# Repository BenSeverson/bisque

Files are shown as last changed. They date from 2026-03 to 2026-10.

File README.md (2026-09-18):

<p align="center">
  <picture>
    <source media="(prefers-color-scheme: dark)" srcset="docs/logo-banner-dark.svg" />
    Bisque — Open-source ESP32-S3 ceramic kiln controller
  </picture>
</p>

<p align="center">
  
  
  
</p>

<p align="center">
  <a href="https://benseverson.github.io/bisque/"><b>▶ Try the live web UI demo</b></a> — interactive, no hardware required
</p>

## Features

**Temperature Control**
- PID controller with auto-tuning (Ziegler-Nichols relay method)
- 1-second control loop with time-proportional SSR output
- Thermocouple calibration offset

**Firing Profiles**
- Up to 20 custom profiles with 16 segments each (ramp rate, target temp, hold time)
- Orton cone firing (cones 022-13) with slow, medium, and fast heating speeds
- Delayed start

**Safety**
- Over-temperature protection (hardware max 1400 C, user-configurable limit)
- Thermocouple fault detection (open circuit, short to GND/VCC)
- Rate-of-rise monitoring (detects runaway >2x programmed rate)
- Not-rising detection (alerts if <10 C rise in 15 min)
- Emergency stop with immediate SSR cutoff

**Web Dashboard**
- Real-time temperature chart with profile overlay (React + Recharts)
- Profile builder with cone fire mode
- Firing history with CSV trace export and cost estimation
- Settings: calibration, safety limits, webhooks, API token

**iOS App**
- Full remote control (SwiftUI)
- Finds the kiln on your Wi-Fi automatically (Bonjour), no IP address to type
- Dynamic Island live activities during firing
- Local notifications for firing complete/error

**LCD Display**
- 4.0" TFT (480x320) with LVGL, adaptive single-screen dashboard (idle/active/paused/complete/error)
- 5-way nav switch (up/down/select/left/right), SELECT-driven modals for profile pick and firing control

**Connectivity**
- Wi-Fi with mDNS (`bisque.local`)
- REST API with optional bearer token auth
- WebSocket for real-time streaming
- Webhook notifications (firing complete/error)

## Screenshots

**Web Dashboard** (React)
<p align="center">
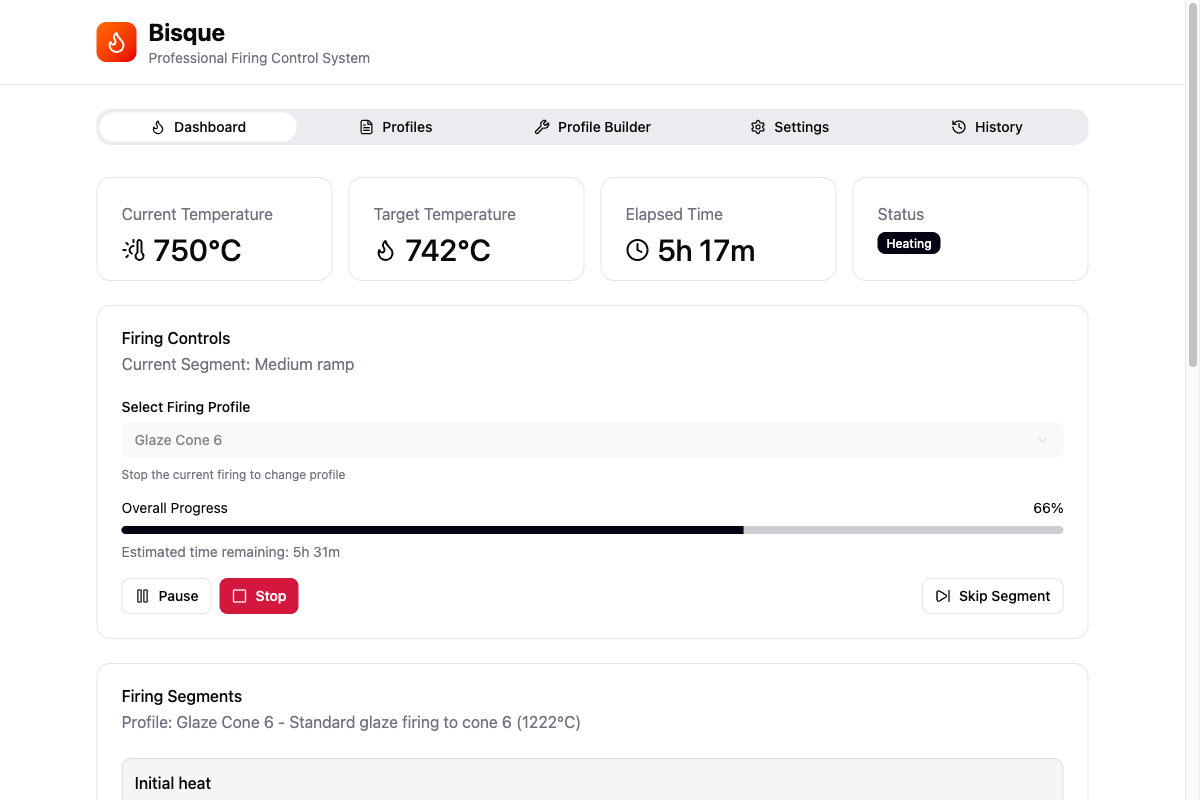
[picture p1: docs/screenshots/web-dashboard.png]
Web dashboard showing live firing progress
  
</p>

**LCD Display** (LVGL on 4.0" TFT)
<p align="center">
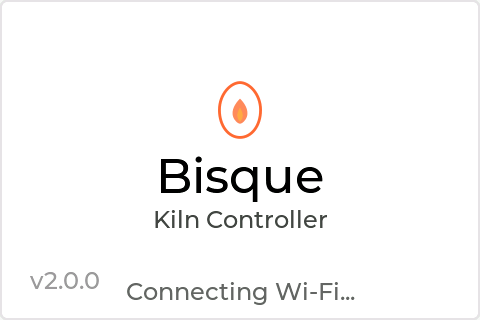
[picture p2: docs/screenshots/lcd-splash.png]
Boot splash
  
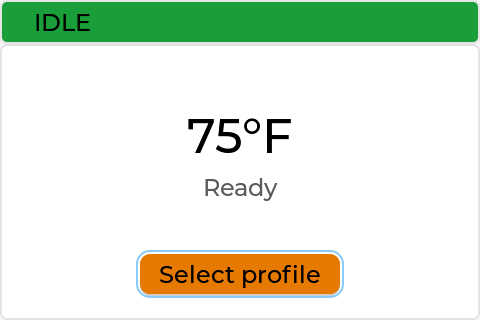
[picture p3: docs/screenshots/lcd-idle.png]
LCD idle
  
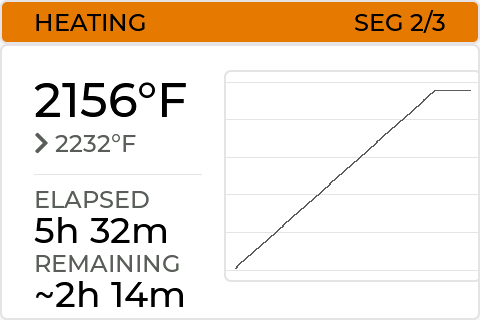
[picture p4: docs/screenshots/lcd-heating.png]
LCD heating
  
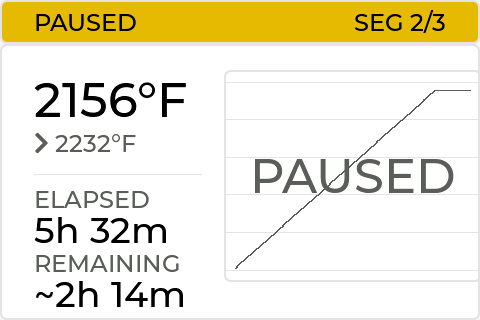
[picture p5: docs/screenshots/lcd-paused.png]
LCD paused
  
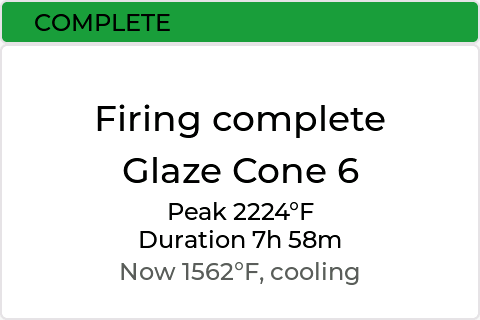
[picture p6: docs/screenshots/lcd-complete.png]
LCD complete
  
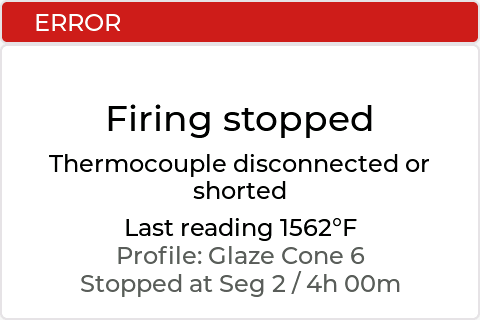
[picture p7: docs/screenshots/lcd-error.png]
LCD error
  
</p>
<p align="center">
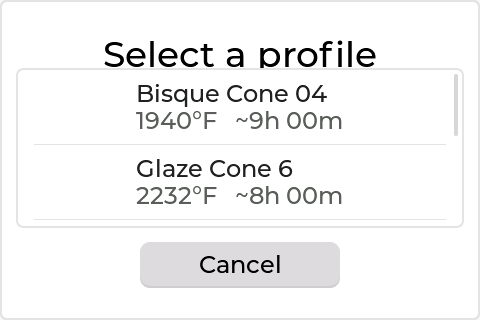
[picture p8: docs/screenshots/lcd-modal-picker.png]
Profile picker modal
  
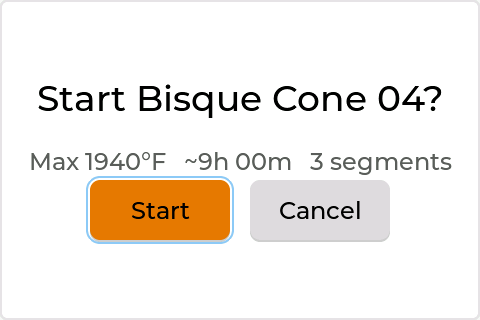
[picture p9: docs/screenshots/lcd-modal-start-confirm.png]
Start confirm modal
  
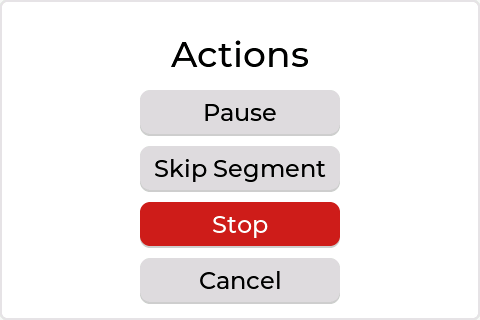
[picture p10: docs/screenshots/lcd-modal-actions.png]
Action menu modal
  
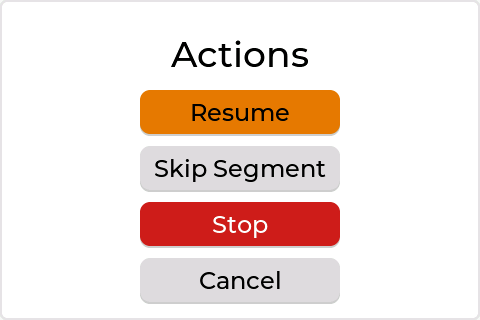
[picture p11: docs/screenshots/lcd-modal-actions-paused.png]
Action menu modal (paused)
  
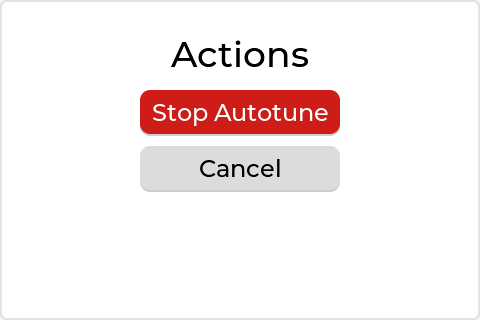
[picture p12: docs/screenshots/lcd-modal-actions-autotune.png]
Action menu modal (autotune)
  
</p>

**iOS App** (SwiftUI)
<p align="center">
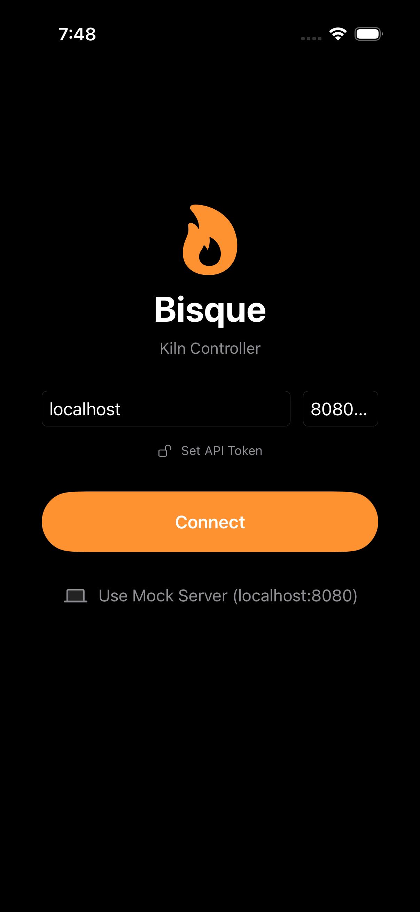
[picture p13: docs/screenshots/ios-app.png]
iOS app
  
</p>

## Hardware

The controller is a single board in [`hardware/kicad/`](hardware/kicad/) — a full KiCad project (schematic + routed **4-layer** board, 100 × 100 mm). Its GPIO map is [`docs/pin-assignments.md`](docs/pin-assignments.md).

<p align="center">
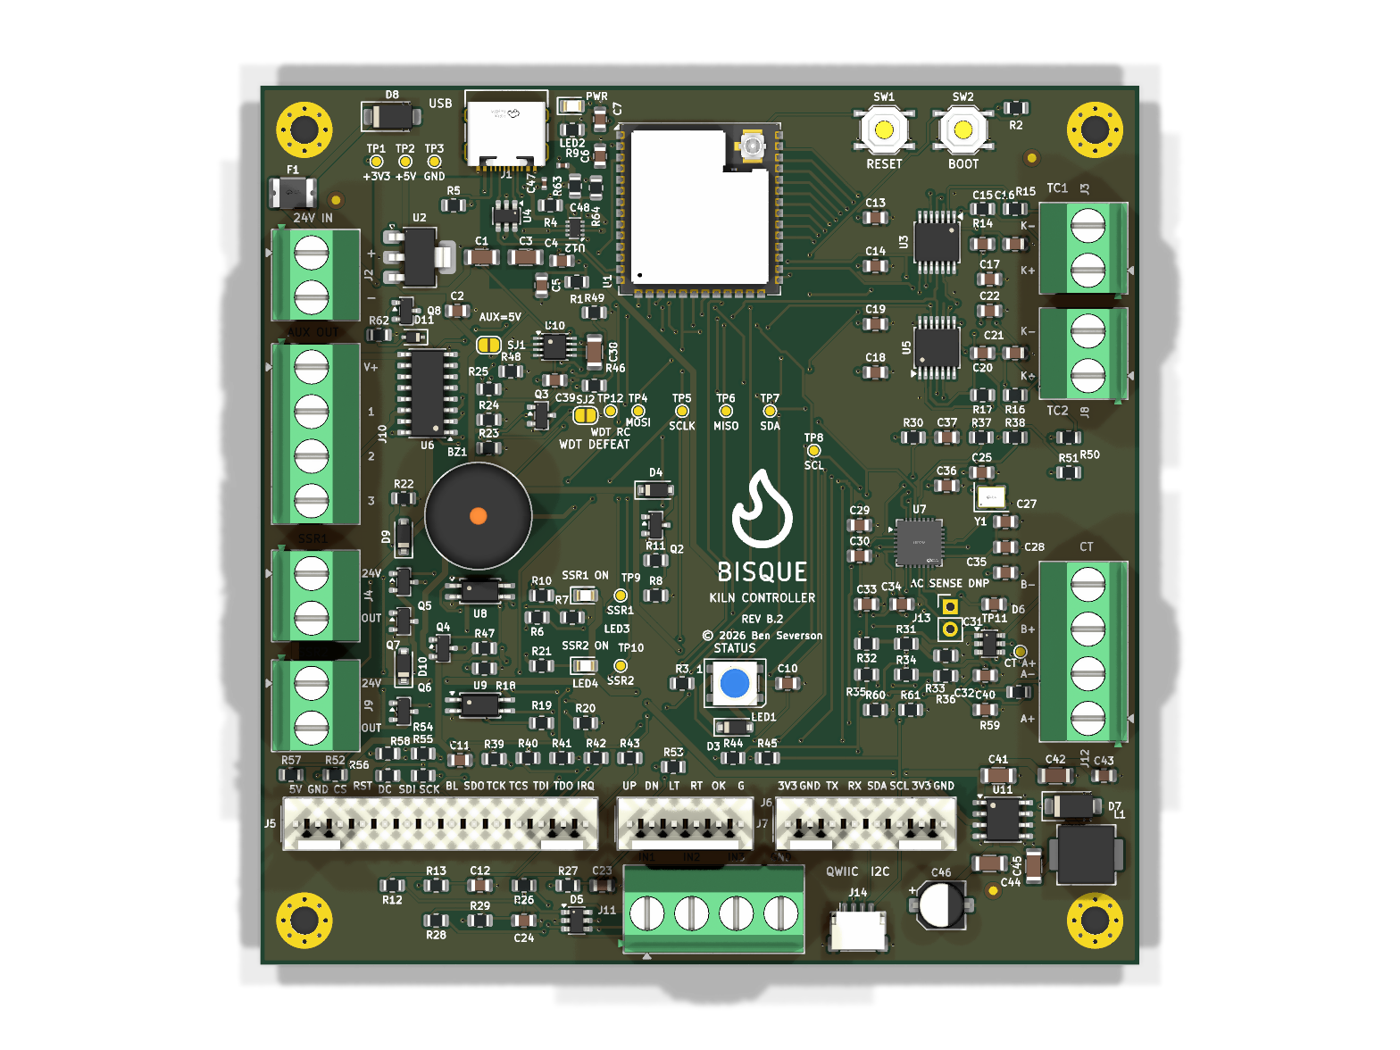
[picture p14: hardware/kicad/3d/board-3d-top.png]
Raytraced top-down render of the Bisque controller PCB
  
</p>

It integrates the ESP32-S3-WROOM-1U module (external U.FL antenna), two MAX31856 thermocouple front-ends, two SSR drive channels behind a hardware watchdog, an ADE7953 current-sense front-end, a ULN2003 auxiliary output bank, three protected dry-contact inputs, USB-C flashing, status LED, and alarm buzzer — with screw terminals for the field wiring and keyed connectors for the display and nav-switch looms. Gerbers, drill files, and an assembly BOM/CPL are committed and ready to upload to a board house.

See [`hardware/kicad/README.md`](hardware/kicad/README.md) for the full BOM, fabrication notes, and the regeneration workflow. GPIO assignments mirror the firmware's `Kconfig` defaults, so stock firmware runs unmodified.

[`hardware/enclosure/`](hardware/enclosure/README.md) documents a complete enclosure build around an off-the-shelf wall-mount steel box — layout, SSR thermal sizing, mains/SELV segregation, and a printable 1:1 drill template for the door.

> **Safety warning:** Kilns operate at dangerous temperatures and voltages. Ensure all high-voltage wiring is performed by a qualified electrician. Use appropriate safety equipment and never leave a firing kiln unattended.

## Getting Started

### Prerequisites

- [ESP-IDF v6.1](https://docs.espressif.com/projects/esp-idf/en/v6.1/esp32s3/get-started/)
- Node.js 18+
- [XcodeGen](https://github.com/yonaskolb/XcodeGen) (for iOS development)

### Dev Container (recommended)

The fastest way to a reproducible toolchain is the VS Code dev container — it
pins the exact ESP-IDF v6.1 image CI uses plus Node 24, the static-analysis
tools, and the Claude Code CLI. Open the repo in VS Code and run **Dev
Containers: Reopen in Container**. Everything below (firmware build, web UI,
`make ci`) then works in the container terminal; only flashing needs a bench.
See [docs/devcontainer.md](docs/devcontainer.md).

### Firmware

```bash
# Build web UI assets first
cd web_ui && npm install && npm run build && cd ..

# Gzip assets for SPIFFS
gzip -k -9 spiffs_data/www/assets/*.js spiffs_data/www/assets/*.css

# Build and flash firmware
source ~/.espressif/v6.1/esp-idf/export.sh
idf.py build
idf.py flash monitor
```

### Web UI Development

```bash
cd web_ui
npm install
npm run dev    # Starts dev server with mock kiln simulator
```

### iOS App

```bash
# Generate Xcode project
cd ios/Bisque
xcodegen generate
open Bisque.xcodeproj
```

For simulator testing, start the mock server first:

```bash
cd web_ui && npm run mock-server   # HTTP + WebSocket on localhost:8080
```

In the iOS simulator, tap "Use Mock Server" on the connection screen.

<details>
<summary><strong>Simulator / Mock Server</strong></summary>

A mock kiln server simulates the full API (status, profiles, firing, settings, history, autotune, diagnostics) with realistic temperature physics so you can develop and test without hardware.

### Web UI development

The mock server runs automatically as a Vite plugin when you start the web UI dev server:

```bash
cd web_ui
npm run dev
```

The mock is enabled by default. To disable it and proxy to a real kiln instead:

```bash
VITE_MOCK=false npm run dev
```

Control simulation speed with `VITE_MOCK_SPEED` (default `60` = 60x real-time):

```bash
VITE_MOCK_SPEED=120 npm run dev
```

### iOS app development

A standalone mock server is available for testing the iOS app in the Xcode simulator:

```bash
cd web_ui
npm run mock-server
```

This starts an HTTP + WebSocket server on `localhost:8080`. To change the port or simulation speed:

```bash
MOCK_PORT=9000 MOCK_SPEED=120 npm run mock-server
```

### LCD Simulator

A standalone SDL2-based simulator renders the LVGL display UI on your desktop:

```bash
cd simulator
cmake -B build && cmake --build build
./build/bisque_sim
```

Requires SDL2 (`brew install sdl2` on macOS).

</details>

## Architecture

```
main/                 App entry point, FreeRTOS task creation
components/
  app_config/         Pin definitions, hardware constants
  thermocouple/       MAX31856 SPI driver (2 channels)
  pid_control/        PID controller + Ziegler-Nichols auto-tune
  firing_engine/      Multi-segment firing state machine
  safety/             Watchdog, over-temp, fault detection
  cone_table/         Orton cone temperature lookup (022-13)
  history/            Firing history + temperature traces (NVS)
  display/            ST7796S LCD + LVGL UI (adaptive dashboard)
  web_server/         REST API + WebSocket server
  wifi_manager/       Wi-Fi STA/AP + mDNS
web_ui/               React/TypeScript web dashboard
ios/Bisque/           SwiftUI iOS app
simulator/            LVGL SDL2 desktop simulator
tests/host/           Pure-logic + accelerated firing unit tests (CMake/Unity)
docs/                 Wiring diagrams, screenshots, bench smoke test
```

## Testing

CI runs five automated test layers on every PR — pure-logic unit tests
and accelerated firing scenarios (`tests/host/`), a UI screenshot
regression suite (`simulator/ --diff`), web UI unit tests, and a
cross-language API contract test that validates firmware JSON output
against the frontend's zod schemas.

Before tagging a release, run the [bench smoke test](docs/bench-smoke-test.md) — a 3-8 minute hardware
run that verifies the parts CI can't touch: real SSR clicks, real
thermocouple readings, history persistence across reboot.

## Network security

**Bisque assumes the network it sits on is trusted.** It is a LAN-only
device: the HTTP API and the WebSocket telemetry feed are plain `http://`
and `ws://`, with no TLS. Anyone who can see traffic on the same Wi-Fi can
read the API token and every command sent with it.

The optional API token (Settings → API Token) is therefore a lock on the
front door, not protection against a hostile network. It stops a
housemate's laptop or a curious guest from starting a firing; it does not
stop someone who is already capturing your Wi-Fi traffic. Concretely:

- The token is sent as an `Authorization: Bearer` header on every REST
  request and compared in constant time on the device.
- The WebSocket telemetry feed (`/api/v1/ws`) is authenticated by the same
  check as the REST API. Browsers cannot set headers on a WebSocket
  handshake, so the web UI presents the token as a `?token=` query
  parameter instead — which means that on this one route the credential does
  reach anywhere the URL does, including proxy logs and browser history. The
  iOS app uses `URLSession`, which can set the header, and does. Dropping the
  query parameter would lock every browser out of live telemetry, so it is a
  deliberate trade rather than an oversight.
- Firmware updates are fetched over HTTPS with certificate validation
  against the bundled root store, and the downloaded image is checked
  against the SHA-256 in the release manifest. So an OTA is not exposed by
  the local network being readable — its trust rests on GitHub's TLS, not on
  your LAN.

If that trust assumption does not hold for your network, put the kiln on an
isolated VLAN or guest SSID rather than relying on the token. TLS on-device
with certificate pinning in the clients has been considered and is tracked
in [#149](https://github.com/BenSeverson/bisque/issues/149); it is a
significant amount of firmware and app complexity for a home LAN, and has
not been implemented.

**Never expose a kiln controller directly to the internet.** No port
forwarding, no DMZ. This is a device that applies mains power to a heating
element in an unattended room.

## Releases

Firmware is distributed as [GitHub Releases](https://github.com/BenSeverson/bisque/releases),
each with a full ESP32-S3 flash kit and Sigstore build-provenance
attestations. See [RELEASING.md](RELEASING.md) for the versioning scheme and
the procedure for cutting a release.

## License

[MIT](LICENSE)

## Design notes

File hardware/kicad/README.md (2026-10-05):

# Bisque Kiln Controller — KiCad PCB

The controller board. This is **rev B**, a respin of the original prototype
rather than a variant — it replaced the thermocouple front-end with an
incompatible part, added a second SSR zone and a digital current-sense chip,
moved most GPIOs, and swapped the module variant.
4-layer, 100 × 100 mm, built for **JLCPCB assembly**: 0805 passives,
QFN/TSSOP/SOIC/SOT ICs, SMD tact switches and the ESP32-S3-WROOM-1U module's
castellated pads all go down the SMT line, plus thirteen through-hole parts
(terminals, wafers, buzzer) fitted by hand — see "Fabrication & assembly"
below for why that split is much cheaper than it looks. The design record for
this respin, including the routing escalation that forced the layer count,
is `docs/superpowers/specs/2026-08-10-pcb-rev-b-hardware-design.md`; the
fab-readiness sign-off is `FAB-READINESS-REVIEW-REVB.md`.

Built and validated with **real KiCad** (10.0.5, pcbnew Python API +
kicad-cli): footprints come from KiCad's installed libraries, ground/power
plane pours are filled and checked by `kicad-cli pcb drc --refill-zones` —
**zero errors, zero unconnected, zero warnings**
(`bisque-controller-drc.rpt`) — and the schematic passes a netlist round-trip
check (KiCad's exported netlist diffed against the design's connectivity
table — 92 nets, 0 mismatches). The 3D renders in `3d/` are raytraced by
`kicad-cli pcb render` with the official component models.

| File | What it is |
|---|---|
| `bisque-controller.kicad_pro` | Project. Hand-maintained **except** two blocks, both derived and both written *after* the board is saved because `pcbnew.SaveBoard()` blanks them: `schematic.top_level_sheets` (`gen_sch.py::sync_project()`) and `net_settings` (`gen_pcb.py::sync_netclasses()`, from `ROUTE_ORDER`) — see below |
| `bisque-controller.kicad_sch` | Schematic (A1, netlist-style: functional groups, global labels for signals, real power ports for rails, and real wires for two-pin nets local to one block). Laid out programmatically by `generator/gen_sch.py` — a `GROUPS` taxonomy plus a deterministic column packer, with a reserved right-hand column for the notes block. A1, not A3: an A3 declaration silently clipped ~40% of the circuit out of the exported PDF while every connectivity checker stayed green (`generator/check_sch_bounds.py` now fails on any off-sheet item), and containment is not readability, so `generator/check_sch_layout.py` additionally fails on any symbol/symbol, text/symbol, text/text or wire/wire collision (wires: a T or a collinear overlap — a plain crossing is allowed) |
| `bisque-controller.kicad_pcb` | Board: placed, fully routed, 4 layers (F.Cu/B.Cu signals, In1.Cu GND plane, In2.Cu +3V3 plane), on JLCPCB's `JLC04161H-7628` 1.6 mm stack-up — see "The physical stack-up" |
| `bisque-controller.kicad_dru` | JLCPCB's standard 4-layer process as KiCad custom rules — **not generated**, and not a statement of design intent: every limit in it is JLC's *absolute minimum*, so a violation means something slipped off the design's own floor (0.3 mm track, 0.2 mm clearance, 0.6/0.3 vias, all from `net_settings`) far enough to hit the fab's. KiCad reads it by project name, so it survives regeneration untouched and the existing `kicad-cli pcb drc` pass picks it up for free — see "Fabrication & assembly at JLCPCB" |
| `3d/board-3d-*.png` | Raytraced renders, kicad-cli — straight orthographic **top** and **bottom** only. The angled iso/front views were dropped: they look better than they read, and these images get used to check placement and silk, not to advertise |
| `bisque-controller-drc.rpt` | KiCad DRC report, now including the `.kicad_dru` rules above (0 errors, 0 unconnected, 0 warnings — the 109 silkscreen warnings went with the silk packer, see "Regenerating the files") |
| `gerbers/` | Fabrication outputs (kicad-cli: F.Cu, B.Cu, **In1.Cu, In2.Cu**, paste/silk/mask, Edge.Cuts, Excellon drill + job file) |
| `pdf/` | Schematic and board PDFs (kicad-cli) |
| `jlcpcb/` | The complete JLCPCB upload: `gerbers.zip` for fabrication, BOM + CPL for assembly, plus the hand-solder shopping list and `mouser-order.csv` |
| `generator/` | Scripts that build everything from one connectivity table |

## Opening it

Open `bisque-controller.kicad_pro` in KiCad 10 or newer (the board file
format and pcbnew API this generator uses require it — see "Regenerating the
files"). Zones ship **filled** (KiCad's own filler) and the board already
passes KiCad DRC; re-run it after any edit. The schematic embeds its
symbols; the board references the standard KiCad footprint libraries (and
was generated from them), plus the four vendored models in `3dmodels/`.

**Opening the project used to dirty it.** KiCad records the root sheet under
`schematic.top_level_sheets` in the `.kicad_pro` and writes that block itself
the first time anything touches the project — and what it writes depends on
who wrote it. The GUI knows the schematic's real root uuid; `kicad-cli pcb`
fills all-zeros, because the PCB tooling never loads a schematic and has no
uuid to record. So the file grew an unexplained diff after a regen and could
flip between two values depending on which tool ran last.

`project_sync.py::sync_project()` (shared by `gen_sch.py` and `kicad_build.py`) now derives the entry from the same `ROOT`
constant the schematic's own `(uuid ...)` comes from, and runs on every
`pcb-build` / `pcb-cosmetic`. Whoever opens the project next finds it already
correct and leaves it alone — kicad-cli only ever *adds* the block when it is
missing and preserves a populated one, which is what makes deriving it
sufficient rather than a tug-of-war. The rewrite is a whole-file json
round-trip, safe because KiCad emits plain 2-space-indented JSON that
re-dumps byte for byte; do not replace it with a hand-rolled text patch.

## What's on the board

- **U1 — ESP32-S3-WROOM-1U-N16R2** module (16 MB flash / 2 MB **quad**
  PSRAM — matches `sdkconfig.defaults`' `CONFIG_SPIRAM_MODE_QUAD` + the
  16 MB OTA partition table), at the top edge. The **1U** variant carries a
  **U.FL connector for an external antenna** rather than the standard
  WROOM-1's on-package PCB antenna: a kiln controller mounts on or near a
  large grounded steel enclosure, which makes a PCB antenna close to
  non-functional, and the 1U's antenna can be placed on a pigtail somewhere
  that actually radiates. It also reclaims the ~330 mm² antenna keep-out
  band the WROOM-1 footprint would require — freed for parts and ground
  pour on a board that turned out to need every square millimeter (see
  "Density and the 4-layer stack-up" below). **The U.FL pigtail (U.FL → SMA
  bulkhead) and the 2.4 GHz antenna are accessories, not BOM lines** — buy
  them separately (see the hand-solder/shopping-list note below) and drill
  an SMA bulkhead hole in the enclosure. U.FL is rated for ~30 mating
  cycles, so treat the connection as assemble-once, not a field-serviceable
  connector.

  **Certification caveat.** Espressif's modular certification for the
  WROOM-1U is granted against specific antenna types and gains. Fitting a
  non-approved (e.g. high-gain) antenna steps outside that approval — see
  `CERT-001` in `FAB-READINESS-REVIEW-REVB.md`. Use an antenna within the
  certified list unless you're prepared to re-certify.

- **Power**: 24 V DC in on screw terminal **J2** (top-left) *or* USB-C.
  The 24 V side runs J2 → F1 (750 mA/33 V resettable fuse) → D8 (SMAJ30A TVS)
  → **Q8** (AO3401A P-FET, reverse polarity) → **U11**, an XL1509-5.0 buck in
  the south-east corner that makes `BUCK_5V`; **U12** (TPS2116) then selects
  between `BUCK_5V` and USB VBUS to make `+5V`, and a **TLV1117LV33**
  (U2, SOT-223) drops that to 3V3.
  Regulating rather than dropping is the point: +5V used to be literally the
  input minus a Schottky, so every diode drop and every turn of the
  installer's trim pot landed on the WS2812B threshold, the SSR drive and the
  relay coil at once. Both of the board's remaining series diodes are now
  gone with it — the reverse-polarity SS34 is Q8 (~39 mV instead of ~0.4 V,
  which matters because `VIN_P` feeds both 24 V SSR terminals as well as the
  buck) and the USB ORing SS34 is U12 (~40 mΩ).

  **U12 runs in priority mode, not highest-voltage-wins, and that is the
  whole reason it is a mux and not an ideal diode.** A 5.25 V USB host is
  higher than a 5.0 V buck, so a plain ORing part would let a laptop source
  the relay bank and both SSR terminals; the diode used to prevent that for
  free by dropping. MODE ties to VIN1 and R63/R64 divide `BUCK_5V` into PR1
  with a 4.0 V threshold, so the buck wins whenever it is up. U12 also
  blocks USB back-feeding the unpowered buck, which closes fab-review
  finding **C1** (5 V on U11's FB and switch pins during every USB-only
  flashing session). Its ST pin is left unconnected on purpose — see
  `design.py` at U12 for why that GPIO is not worth the route.

  `BUCK_5V` and `+5V` are deliberately separate nets: C44/C45/**C46** are the
  buck's compensation (C46 is the electrolytic supplying the ESR zero) and
  belong on the buck's side of the mux, not the load's.
  Power LED (green) on 3V3. The display (below) draws from +5V directly, not
  through U2 — its backlight and panel logic were the dominant unmodeled load
  on the LDO, and moving them off keeps U2's junction temperature comfortably
  under its 125°C limit even at a hot enclosure ambient. The +3V3 rail also
  now lives on its own **inner plane** (In2.Cu) rather than a surface pour —
  see the stack-up note below.
- **Thermocouples ×2**: **MAX31856MUD+** (U3 channel 1 / U5 channel 2,
  TSSOP-14), K-type on screw terminals **J3** (channel 1) / **J8** (channel
  2), each with its datasheet-specified differential + common-mode input
  filter, sharing the SPI bus (MISO + its own CS: GPIO 10 / GPIO 35). This
  replaces rev A's single MAX31855KASA+ entirely — the two parts are not
  pin-compatible, and no attempt was made to support both on one board.

  **Ungrounded-junction thermocouple probes are required.** Both MAX31856s
  reference their T− input to board ground. Two grounded-junction probes
  sharing one kiln chamber would form a ground loop through the kiln body
  itself; use ungrounded-junction (isolated-tip) K-type probes on both
  channels. This is a documentation obligation, not something the board
  enforces electrically.
- **SSR drive ×2, 24 V opto-driven low-side MOSFET**: screw terminals **J4**
  (zone 1) / **J9** (zone 2), each **pin 1 = `VIN_P`** (24 V, fused and
  TVS-clamped, **always live**) and **pin 2 = the switched low side**
  (`SSR1_OUT` / `SSR2_OUT`). Per channel: GPIO → 220 Ω → the LED of an
  TLP291 (**U8** zone 1, **U9** zone 2) → GND; the opto's collector sits on
  `SSR_EN` (+5 V) and its emitter drives the gate of a **CJ2310** (**Q5** /
  **Q6**), a 60 V logic-level N-channel MOSFET, with a **10 kΩ gate pulldown**
  (R7/R20). Both channels return through **Q7**, a third CJ2310 that is the
  watchdog's gate (see below). An amber indicator LED + 4.7 kΩ sits across
  each terminal pair, so it lights only when the channel is actually
  conducting. **D9**/**D10** freewheel each terminal for inductive loads. The
  board supplies the SSR control loop. (The SSRs themselves and all mains
  wiring stay outside this board.)

  **Current budget, and it is a limit rather than a note.** F1 holds at
  750 mA and U11 takes ~250 mA of it, so the two channels share ~400 mA. Two
  SSR inputs plus their indicators is ~40 mA, a 10× margin; one small DC
  contactor coil per channel fits; two large ones do not.

  **The optocouplers are containment, not isolation, and that distinction is
  load-bearing.** Rev B opto-*isolated* both channels — dry-contact terminals,
  a four-layer pour keepout across the opto row, `SJ3`/`SJ4` to tie each
  collector to board +5 V, and `check_isolation.py` — and that was **reversed**
  before fab, because an optocoupler only isolates if the SSR control loop is
  powered from a supply that is *not this board*, and this board's is.
  **That reasoning still stands and is not being overturned.** These terminals
  are still board-powered, both sides still share `GND`, and there is still no
  pour keepout, no router keepout, no rule area and no `check_isolation.py`.
  Do not re-add any of them; read commit `93a31d7` first.

  What changed is the failure the parts are bought for. At 5 V, a channel
  MOSFET failing gate-to-drain put 5 V through 100 Ω into a GPIO and the
  ESP32's clamp survived it. At 24 V the same single failure puts ~240 mA into
  that clamp and takes the module with it. The opto removes the conductor: the
  only thing the MCU touches is an LED. It is also not more parts than the
  alternative — a gate-to-GND zener contains the same fault for the same one
  part per channel, but contains it *by conducting*, so it has to survive the
  fault to work and fails open silently.

  **The opto is a TLP291 in SOP-4, not the LTV-817S this started as, and the
  reason is geometry.** The SMD-DIP4 body is 12.04 mm across its courtyard;
  the corridor between `J4`/`J9` and the rest of the block is ~5.5 mm and has
  to carry both these parts and the four per-terminal legends (`24V`/`OUT`,
  each locked to its own screw's y and free only in x). A 12 mm opto leaves
  those legends nowhere to go, and they print on the terminal body — three
  `check_silk` failures that no amount of re-spacing fixes, because the
  corridor is simply too narrow. At 8.50 × 3.10 mm it opens to ~6.7 mm.
  It costs one Extended feeder where the LTV-817S was Basic, and buys 80 V
  `V_CEO` against 35 V, which is free margin on a 24 V board.

  The 220 Ω is sized against the ESP32's **guaranteed** `V_OH`
  (0.8 × VDD = 2.64 V), not against 3.3 V: the opto's CTR bin is only
  specified at `I_F` = 5 mA and falls off steeply below it, and 330 Ω at that
  corner gives 4.7 mA. 220 Ω gives 7.0 mA there, 5.6 mA with `V_F` also at
  its maximum, and 10.0 mA typical — half the ESP32's recommended source
  current.

  The collector sitting on the **5 V** rail rather than on 24 V is deliberate:
  an emitter follower into R7 saturates, so the gate lands at
  `5 V − V_CE(sat)` ≈ 4.8 V — set by the rail, not by the opto's CTR. Run the
  collector from 24 V instead and the gate goes to ~24 V, past the MOSFET's
  ±20 V `V_GS`, and you need a zener to get back to where the 5 V rail
  already was for free.

  **Hardware watchdog (`SJ2`, "WDT DEFEAT").** `SSR_EN` — since rev B.2 a
  +5 V **gate-drive** rail rather than the terminal supply — is supplied by
  Q4, a P-channel high-side MOSFET (AO3401A) whose gate node `SSR_PG` is held
  down by Q3, itself held on by **U10**, an SN74LVC1G123 retriggerable
  monostable driven from GPIO 36 (`WDT_KICK`); R47 (100 kΩ) pulls `SSR_PG` up
  as the fail-safe. `SSR_EN` feeds both opto collectors *and* Q7's gate, so
  when it collapses the channels open **two independent ways**: the optos lose
  their collector rail and Q7 loses its gate. **R18** (10 kΩ) is what makes
  that work — `SSR_EN` is Q4's *drain*, so with Q4 off nothing would define it
  and Q7's gate would float, which is the same fail-dangerous bug R49 exists
  to fix one node upstream.

  **Q7 is in the shared return, and it is not the "stacked low side" this
  design rejected.** The watchdog has to be able to open a channel whose
  MOSFET has failed *short* — the case a firmware-owned interlock cannot cover
  — so it stays in the load path. Keeping it on the high side at 24 V would
  need a 60 V P-channel switch (the only fee-free one at JLCPCB is a
  50 V/130 mA part that caps the terminals below their own current budget)
  plus a divider to hold its `V_GS` inside ±20 V off a rail that reaches 37 V
  while D8 clamps a sustained fault — putting the board's most safety-critical
  node on a divider referenced to the fault. Q7 does the same job with the
  same part as the channels and leaves U10/Q3/Q4/R47/SJ2 untouched in the 5 V
  domain. The rejected "topology A" made **Q3** the series element back when
  the charge pump could only lift its gate to 2.16 V, so its drop was
  unbounded; Q7 is a dedicated switch gated at ~5 V, where the CJ2310 is
  specified at 125 mΩ — 5 mV at 40 mA. The objection was to an unbounded drop,
  and this one has a datasheet line under it. **R22** (100 kΩ) pins `SSR_RTN`
  down so that with everything off it cannot drift to 24 V and put −24 V
  across Q5/Q6's gates. It is 100 kΩ rather than 10 kΩ because of the very
  fault the watchdog is in the load path *for*: with a channel MOSFET failed
  short and the window expired, R22 in series with the SSR's own ~1.2 kΩ
  input is all that is left, and 10 kΩ passes 2.1 mA — inside the trigger
  range of an SSR-40DA-class input. 100 kΩ passes 237 µA.

  Every **rising edge** on `WDT_KICK` restarts U10's window, so `Q` stays high
  only while firmware keeps kicking; a pin wedged at either level delivers no
  edge and expires the window exactly like a pin that stopped, which is the
  whole point. R46 (100 kΩ) and C38 (22 µF) set the window to **1.65–2.71 s**
  worst-case over −40…125 °C, every term of that bound a datasheet or
  purchase-tolerance figure. Firmware kicks at 5 Hz from the existing 100 ms
  SSR timer, gated on `safety_task`'s heartbeat
  (`components/safety/wdt_kick.h`) — 8.3× margin at the minimum window. R48
  (100 kΩ) holds `B` low whenever the MCU drives nothing, so a floating CMOS
  input cannot self-trigger the one-shot during boot ROM, flashing or reset.

  **This replaced a BAT54S diode charge pump, which did not work.** Solving its
  steady state exactly gives 0.63 V of gate drive at 5 Hz against Q3's 1.45 V
  threshold — and 0.84 V even in the typical corner, below the *typical* 1.0 V
  threshold. A faster kick (≥ 250 Hz) rescues the voltage but not the
  temperature behaviour: Schottky reverse leakage sits in the timing path and
  roughly doubles per 10 °C, so the budget for a transient firmware stall fell
  from 0.31 s at 25 °C to 0.11 s at 60 °C and vanished near 85 °C, next to a
  5 kW heat source. No choice of passives fixes a leak that *is* the timer;
  the fix was to stop building the timer out of one. Off-the-shelf watchdog
  supervisors (TPS3823, STWD100) were evaluated and rejected on output shape:
  they emit a fixed reset *pulse* per timeout, which would leave the heat rail
  energised 75–95 % of the time under dead firmware. They exist to reboot
  MCUs; gating a rail needs a level.

  On power-up, and on any board where nothing kicks GPIO 36, `SSR_EN`
  collapses and **both SSR channels stay off regardless of what the firmware
  commands them to do.** The silkscreened `SJ2` solder jumper shorts `SSR_PG`
  to GND, holding Q4 on and restoring un-gated behaviour for bring-up and for
  any build without the firmware kick. **A board with neither `SJ2` fitted nor
  a working kick will not heat** — this is the single most likely rev B
  bring-up surprise, more likely to be mistaken for a bad SSR or a
  lid-interlock problem than correctly diagnosed as "nobody is kicking the dog
  yet." `TP12` probes the timing node, which is where a scope settles the real
  window in one measurement. The watchdog gates only the two SSR channels;
  vent, purge, the spare aux channel and the buzzer are unaffected, so a
  stalled controller can still open its vent.
- **Display**: 14-pin Molex KK-254 friction-lock header **J5** for a 4.0"
  ST7796S SPI module (LCDWIKI MSP4021, 480×320, resistive touch) — grown
  from rev A's 8-pin display-only header to carry the panel's full pin set:
  the original 8 signal pins, the panel's `SDO` (pin 9, left unwired in rev
  A because the firmware never read from the display), and the five touch
  lines (pins 10–14). `T_CLK`/`T_DIN`/`T_DO` are electrically the shared
  SPI2 bus through 33 Ω series damping resistors (R39/R41/R42 — the bus now
  multi-drops the LCD at 40 MHz plus two MAX31856s and the touch controller
  at lower clocks); only `T_CS` (GPIO 5) and `T_IRQ` (GPIO 6) cost new
  dedicated GPIOs. The XPT2046 touch controller itself lives on the display
  module, not this PCB. VCC runs from +5V rather than +3V3, per the
  module's own manual and reference wiring diagrams, with no level shifter
  needed on CS/RESET/DC/MOSI/SCK.
- **Nav switch**: 6-pin KK-254 friction-lock header **J6** for the
  panel-mounted 5-way switch (`UP DN LT RT OK GND`, active-low, ESP32
  internal pull-ups) — now on GPIO 38–42, contiguous module pads, moved
  from the split GPIO 1/2/4/5/6 rev A used (routing simplification, see the
  hardware-design spec §3.1).
- **Aux header J7** (8-pin KK-254): `3V3 GND TX RX SDA SCL 3V3 GND` — UART0
  plus a 0.1" I2C tap (pins 5–8), alongside the Qwiic/STEMMA-QT connector
  **J14**. Rev A's `VENT`/`LID_SW`/`AUX_A`/`AUX_B` nets are gone from this
  header entirely: nothing on the board ever sourced `AUX_A`/`AUX_B` here
  (the real aux outputs are on J10, below), and the lid switch has its own
  terminal (J11).
- **Aux output bank — J10** (4-pin terminal): **AUX_VP** (external coil
  rail) plus three switched low sides (`AUX1_OUT` = vent, `AUX2_OUT`,
  `AUX3_OUT`), driven by a shared **ULN2003ADR** Darlington array (U6) with
  integrated freewheel diodes returning to `AUX_VP` — not the board's own
  +5V rail. A gas purge solenoid is realistically 12 V or 24 V DC; the
  ULN2003 is rated 50 V / 500 mA per channel, so `AUX_VP` is meant to be fed
  from an external coil supply. Solder jumper **`SJ1`** (open by default)
  ties `AUX_VP` to board +5V for anyone who only has plain 5V relays. Only
  channel 1 (vent) is driven by firmware today (`safety_update_vent()`);
  channels 2/3 are routed and declared in Kconfig (`KILN_PIN_AUX2`/`AUX3`)
  but undriven.
- **Protected inputs — J11** (4-pin terminal): `IN1`/`IN2`/`IN3` (lid, gas
  flow, spare) plus GND, each with the same conditioning rev A used for its
  single lid input — 1 kΩ series, 10 kΩ pull-up to 3V3, 100 nF to ground,
  dry-contact to GND — generalized to three channels. `IN1` (GPIO 4) is the
  lid switch and defaults to enabled, matching this board; see
  `docs/pin-assignments.md` §1 for the fail-safe wiring requirement if no
  switch is fitted. `IN2` (gas flow) and `IN3` (spare) are routed but have
  no firmware consumer yet.
- **CT current sensing — J12** (4-pin terminal, `CTA_P`/`CTA_N`/`CTB_P`/
  `CTB_N`): two current-transformer inputs into an **ADE7953** energy
  metering IC (U7, LFCSP-28, current-only — the voltage channel is unused),
  on the I2C bus with its own 3.579545 MHz crystal (Y1). Burden resistors
  (R31/R34, 5.1 Ω — full scale ~139 A rms, see `design.py`), anti-alias RC
  and an SRV05-4 TVS array (D5/D6) per
  channel protect the externally-exposed CT leads. One channel per SSR
  zone, so each element bank gets an independent current reading; with no
  mains voltage sensing on this board, power is estimated as
  `Irms × configured nominal mains voltage` (±3–5%), adequate for
  element-health diagnosis and cost estimation. The voltage-channel pins
  are routed to a **DNP** 2-pin SELV header (**J13**) for a possible future
  off-board isolated-AC accessory — not fitted, no mains anywhere on this
  PCB.
- **I2C expansion — J7 pins 5–8 and J14 (Qwiic/STEMMA-QT)**: `I2C_SDA`
  (GPIO 18) / `I2C_SCL` (GPIO 47), on-board pull-ups (R44/R45, 4.7 kΩ).
  Carries the on-board ADE7953 today; open for an RTC breakout, an SHT4x RH
  sensor, or an external ADC without board changes. No I2C driver exists in
  firmware yet.
- **USB-C (J1)** for native-USB flashing: 5.1 kΩ CC resistors, SRV05-4 (U4)
  ESD protection, VBUS ORed into +5 V. RESET (SW1) and BOOT (SW2)
  buttons.
- **Status LED**: WS2812B on IO48; its VDD comes through a 1N4148W drop
  diode (D3), putting VLED at ≈4.15 V so V_IH = 0.7·VLED ≈ 2.9 V stays
  comfortably under the 3.3 V data level. The diode is *silicon*, not the
  SS14 Schottky it replaced, and the reason is the buck: on a regulated
  5.0 V rail an SS14's ~0.3 V leaves VLED at 4.7 V and V_IH at 3.29 V —
  a 10 mV margin. The old rail sagged enough to hide that. What the
  regulator removes is the trade, not the drop: VLED no longer moves with
  the PSU, so a fixed drop is now a real fix rather than a hedge.
- **Alarm**: 12 mm active 5 V buzzer (BZ1) on IO7, its own discrete AO3400A
  (Q2) low-side driver with flyback diode — kept separate from the ULN2003
  aux bank on purpose, so a 5 V buzzer and a 24 V solenoid never share a
  COM rail.
- **Test points**: twelve 1 mm bring-up pads (TP1–TP12, no BOM/assembly
  cost) on +3V3, +5V, GND, the SPI bus, I2C SDA/SCL, both SSR gate nets,
  the CT burden node, and the watchdog hold node. Rev A shipped with none,
  which its fab review flagged as awkward for bring-up; at ~141 components
  and eleven subsystems, they stopped being optional.
- 4× M3 grounded mounting holes, one per corner, centers on a **90 × 90 mm
  rectangle** (5 mm in from each edge, grown from rev A's 90 × 70 mm as the
  board grew from 100 × 80 mm to 100 × 100 mm) for easy enclosure drilling.

### Density and the 4-layer stack-up

Rev B roughly triples rev A's component count (52 → 141) on the same
100 × 100 mm footprint rev A used at 80 mm tall. `generator/router.py`'s
2-layer octilinear grid autorouter could not close the board: a rung-by-rung
escalation (0805 → 0603 passives, then a 125 × 100 mm board) knocked
unroutable nets down from 34 to 23 to 9, but the survivors were short local
nets boxed in by neighbours' copper in the SSR driver cluster and the
ADE7953 block — the signature of a **layer** shortage, not an area shortage.
Going 4-layer (an unbroken GND plane on In1.Cu, a +3V3 plane on In2.Cu — In2
carries +3V3 alone rather than splitting with +5V, since +5V's own consumers
don't fall into a separable region) closed the board at 0 unrouted nets and
0 DRC errors, and then gave back **every** concession the 2-layer attempts
had made: the board walked back to 100 × 100 mm, 0805 passives, and rev A's
0.3 mm signal / 0.7 mm power track widths — which the project file now really
does carry as net classes, derived from `ROUTE_ORDER` by
`gen_pcb.netclass_table()`; until that landed the widths existed only inside
the router and `.kicad_pro` held a single 0.2 mm `Default`, so opening the
board in KiCad to nudge one track handed you a width the board never uses.
Neither outer layer is poured —
on this density, the GND pour was the largest single consumer of routing
space on exactly the two layers the boxed-in nets needed to escape through.
Track widths came back too, because the router no longer touches fine-pitch
pads directly: each is represented by the far end of a pre-drawn escape
stub, so 0.25 mm tracks are confined to the ~2 mm around the QFN-28/TSSOP
pads that actually need them. See `FAB-READINESS-REVIEW-REVB.md` and
`docs/superpowers/specs/2026-08-10-pcb-rev-b-hardware-design.md` §6.3 for
the full measured escalation ladder.

Both planes run whole: there are **no rule areas** on this board. Rev B
carved a four-layer pour keepout across the SSR optocoupler row and had
`generator/check_isolation.py` confirm nothing landed in it; both went with
the opto-*isolated* design (see "SSR drive ×2" above), returning ~21 × 24 mm
of pour and routing area on every layer. **U8/U9 returning in rev B.2 did
not bring the keepout back** — they are a containment part on the gate drive,
in ordinary pour and routing area, and re-adding a rule area on their account
would re-introduce a cost for a barrier the board does not claim.

### The USB pair is routed as a pair, and first

`USB_DP`/`USB_DN` are the one impedance-controlled object on the board, and
`generator/router.py`'s A* knows nothing about pairs: it routes one net at a
time, never rips up, and takes whatever lane is free when the net's turn
comes. Left to that, the pair came out 50.8 mm against 33.2 mm, over 8 and 5
vias, with 0 % of either net running beside the other — the DRC's own
`diff_pair_uncoupled` measured 90.5 mm. So the pair gets its own router and
its own turn:

* **`Router.route_pair()`** finds the pair as ONE track of width
  `2 × 0.3 + 0.2 = 0.8 mm` down the centreline (so clearance is checked for
  the pair's whole envelope, with both nets' own copper exempt via
  `PairNet`), then splits it into two offset tracks and joins each to its
  terminal with a straight fan. Right angles in the centreline are chamfered
  *before* the split, so both tracks keep the same shape — `miter_corners()`
  would do it one track at a time, and that is how a matched pair picks up
  skew. Every fan is checked for clearance against the *other* net's pads and
  for crossing; an end that fails is struck off and the search re-run. No
  vias, one layer, and everything it draws is `fixed`. The first and last
  steps can be pinned (`first_dir`, `last_dir`): the lead-in already ends in
  a coupled straight, and a pair that met the module's pad row on a diagonal
  had its fans converge to 0.43 mm before opening — under clearance, and the
  checker said so.
* **It runs before plane vias or any signal exist** (`kicad_build.build_copper`),
  so the board is empty when it picks its lane and every other net routes
  around it. `USB_DP`/`USB_DN` are therefore not in `ROUTE_ORDER` at all.
* **The lead-in is drawn from the pad positions** (`gen_pcb.usb_pair_seeds`):
  J1's D+/D- pads interleave at 0.5 mm pitch, so the two lines leave the
  connector 1.5 mm apart, jog onto U4's outer pad columns 1.9 mm apart, run
  straight through both pads of each column — the SRV05-4 is placed as a
  **flow-through**, each line on two of its independent channels (see U4 in
  `design.py` for why a stub-connected TVS cannot be reached by a coupled
  pair at all) — and only then converge to the coupled pitch. The funnel is
  shaped so the two vias the TVS's middle column needs (pin 2's plane via
  north of the part, VBUS to pin 5 south of it) each have a slot.
* **`generator/check_usb_pair.py`** holds it there, in CI: one piece of
  copper per net, no vias, F.Cu only, skew ≤ 3.5 mm pad to pad, at most
  16 mm of either net uncoupled and at least 40 % coupled. Measured on the
  board this landed on: 25.1 / 22.6 mm J1 → U1, 0 vias, 14.1 / 13.6 mm
  coupled, 2.5 mm skew — 2.4 mm of which is the funnel, the outer line
  travelling the 1.9 mm column offset the inner one does not (~18 ps against
  a Full-Speed bit of 83 ns). The `.kicad_dru` now enforces
  `diff_pair_uncoupled` too, at a budget set from the same board.

### Two escapes are written down rather than routed

`generator/gen_pcb.py` carries two tables of hand-seeded copper —
`USB_SEEDS` for J1's D+/D- links and CC lines (the pair's own escapes come
from `usb_pair_seeds()`), and **`ADE_I2C_SEEDS` for the ADE7953's SDA and
SCL**. Both exist for the same reason: a lane one track wide, in a place the
greedy router's answer is not stable.

U7's I2C pins leave a 0.5 mm-pitch QFN into the densest neighbourhood on the
board (2.30 parts/cm², with every escape from a 28-pin part passing through
it). Their fanout stubs end with two and six free grid nodes; whichever net
gets there first takes the only lane and the other cannot get in. The
committed board routes both, but that is a fixed point rather than a
property — six unrelated placement changes elsewhere re-rolled it, and it
cost first one net and then the other over five full re-routes. Promotion
does not help, which is the tell: `I2C_SDA` failed at (94.50, 68.00) even
when routed **first**, before any other signal existed.

So the two lanes are recorded, read back off the board from a run that did
succeed. Two properties are load-bearing:

* **`MANUAL_VIAS` carries SCL's drop to B.Cu.** `via_ok` is false at both
  stub ends — there is no room for a via pad beside a 0.5 mm-pitch escape —
  so the router cannot place it for itself.
* **The far end of a seed must be the net's terminal** (`ADE_I2C_TERMS`,
  exactly as `USB_STUB_TERMS` does for J1). Seed the lane without moving the
  terminal and the router is still free to reach the fanout stub the short
  way: it did, both nets came out electrically complete, and the seeds were
  left hanging off the stubs as 2.5 mm and 8.8 mm of dangling copper. The
  same trap caught `USB_DP`, whose escape seed overshot its own branch point
  by 0.5 mm after a re-route — a seed should end where the escape ends.

### The physical stack-up, and the one impedance target

The board declares **JLCPCB's default 4-layer 1.6 mm press,
`JLC04161H-7628`** — the table is `generator/gen_pcb.py`'s `STACKUP`, written
into the file by `apply_stackup()`.

| Layer | Type | Material | Thickness | ε_r |
|---|---|---|---|---|
| F.Cu | copper, 1 oz | | 0.035 mm | |
| dielectric 1 | prepreg | NP-155F 7628 | 0.2104 mm | 4.4 |
| In1.Cu — GND | copper, ½ oz | | 0.0152 mm | |
| dielectric 2 | core | NP-155F Core | 1.065 mm | 4.43 |
| In2.Cu — +3V3 | copper, ½ oz | | 0.0152 mm | |
| dielectric 3 | prepreg | NP-155F 7628 | 0.2104 mm | 4.4 |
| B.Cu | copper, 1 oz | | 0.035 mm | |

It carried no stack-up at all until this was added, and that is worse than
it sounds. A `.kicad_pcb` with no `(stackup ...)` is perfectly valid and
passes every checker here, but it declares no dielectric heights and no ε_r,
so anything computing impedance off the file computes it against a KiCad
placeholder — and the placeholder is not close. The exported **gerber job
file was the visible casualty**: `bisque-controller-job.gbrjob` shipped
`"Thickness": 0.48, "Material": "FR4"` for every dielectric, i.e. it told the
fab a stack-up that does not exist. It now carries the real materials and
`"ImpedanceControlled": true`.

The board has exactly **one** impedance target: USB 2.0 Full Speed, 90 Ω
differential (`USB_DP`/`USB_DN`, J1 → U4 → U1; there is no RF trace, the
WROOM-1U keeps its radio and U.FL on-module). On this press the pair as
already routed — 0.3 mm wide, 0.2 mm gap, microstrip over the In1.Cu GND
plane through 0.2104 mm of 7628 prepreg — computes to **93.1 Ω differential
(+3.5 %)**, inside JLCPCB's ±10 % window, which is why declaring the
stack-up needed no re-route. That is a property of *this* press: JLCPCB's
thinner-prepreg 1.6 mm options put the same copper at 75 Ω (2116), 70 Ω
(3313) or 61 Ω (1080). `generator/check_pcb.py`'s check 5 fails on any of
them rather than letting the swap pass silently.

Two things would also move it, neither of which is on the board today: a GND
pour on F.Cu or B.Cu (coplanar coupling drops the pair to 79 Ω at the default
0.2 mm clearance — the outer pours are held off by a keepout derived from the
pair's own bounding box, `kicad_build.usb_keepout()`), and re-routing the
pair at a different width or gap. The pair IS routed coupled at that geometry
from the TVS to the module (see "The USB pair is routed as a pair, and
first"); the stretches that are not — J1's 0.5 mm pad pitch, the
flow-through under U4, the fan into the module's 1.27 mm pitch — are the
connector's and the parts' geometry, and `check_usb_pair.py` budgets them.

### GPIO map (mirrors `main/Kconfig.projbuild` defaults)

| GPIO | Function | | GPIO | Function |
|---|---|---|---|---|
| 11/13/12 | SPI MOSI/MISO/SCLK | | 38/39/40/41/42 | NAV up/down/left/right/select |
| 10 / 35 | TC1 / TC2 CS (MAX31856) | | 48 | WS2812B data |
| 8/9/46/3 | LCD CS/DC/RST/BL | | 7 | Alarm buzzer |
| 17 / 21 | SSR1 / SSR2 MOSFET gate | | 14/15/16 | AUX1 (vent) / AUX2 / AUX3 (ULN2003, J10) |
| 19/20 | USB D−/D+ | | 43/44 | UART0 TX/RX (J7) |
| 4/2/1 | Protected inputs IN1 (lid) / IN2 (gas flow) / IN3 (spare), J11 | | 18/47 | I2C SDA/SCL |
| 5/6 | Touch T_CS / T_IRQ | | 36 | Watchdog kick (`SJ2` defeats it) |
| 37 | spare | | | |

Full table with module pin numbers, nets and per-pin notes:
[`docs/pin-assignments.md`](../../docs/pin-assignments.md) §1.

## Bill of materials

141 components, 92 nets. Full machine-readable BOM: `jlcpcb/BOM.csv` (40
lines covering 109 machine-placed parts) plus `jlcpcb/hand-solder-parts.csv`
(13 hand-fitted parts). Selected parts worth calling out:

| Ref | Value / Part | Package |
|---|---|---|
| U1 | ESP32-S3-WROOM-1U-N16R2 | castellated module, U.FL |
| U2 | TLV1117LV33 | SOT-223 |
| U3, U5 | MAX31856MUD+T | TSSOP-14 |
| U4 | SRV05-4 TVS array | SOT-23-6 |
| U6 | ULN2003ADR | SOIC-16 |
| U7 | ADE7953ACPZ-RL | LFCSP-28 (QFN-28, 5×5 mm) |
| Y1 | 3.579545 MHz crystal | HC-49S-SMD |
| D5, D6 | SRV05-4 TVS array (same part as U4) | SOT-23-6 |
| U10 | SN74LVC1G123 retriggerable monostable | VSSOP-8 |
| Q2, Q3, Q5, Q6 | AO3400A N-MOSFET | SOT-23 |
| Q4 | AO3401A P-MOSFET (watchdog high-side switch) | SOT-23 |
| J1 | USB-C 16-pin receptacle | HRO TYPE-C-31-M-12 |
| J2, J3, J4, J8, J9 | Phoenix MKDS 1,5/2 (or clone) | 5.08 mm screw terminal, 2-pos |
| J10, J11, J12 | Phoenix MKDS 1,5/4 (or clone) | 5.08 mm screw terminal, 4-pos |
| J5 | Molex KK-254 friction-lock header 1×14 | 2.54 mm THT |
| J6 | Molex KK-254 friction-lock header 1×6 | 2.54 mm THT |
| J7 | Molex KK-254 friction-lock header 1×8 | 2.54 mm THT |
| J13 | 2-pin header, **DNP** (AC-sense SELV, not fitted) | 2.54 mm THT |
| J14 | JST SH SM04B-SRSS-TB | Qwiic/STEMMA-QT, 1 mm SMD, **side entry** — pinned to the bottom edge so the cavity faces off-board |
| BZ1 | active buzzer 5 V | 12 mm THT, 7.6 mm pitch |
| SW1, SW2 | XKB TS-1187A tactile switch | 5.1 × 5.1 mm SMD |
| H1–H4 | M3 mounting hole, grounded, 90 × 90 mm grid | — |
| SJ1, SJ2 | Open solder jumpers (`AUX_VP←+5V`, `WDT DEFEAT`) | populated with solder, not a part |
| TP1–TP12 | 1 mm bring-up test pads | bare copper, no BOM cost |

**Off-BOM accessories (not in `jlcpcb/`, buy separately):** a U.FL → SMA
bulkhead pigtail and a 2.4 GHz antenna for U1 (~$3–5), plus an enclosure
SMA bulkhead hole. See the certification caveat above before choosing a
non-stock antenna.

## Fabrication & assembly at JLCPCB

The board needs JLCPCB's **4-layer** capability (rev A's 2-layer board did
not; see "Density and the 4-layer stack-up" above) but stays inside the
≤100 × 100 mm promo size tier either way:

| Parameter | This board | JLCPCB 4-layer limit |
|---|---|---|
| Size | 100 × 100 mm | ≤ 100 × 100 mm for the promo price |
| Min track width | 0.25 mm (fine-pitch escape stubs only) | 0.127 mm |
| Min clearance | 0.20 mm | 0.127 mm |
| Via | 0.6 mm / 0.3 mm drill | 0.4 mm / 0.3 mm |
| Min PTH drill | 0.3 mm (vias) | 0.3 mm |
| Copper-to-edge | ≥ 0.3 mm | 0.2 mm |
| Layers / finish | 4 (F.Cu/In1.Cu GND/In2.Cu +3V3/B.Cu), **ENIG**, 1.6 mm, green | ENIG is a paid option, not the default |

Two of those are order-form choices rather than board content, and the board
file is the one that states them: `gen_pcb.py` writes **ENIG** into the
stack-up (`copper_finish`), and `kicad-cli` copies it into
`gerbers/bisque-controller-job.gbrjob` as `"Finish": "ENIG"` — but JLC takes
the finish from the order form, so **select ENIG when ordering** or the board
arrives HASL. ENIG was chosen deliberately: U7 is a 0.5 mm-pitch QFN-28 with a
3.1 mm exposed pad and HASL's crown is worst exactly under a large EP.

`"ImpedanceControlled": true` in the same file declares the stack-up the 93.1 Ω
figure is computed against; it is not an instruction to buy JLC's impedance-
control service. **Do not.** That service is a controlled-etch process with a
TDR coupon, priced accordingly, and this board does not need it: the one
target is USB 2.0 **Full Speed** (12 Mbps), the pair is short and now routed
coupled at the declared geometry, and 93.1 Ω against 90 Ω is inside the ±10 %
an uncontrolled stack-up already holds.

### Checking against JLC before ordering: `bisque-controller.kicad_dru`

JLCPCB itself ships nothing that plugs into KiCad's DRC. What it does offer is
[JLCDFM](https://jlcdfm.com/) — a free gerber-upload DFM/DFA analyser, the same
engine that runs automatically when you upload to
[the quote page](https://cart.jlcpcb.com/quote) — plus a
[PCBA viewer](https://jlcpcb.com/smt/dfm-result) that renders the BOM+CPL
placement so rotations can be eyeballed, and an approval-gated
[ordering API](https://api.jlcpcb.com). All of them are post-export: you learn
the answer after the gerbers exist.

`bisque-controller.kicad_dru` closes that gap by stating JLC's process as KiCad
custom rules, so `kicad-cli pcb drc` answers the question on every build. KiCad
picks the file up by project name, so it is a sidecar the generator never
touches — a full `make pcb-cosmetic` with it in place leaves the board and
schematic **byte-identical**.

**It encodes JLC's absolute minimums, not its recommendations, and on
silkscreen those differ by 25%.** The published community rule files
([labtroll](https://github.com/labtroll/KiCad-DesignRules) and its forks,
[tinfever's](https://github.com/tinfever/KiCAD-Custom-DRC-Rules-for-JLCPCB-with-Unit-Tests))
set `text_height` to 1.0 mm, which is JLC's *recommended* height, not its
capability — against this board that is **199 false violations**, which is how
a report gets ignored. JLC's
[character specification](https://jlcpcb.com/blog/character-design-specifications)
gives the standard font an absolute minimum of 0.8 mm at a 0.15 mm stroke
(ratio ~1:5 to 1:6) and a recommendation of 1.0 mm at 0.2 mm. So
`gen_pcb.TITLE_MIN_TEXT = 0.8` is right against the capability — but it is the
capability, exactly: 185 of this board's silk texts are at 0.8 mm, 13 at
0.9 mm, one at 0.894 mm, and 229 of them carry a 0.16 mm stroke, a 1:5.0 ratio
at the far edge of the stated range. That is a legibility question for a board
whose whole silk investment is 50 per-terminal legends, not a fab question, so
it is not enforced here.

The only other thing the board misses is JLC's 0.15 mm pad-to-silk clearance,
in 13 places, **every one of them geometry inherited from a KiCad library
footprint** rather than anything the generator placed: the TestPoint footprint
prints its own ring 0.14 mm from its own pad (TP1–TP12) and the
ESP32-S3-WROOM-1U outline passes 0.13 mm from U1 pad 1. JLC clips silk off mask
openings in prep, so a part's own marking encroaching by 0.01–0.02 mm is not a
defect. Those are budgeted **by name** via `memberOfFootprint()` rather than by
dropping the global limit, so a designator or legend actually buried in a pad
— a much larger miss — still fails.

Three rules go beyond what the community files check, each verified against
this board rather than assumed. `connection_width` at 0.15 mm closes a real
gap — the project's `min_connection` is `0.0`, so KiCad's check is disabled
outright, and `check_pcb.py` measures clearance *between* nets rather than the
width of copper *within* one; the pours' true minimum neck is 0.1904 mm, so a
rule at the community-typical 0.25 mm would report 218 non-defects. A 1.0 mm
hole-to-routed-edge rule (JLC's requirement, and a `TODO` in labtroll's file)
passes, and was checked non-vacuous — at an absurd 10 mm it reports 144
violations. `courtyard_clearance` duplicates `check_placement.py` on purpose,
because that checker needs `import pcbnew` and so is not in
`pcb-check-portable`, i.e. not in CI. One rule is deliberately left commented
out: `diff_pair_uncoupled` on the USB net class reported **90.4882 mm** on
the board before the pair was routed as a pair — an accepted trade at Full
Speed then, so enforcing it would have parked a permanent failure in the
report. It is enforced now, at a budget set from the pair-routed board.

Two checks remain off in the `.kicad_pro` rather than here, because they are
board settings and not expressible as custom rules: `min_groove_width` and
`solder_mask_to_copper_clearance` are both `0.0`, disabling the solder-mask
dam and sliver checks. Set to 0.1 mm and 0.05 mm on a scratch copy this board
reports **zero** violations, so enabling them costs nothing and turns on two
checks that a fine-pitch QFN board should have.

Everything on the copper side passes with room to spare, which is the expected
answer: the netclasses sit far above the fab floor, and the rules are there to
catch a slip, not to express intent.

Note that `kicad_build.py`'s DRC pass does **not** pass
`--exit-code-violations`, so what these rules find is reported in
`bisque-controller-drc.rpt` and does not fail the build.

Bare boards: roughly **$10–15 for 5 pcs** at the 4-layer ≤100×100 mm tier
(up from rev A's ~$2–4 2-layer price) plus shipping. Ready-to-upload
gerbers + drill files, including the two inner-layer files, are in
`gerbers/`.

**Assembly**: `generator/gen_jlc.py` writes `jlcpcb/BOM.csv` +
`jlcpcb/CPL.csv` for the PCBA upload, `jlcpcb/hand-solder-parts.csv` for the
parts you fit yourself, and `jlcpcb/mouser-order.csv` for ordering those from
Mouser in one import. Every part carries an LCSC part number verified
against the catalog (package, value, stock) — there are no blanks and nothing
to guess at in JLC's BOM matcher.

**The board is deliberately split between the SMT line and a soldering
iron**, same strategy as rev A: each unique **Extended** part costs a flat
$3 feeder-loading fee no matter how many boards you build, and a single
through-hole part forces the whole order onto **Standard** assembly
(Economic is SMD, top-side only) with a per-joint charge on top.

`HAND_SOLDER` in `gen_jlc.py` drops thirteen designators from both the BOM
and the CPL — they must leave together, since JLCPCB's upload rejects a CPL
carrying designators the BOM does not have:

| Hand-fitted | Why |
|---|---|
| J2, J3, J4, J8, J9 (2-pos screw terminals), J10, J11, J12 (4-pos screw terminals), J5, J6, J7 (KK-254 wafers), BZ1 (buzzer) | 5.08 mm and 2.54 mm pitch — the easiest joints on the board, but the ones that would force Standard assembly |
| LED1 (WS2812B, PLCC-4 5050) | No addressable RGB LED at LCSC is a Basic part (checked across WS2812/SK6812/XL-xxxx), so its $3 buys nothing an iron can't do to four edge-accessible pads |

What's left goes down the SMT line: **129 of 147 placements carry no feeder
fee**, and only **14 unique Extended parts** do — the module
(ESP32-S3-WROOM-1U-N16R2, C3013945), both MAX31856MUD+T (C2653162, one
designator, two placements), the ADE7953 (C515890), its 3.579545 MHz
oscillator (C2838127), the watchdog monostable (SN74LVC1G123, C123302), the
LDO (TLV1117LV33, C48937499), the buck's inductor (C475527), the input PPTC
(C369169), the buck's bulk electrolytic (C46, C2977550), the two SSR
optocouplers (TLP291, C55144), the three 60 V CJ2310s they drive (C75882),
the **TPS2116 power mux** (U12, C3235557), the Qwiic connector (C160404) and
the USB-C receptacle (C165948) — **$42 in feeder fees**.

The last three of those are recent and worth attributing: the optos and the
CJ2310s arrived with the 24 V SSR rework, and U12 with the power-mux swap
that deleted D2. U12 is the only one of the fourteen with no fee-free
alternative *of any kind* — the Basic and Preferred libraries hold no power
mux and no ideal-diode controller at any voltage, so unlike the LDO (where
the argument is headroom, see `design.py` at U2) there is nothing to
re-litigate here.
`gen_jlc.py` prints that list and total on every `make pcb-fab`, so it is
checkable rather than remembered.

Two libraries are free on Economic PCBA, not one: **Basic** (351 parts) and
**Preferred Extended** (1235), the latter being parts JLCPCB keeps mounted
but has moved out of Basic. That distinction only appears in JLCPCB's API
(`componentLibraryType == "base" or preferredComponentFlag`), not on the part
page's category line, so it is recorded per part in `gen_jlc.LCSC`'s
`fee_free` flag. Reading that field as "is Basic" is what made this number
print $33 for a board that owed $27.

The remaining eleven are structural, and the whole list was re-swept against
the fee-free library part by part (#348). The library holds **no connectors
at all**, so J1 and J14 cannot be avoided at any price; it holds no PPTC, no
oscillator at 3.579545 MHz, no retriggerable monostable, no inductor
fit for a 2 A rail, and **no aluminium electrolytic in any package** — which
is what makes C46 the one line here that pays $3 for a three-cent part, and
it is paid because the alternative is an unstable 5 V rail (see C46 in
`design.py`); and the module, both thermocouple front-ends and the
metering IC have no fee-free equivalent either. **U2 is the one that looks
free and is not** — the AMS1117-3.3 is Basic, drops into the same SOT-223
with the same pinout, and would drop out of regulation on a USB-only 4.35 V
rail; the argument is written out at `U2` in `design.py`. $33 is the floor
for this board short of hand-soldering F1, L1, C46 and J14 as well.

Substitutions that bought fee-free lines without giving anything up:

- **U4, D5, D6 → one Preferred SRV05-4 (C7420376)**, replacing an Extended
  SRV05-4 line (C558418) on D5/D6 and a USBLC6-2SC6 (C7519) on U4. Worth $6.
  It also raises U4's ESD rating from IEC 61000-4-2 level 4 (±8 kV contact)
  to ±30 kV and drops its line capacitance from 3.5 pF max to 1.0 pF.
- **R31/R34 6.8 Ω → 5.1 Ω (C17724, Basic)**. Worth $3. JLCPCB stocks no
  6.8 Ω resistor in either fee-free library in *any* package, so that one
  value was renting a feeder.
- **D8 → the Preferred SMAJ30A (C19077547)**, replacing the Extended
  C908776. Worth $3 and nothing else: same MPN, same DO-214AC land pattern,
  same 30 V / 400 W part, different library tier. One of 44 SMAJ30A
  listings is Preferred and this is it.

**Sourcing flags:** the thinnest stock on the BOM is `C19077547` (D8, ~651
units — the price of that last substitution, and a one-string revert to
`C908776` if it runs dry), then `C3013945` (the module, ~3.5 k), `C515890`
(the ADE7953, ~4.8 k) and `C2838127` (the oscillator, ~6.6 k) — all
single-sourced with no fee-free alternative. Re-check immediately before
ordering — see `FAB-READINESS-REVIEW-REVB.md`.

SW1/SW2 are **SMD** tact switches (XKB TS-1187A, C318884), not a
through-hole part — a Basic part, so it costs no feeder fee *and* stays
machine-placed.

`hand-solder-parts.csv` carries a **Mouser second source** where one exists,
so the shopping list works against either supplier. It is **one row per
orderable part**, not one per designator: J2/J3/J4/J8/J9 are five identical
WJ500V-5.08-2P blocks that happen to be called 24V_IN, TC1_K, SSR1, TC2_K and
SSR2, and a shopping list wants `Qty 5` on one line rather than five lines of
one. `BOM.csv` still keys on the schematic value as well, because JLCPCB's
`Comment` column is per line; the two use `group_by_orderable()` and
`group_by_part()` respectively. The values are joined in designator order into
the `Comment` cell, so collapsing the rows loses nothing — the line still says
which connector is which.

| Ref | LCSC | Mouser alternate |
|---|---|---|
| J5 | C17701004 | Molex **22-27-2141** — genuine KK-254 1×14 (LCSC line is an XD-2510-14A clone) |
| J6 | C239381 | Molex **22-27-2061** — genuine KK-254 1×06 (LCSC line is an A2547WV clone) |
| J7 | C240822 | Molex **22-27-2081** — identical, the LCSC line is already genuine Molex |
| J2, J3, J4, J8, J9 | C8465 | Phoenix Contact **1715721** (MKDS 1,5/2-5,08) — the part this footprint is named for |
| J10, J11, J12 | C42377749 | Phoenix Contact **1715747** (MKDS 1,5/4-5,08) — the part this footprint is named for |
| BZ1 | C96093 | Same Sky **CMI-1295-0585T** — Ø12 × 9.5 mm, 7.6 mm pitch, 5 V THT active |
| LED1 | C2761795 | **none** — no bare Worldsemi 5050 in Mouser's catalog; use LCSC, DigiKey, Adafruit or SparkFun |

Several of these LCSC lines are Chinese generics and the Mouser column is the
genuine part each footprint was drawn from where one exists, so it fits at
least as well — clone dimensional tolerance being the usual source of
trouble. It costs several times more, though: a real Phoenix MKDS is
dollars against cents for the WJ500V clone.

**Every one of these MPNs is written down in the footprint itself, and that
is the only place to look one up.** KiCad's KK-254 footprints carry
`old/engineering part number: AE-6410-NNA example for new part number:
22-27-2NN1` in their `descr`, and the terminal blocks are named
`MKDS-1,5-N-5.08` after the Phoenix order code — so J5's 1×14 is Molex
22-27-2141 (`AE-6410-14A`, confirmed on Molex's own part page) and the 4-pos
block is Phoenix 1715747, as facts rather than judgements. Do not extrapolate
from the digits of a neighbouring row: the Phoenix order numbers are not
sequential in position count, and the KK-254 family has four different
14-circuit vertical friction-lock headers (22-12/18/23/27-2141) that are *not*
the same part.

J5 and J10–J12 sat blank in this table for one release because the two rows
were filled in by pattern and the pattern did not exist. Both parts were on
Mouser's shelf the whole time.

### Mating connectors (cable side)

The same file carries the female housings and crimp terminals for the board's
male headers, as rows with `Kind` = **`mating`** rather than `board`. They are
not fitted to the board — they go on the far end of the loom — but they belong
on the same order, because a board with no mating connectors is a board you
cannot wire up, and that is the line you notice missing a week later.

| Part | Mouser MPN | Qty/board | For |
|---|---|---|---|
| Molex KK 254 crimp housing, 14 ckt (2695-14RP) | **22-01-3147** | 1 | J5 DISPLAY |
| Molex KK 254 crimp housing, 8 ckt (2695-08RP) | **22-01-3087** | 1 | J7 AUX |
| Molex KK 254 crimp housing, 6 ckt (2695-06RP) | **22-01-3067** | 1 | J6 NAV_SW |
| Molex KK 254 female crimp terminal, 30-22 AWG, tin (series 2759) | **08-50-0114** | 28 | one per circuit |

Only the KK-254 wafers need them. The screw terminals clamp bare wire, `J13`
is DNP, and `J14` is a JST SH Qwiic socket you buy a ready-made cable for.

The quantities are **derived from the board, not typed**: `mating_rows()` in
`gen_jlc.py` reads each header's own pin map, so 14 + 6 + 8 = 28 terminals
cannot drift when a header changes width, and a fourth KK-254 wafer added
without a `KK254_HOUSING` row fails the build rather than shipping a shopping
list you cannot make a loom from.

**The housing numbering is not the header numbering**, so this was followed
rather than pattern-matched — the same rule the table above is written under.
The footprints name the headers `22-27-2141` / `-2061` / `-2081` (Molex series
6410); Molex's part page for each says *"Mates With: KK 254 Single Row Crimp
Housings — 2695"*; series 2695 is `22-01-3NN7`, whose own pages list series
6410 back among the headers they mate and series 2759 among the terminals they
take.

**The terminal is the one judgement call**, and it is between three real parts:
`08-50-0114` is tin (matching the headers' matte tin) and Mouser sells it at
MOQ 1, but Molex marks it **obsolete**, so that stock is finite. The active tin
successor `08-50-0113` is reel-only at Mouser (MOQ 10 000; DigiKey has it as
cut tape). `08-55-0102` is active, bagged loose pieces, MOQ 1 at the same
price — but gold mating plating onto a tin pin, which is fine at 4 A and 25
mating cycles and not what you would specify for a box that lives warm. None
of the three carries an LCSC number here; these lines are Mouser-only.

Neither the housings nor the terminals appear in `BOM.csv` or `CPL.csv` —
there is nothing on the board to place.

### `mouser-order.csv` — the same parts, shaped for the importer

`hand-solder-parts.csv` is written for a human deciding what a part is and
where it goes, which is why it carries the LCSC number beside the Mouser one.
That shape does not import. Mouser's spreadsheet upload has a column-mapping
step in which picking `LCSC Part #` instead of `Mouser MPN` fails every line
*silently* — both columns are populated, so nothing warns you — and its
quick-paste box takes two columns and nothing else.

So `gen_jlc.py` emits a second file with one part-number column:

```
Mfr Part Number,Quantity,Manufacturer,Description,Customer Part Number
```

MPN and quantity first, so columns A and B paste straight into the quick
importer; `Customer Part Number` carries the designators, which Mouser echoes
onto the packing list so you can tell which bag is which. Board-fitted and
mating parts are one list, and the `Description` is the **Mouser** part's, not
the LCSC one's — a row reading `22-27-2141 … XD-2510-14A` is the kind of thing
that makes you think the import matched the wrong part.

Two deliberate differences from the shopping list, both in `jlcpcb/README.md`
at more length: `LED1` is dropped (Mouser has no bare Worldsemi 5050, and an
unmatched line you must notice and delete is worse than one named on stdout),
and the crimp-terminal line is ordered at **35** rather than the board's exact
28. `SPARES` adds 25 % to consumable lines only — a miscrimp is cut off and
thrown away, and running out mid-loom stops the build for a week over $0.16 —
while `hand-solder-parts.csv` keeps saying 28, because the two files answer
different questions.

The alternates were confirmed 2026-09-09 against Mouser's live catalog, one
search per MPN — so these are lines Mouser actually carries, not just parts it
lists. That still took a real browser: there is no Mouser API key here and
Mouser blocks scripted fetches (`curl` and `WebFetch` both get an Akamai
challenge page served with `200 OK` and a `.pdf` content-type, so a fetch that
"succeeds" is how this goes wrong quietly). Molex's own part pages carry a live
distributor-inventory table including Mouser stock and price, and are not
blocked — that is the cheaper check for a Molex line, and it is the only one
that worked for the mating connectors above (confirmed 2026-09-10; DigiKey
serves a bot challenge too now). Re-confirm stock at order time.

**Assembly stays Economic**: with 0 through-hole parts left in the assembly
BOM (`gen_jlc.py`'s own output confirms this every run), the whole
machine-placed set qualifies for Economic (SMD, top-side only) rather than
Standard, same as rev A.

**The CPL corrects both the angle and the origin, per part, from LCSC's own
land patterns.** JLCPCB does not place our footprint: it places LCSC's
footprint for that part number, anchoring *its* origin at Mid X / Mid Y and
turning *its* pin 1 by Rotation. `JLC_PLACEMENT` in `gen_jlc.py` therefore
carries a `(rotation, dx, dy)` per LCSC part, and
`generator/check_jlc_placement.py` — run by `make pcb-check` — derives that
triple by fitting LCSC's pad centres (`generator/lcsc_pads.json`, from
EasyEDA's component API) onto the KiCad footprint's, and fails if the table
disagrees. Sixteen parts need a correction; `gen_jlc.py` names them every run.

This replaced a package-family regex table copied from
bennymeg/Fabrication-Toolkit, which was wrong for six parts on this board and
put four of them visibly askew in JLCPCB's assembly preview. `^SOT-23 -> 180`
also matches SOT-23-**6** (U4, D5, D6), whose LCSC land runs across the pins
rather than along them — 270, not 180. `^QFN- -> 90` was 180 out for the
ADE7953's LFCSP-28 (U7), which a preview cannot show you, because a square
QFN's pads overlap at every quarter turn. And no family rule can express an
*origin* difference at all: U1 and J1 sit 0.477 mm and 1.571 mm off, because
KiCad anchors the WROOM-1U and the USB-C receptacle at their body centres
while LCSC anchors them on the pad pattern.

Two traps the fit is written to avoid, both of which produced a wrong answer
first. Pad numbering is a library convention, not a physical fact: LCSC
numbers an LED's anode 1 where KiCad numbers its cathode 1, so fitting pin
numbers alone "corrects" all three LEDs by 180° and mounts them backwards —
`PIN_REMAP` states the difference, read off LCSC's own symbol pin names. And a
pad number that appears twice can mean different things on each side (KiCad's
`SOT-223_TabPin2` numbers the tab 2, LCSC numbers it 4), so a number whose
instances are not clustered is dropped rather than averaged into a meaningless
centroid.

Still worth a glance at the order preview: it is free, and it is what caught
this. Polarized two-terminal parts especially — a flip there is cheap to spot
and expensive to miss.

**Detailed per-unit cost breakdown and process-edge clearance analysis are
not reproduced here for rev B.** Rev A's README carried a line-item
Economic-PCBA cost table and a table of exact clearances from J1/board edge
that no longer apply now that the board is 100 × 100 mm at 4 layers with a
different part census and placement. J1 (USB-C) is still at the board edge
by necessity, and J14 (Qwiic) now sits on the bottom edge for the same
reason, so JLCPCB's SMT process-edge requirement likely still applies
in some form — get an exact quote (and re-check whether process rails are
needed) from JLCPCB's own order preview rather than trusting stale numbers
here.

## Regenerating the files

Everything derives from `generator/design.py` — a single table of
components, pin→net connectivity and placements — so schematic and board
can never disagree. Requires **KiCad 10+** (pcbnew Python module +
kicad-cli + standard libraries) — the project's `.devcontainer/` (see
`docs/devcontainer.md`) bakes this in, as an alternative to installing
KiCad natively. The Makefile finds KiCad's Python itself: it tries `python3`
first (which is where the devcontainer has `pcbnew`), then the macOS
`KiCad.app` bundle, and takes the first interpreter that can `import pcbnew`.
Set `KPY=/path/to/python3` to override it; if none is found the error names
every path it tried.

The top-level `Makefile` wraps the common cases — `make pcb` regenerates
everything and re-runs every checker; `make pcb-check` runs just the
checkers against what's already committed, without touching KiCad:

```bash
make pcb          # regenerate schematic + board + fab outputs + renders, then check
make pcb-build    # schematic + board only (no fab outputs) — the full path, ~221 s
make pcb-cosmetic # silk / 3D models / title block only, reusing the routing — ~8 s
make pcb-fab      # gerbers, drill, BOM/CPL, PDFs — after pcb-build
make pcb-check    # check only: pinmap, sheet bounds, netlist, connectivity, silkscreen, reproducibility
make pcb-render   # 3d/board-3d-*.png raytrace — ~13 s, skipped when no input changed
make pcb-render FORCE=1    # re-raytrace even when the stamp says it is current
make pcb-cosmetic-verify   # prove pcb-cosmetic == pcb-build, byte for byte — SLOW
```

`make pcb` = `pcb-build` + `pcb-fab` + `pcb-check` + `pcb-render`, in that
order, so a board change and everything derived from it move together.
Nothing derived is left for you to remember. It used to be worse — `make
pcb` ran *no* export step at all, so it could succeed while leaving the
committed gerbers, BOM, CPL and PDFs describing the previous board.

`pcb-check` runs before `pcb-render` deliberately: the raytrace is the
slowest step and the least useful output to stare at once a checker has
already said the board is wrong.

**The renders are content-addressed, and they have to be.** `kicad-cli`'s
raytracer is not reproducible — two runs over a byte-identical board differ
in 5.6% of their channel bytes (mean delta 89 of 255; sampling noise, not
rounding). Re-rendering unconditionally on every `make pcb` would therefore
put a ~900 KB binary diff in `git status` for a board nobody touched, and
the thing you learn from that is to discard `3d/` without looking — right up
until the day the change was real. So `render-3d.sh` hashes everything that
can change a pixel (the board file, `3dmodels/`, and its own render flags)
into `3d/.render-stamp` and skips when it matches: ~0.2 s instead of ~13 s,
and no diff. This is the same trick as the fixture manifest in `tests/host/`,
and it works here for the same reason — the board build is reproducible, so
an unchanged design hashes identically on any machine. The stamp is
committed so a clean clone skips too. `make pcb-render FORCE=1` overrides.

### Seeing what each stage produced: `stages/`

Every run of `gen_sch.py` and `kicad_build.py` drops the file it is holding
at each stage into `stages/` (gitignored, overwritten each run). Nothing
reads them. They exist because the finished board is the *last* of ten
states and six of them have written over the evidence by the time you look:
"the silk placer put that legend somewhere daft" and "the router left this
net open" are both questions about a board that no longer exists on disk.
Each stage board gets a `.kicad_pro` and `.kicad_dru` copy under its own
basename, so opening one in KiCad gives it the real net classes and DRC
rules rather than the defaults — a board with no project reports violations
the real one does not, which is the opposite of a debugging aid.

| File | State |
|---|---|
| `01-sch-generated.kicad_sch` | `gen_sch.py`'s own text, before KiCad sees it |
| `02-sch-upgraded.kicad_sch` | after `kicad-cli sch upgrade --force` — the 20k → 45k line reflow |
| `10-reused.kicad_pcb` | `--no-route` only: the board as loaded, canonicalised, derived items stripped |
| `20-placed.kicad_pcb` | after `build_board()` — footprints and nets, no copper |
| `30-routed.kicad_pcb` | full path only: after `route_board()` + `add_copper()` |
| `40-outline.kicad_pcb` | after `add_outline_and_silk()` — silk exists, unplaced |
| `50-silk.kicad_pcb` | after `silk.place()` |
| `60-zones.kicad_pcb` | full path only: after `add_zones()`, unfilled |
| `70-stackup.kicad_pcb` | after the pcbnew save and `apply_stackup()` |
| `80-filled.kicad_pcb` | after `kicad-cli pcb drc --refill-zones --save-board` |
| `90-final.kicad_pcb` | after the last `canonicalize` + `resort_to_kicad_order()` |

Missing numbers are how you tell which path ran: no `30`/`60` means
`--no-route`, no `10` means a full build.

This is unconditional, and it is safe to have on the byte-identity path for
one specific reason. `10`–`60` go through `pcbnew.SaveBoard(...,
aSkipSettings=True)`, and the skip is load-bearing rather than an
optimisation: without it, saving attaches and writes the board's PROJECT —
the exact side effect `kicad_build.main()` already has to undo once with
`read_project`/`restore_project`, and which silently emptied the `erc` block
and `sch_revision` for a while. With it, a stage snapshot writes a
`.kicad_pcb` and touches nothing else. `70`–`90` are plain file copies of a
board already on disk, so they cannot perturb anything at all. `make
pcb-build` and `make pcb-cosmetic` both still produce a board byte-identical
to the committed one.

Each writer clears only its own numbers (`gen_sch.py` owns `0*`,
`kicad_build.py` owns `[1-9]*`): `make pcb-build` runs them as two processes
into one directory, and a writer that wiped the whole directory would take
the other's output with it. Clearing at all matters because a stale stage is
worse than an absent one — a `--no-route` run that left the previous full
build's `30-routed.kicad_pcb` sitting in sequence would look current.

### Which path does your change need?

Routing 92 nets across 141 parts is essentially all of `pcb-build`'s
runtime, and several kinds of change cannot move a single track. Those get
`make pcb-cosmetic`, which is `kicad_build.py --no-route`: it reads the
tracks, vias and filled zones back off the existing board and re-derives
everything else with the same code the full build runs.

| Change | Path | Measured |
|---|---|---|
| Silkscreen placement (`generator/silk.py`, the `SILK` table, reference text size/thickness) | `make pcb-cosmetic` | **8 s** |
| The nameplate — `TITLE_*` / `TITLE_ROWS`, `SILK_GRAPHICS`, `generator/logo.py` | `make pcb-cosmetic` | **8 s** |
| 3D models (`MODEL_FIXUP` in `kicad_build.py`, files in `3dmodels/`) | `make pcb-cosmetic` | **8 s** |
| Board title block | `make pcb-cosmetic` | **8 s** |
| **Anything else** — placement, connectivity, footprint choice, net classes, `MANUAL_VIAS`, router parameters (`router.py`, `gen_pcb.py`) | `make pcb-build` | **221 s** |

**That number is for a design the router can close, and a placement change
is exactly what stops it being one.** The router is greedy with a
rip-up-and-retry fallback and iterates until the failure set stops shrinking;
this board's current placement takes three passes and **221 s**
(`make pcb-cosmetic-verify` measures it), but a placement it *cannot* close
spends all its time in rip-up. The revisions of this change set that stranded
a net ran **10–40 minutes each**, and one of them nine minutes on a single
net. Read the per-pass `N net(s) unrouted` lines rather than waiting in
silence — a count that is not shrinking means stop and look at the placement,
and note the run keeps the best pass, not the last one.

Two traps in diagnosing a net that will not route, both of which cost a full
rebuild here to learn:

* **Measure congestion against a FULLY ROUTED board.** Measuring the board
  from the failed build is circular: the nets that failed are the ones that
  are missing, so the region they wanted reads as empty. `git show
  HEAD:…kicad_pcb` is the reference.
* **Clip each track to the window; do not test its endpoints.** A corridor is
  by definition traces passing straight *through* a region, and an
  endpoint-in-rectangle test scores it zero. Two "completely empty" bands
  found that way — the escape south of U1 and the lane at the middle of the
  board — carry 336 mm and 220 mm of track respectively, and putting parts in
  either one stranded nets.

And when a net fails **even after being promoted to route first**, ordering is
not the problem: at that point only fixed geometry exists (hand seeds, fanout
stubs, plane vias), so the lane it needs is genuinely blocked. That is what
`ADE_I2C_SEEDS` is for — see below.

Both numbers used to be far worse — 421 s and 104 s — and the fast one was
not dominated by anything the fast path exists to skip. It was the
silkscreen placer, which is the *only* substantial work `--no-route` still
does, running a linear scan over all 492 pads and every other label for each
of ~200,000 candidate placements, and re-entering SWIG 171 million times to
re-answer `pcbnew.FromMM(0.05)`. Indexing those obstacles into a bucket grid
(the one `router.py` already uses for copper) and hoisting the clearance
constants took the placer from 95.2 s to 3.8 s. The placed silk is
byte-identical, which is the only acceptable outcome for a lookup
optimisation; `make pcb-cosmetic-verify` checks it against a full rebuild.

The full path was 318 s until the same lesson was applied to `router.py`.
Profiling it found the cost in the same place and not where the code
structure suggests: A* node expansion was 20% of the run, and 71% went into
`_clear_of`, which answered "is this cell clear?" by calling the exact
point-to-shape `dist()` on every obstacle within 3 mm — 381 million times.
Three changes, all of them lookup, none of them routing:

- Each `Shape`/`Seg` caches its bounding box, and `_clear_of` rejects on four
  float compares before calling `dist()`. An obstacle further than `need`
  from the box in x or y is further than `need`, full stop, so this cannot
  change an answer. It removes 79% of the `Seg.dist()` calls and 98% of the
  `Shape.dist()` ones.
- `_near()` returns a cached flat list of the 3×3 bucket block rather than
  being a generator over nine dict lookups, which was costing 833 million
  frame resumptions.
- `via_ok()` made three separate passes over the neighbourhood — copper
  clearance, via-in-pad, hole-to-hole — and ANDed them. They are now
  interleaved into one walk. It is asked at nearly every node A* pops
  (4.3 million times a build) and its memo barely hits, because a node is
  popped once.

Routing went 310 s → 144 s and the board is byte-identical, which is again
the only acceptable outcome. **`GRID` was measured, not left alone on
faith**: at 0.4 mm 14 nets fail to route and at 0.3 mm five do, in both
cases on the ADE7953 and the two MAX31856s — the fanout and plane-via stubs
snap their ends to `GRID`, so a coarser grid walks the escape off the pad
centreline exactly as the note beside `GRID` says. 0.3 mm is also *slower*
than 0.25 mm (463 s), because a net that cannot be routed exhausts the whole
grid before it says so, several times per pass.

When in doubt, use the full path. `--no-route` is not a judgement call it
leaves to you: before it reuses anything it compares the loaded board
against `design.py` — every reference, footprint, placement, orientation,
pad→net assignment, the net set, and every `MANUAL_VIAS` entry — and exits
naming the mismatches rather than emitting a plausible-but-wrong board.
What it cannot see is a change to the router's own parameters, since those
leave no trace on the board; that one is on you.

**`--no-route` output is byte-identical to a full rebuild**, and that is
tested rather than asserted. `make pcb-cosmetic-verify`
(`generator/check_fast_path.py`) does a full rebuild in a scratch
directory, then runs `--no-route` twice over copies of it — once as-is, and
once over a copy whose cosmetics have all been deliberately wrecked (every
designator moved and resized, every board text moved, the title block
overwritten, U1's 3D model flung off the board) — and requires all three
files to match to the byte. The vandalised run is the one that matters: it
shows the loaded board's cosmetic state cannot leak into the result, which
is why `--no-route` deletes and re-adds every footprint and board graphic
instead of editing them back to a default. A silk placer re-run over its
own previous output is not solving the problem a fresh build hands it.

Two things that path had to get right, both of which bit during
development and both of which are guarded now:

* **Zones are inherited, not refilled.** `--no-route` runs
  `kicad-cli pcb drc` *without* `--refill-zones`, which is not merely 0.8 s
  cheaper — it is required. KiCad's filler is idempotent once a zone is
  filled, but filling an empty zone and refilling a full one do not agree:
  refilling this board's +3V3 pour rewrites ~180 lines of its
  `filled_polygon`. The full path fills from empty, so the fast path has to
  leave that fill alone or lose byte-identity on the pour.
* **The board is canonicalised on the way in, not just out.** Tracks and
  vias keep the uuids the file gave them, and KiCad's writer breaks
  position ties between items with the uuid — so copper the GUI *added*,
  carrying a random uuid, would tie against derived ones and land wherever
  chance put it. Re-deriving on load makes every tie a function of the
  design again.
* **KiCad has the last word on item order.** Both paths end with
  `resort_to_kicad_order()`, which runs `kicad-cli pcb upgrade --force`
  until the bytes settle. KiCad sorts items by uuid — footprints
  outright, tracks and vias as the tie-break after position — so with
  every uuid derived from content that order is a function of the design,
  and storing the board in it makes a GUI save a no-op instead of the
  61,654-line reorder it used to be (against 58,737 lines, for 7 real
  edits). `gen_sch.py` ends the same way, with
  `kicad-cli sch upgrade --force`.

  Two traps worth knowing before you re-verify any of this.
  `kicad-cli pcb drc --save-board` does **not** sort — it writes items
  back in the order it read them, so it happily preserves content order
  and reports byte-identical output. It is useless as a stand-in for a
  GUI save; use `pcb upgrade --force`. And one pass is not enough: the
  sort leaves ties in load order, so a file arriving in a foreign order
  needs several (three, on this board; pass 1 and pass 2 differ by 16,860
  lines). Hence the loop, and the hard failure if it never settles.
* **The board is canonicalised after the fill, not only before.** A uuid
  derives from the item's serialised content, and a zone's content is its
  `filled_polygon` — which the full path has not written yet when it
  canonicalises before the DRC, but which the fast path inherits. Derive
  only before the fill and the five pours get one uuid on `pcb-build` and
  a different one on `pcb-cosmetic`: a `pcb-cosmetic-verify` failure on
  the only five items in the file whose bytes KiCad writes rather than
  pcbnew.

Equivalently, by hand:

```bash
cd hardware/kicad
python3 generator/gen_sch.py bisque-controller.kicad_sch        # schematic
python3 generator/check_netlist.py bisque-controller.kicad_sch  # KiCad netlist round-trip: must PASS
python3 generator/check_sch_uuids.py bisque-controller.kicad_sch  # KiCad invents no uuids: must PASS
"$KPY" generator/kicad_build.py bisque-controller.kicad_pcb     # board via pcbnew API:
                                                                #   (add --no-route to reuse the routing
                                                                #    already on disk — see "Which path
                                                                #    does your change need?")
                                                                #   system-library footprints, octilinear
                                                                #   45-degree autoroute (2 signal layers),
                                                                #   In1.Cu/In2.Cu plane fills, GND stubs,
                                                                #   pour-island healing, KiCad DRC report
python3 generator/check_pinmap.py                                # design.py <-> Kconfig agreement: PASS
python3 generator/check_sch_bounds.py bisque-controller.kicad_sch  # nothing off the declared sheet: PASS
python3 generator/check_sch_layout.py bisque-controller.kicad_sch  # nothing drawn on top of anything: PASS
                                                                #   (every other checker validates connectivity,
                                                                #    which is complete no matter where a symbol
                                                                #    sits — this is the one that notices the
                                                                #    exported PDF is missing half the circuit)
python3 generator/check_pcb.py bisque-controller.kicad_pcb      # independent checker: ALL CHECKS PASS
"$KPY" generator/check_via_in_pad.py bisque-controller.kicad_pcb  # no via inside an SMD pad: PASS
python3 generator/check_drill_clearance.py bisque-controller.kicad_pcb  # hole-to-hole >= 0.30 mm: OK
                                                                #   (net-independent: a drill bit does not
                                                                #    care that a slot and the via beside it
                                                                #    are both GND, and every net-aware check
                                                                #    we own missed a 0.078 mm web because
                                                                #    of it — see FAB-READINESS-REVIEW-REVB)
"$KPY" generator/check_silk.py bisque-controller.kicad_pcb      # silkscreen printable AND associated: PASS
                                                                #   (hard-fails on silk over an exposed pad
                                                                #    or clipped by Edge.Cuts; silk-on-silk
                                                                #    is budgeted, and the budget is 0;
                                                                #    a board text under a part big enough
                                                                #    to hide it is budgeted BY NAME in
                                                                #    ON_PART_OK — a new burial fails, and
                                                                #    so does a stale entry. The other half
                                                                #    of that check, "did the label end up
                                                                #    near what it names", is in
                                                                #    kicad_build.py: it needs each anchor,
                                                                #    and the board file does not record
                                                                #    one)
python3 generator/check_canonical.py bisque-controller.kicad_pcb  # reproducibility guard: ALL CHECKS PASS
                                                                #   (KiCad DRC can't see this - a via and
                                                                #    the pad it sits in share a net, and
                                                                #    clearance rules skip same-net copper)
python3 generator/check_jlc_placement.py                        # CPL placement: OK
                                                                #   (fits LCSC's own land pattern onto each
                                                                #    footprint; the package-family rotation
                                                                #    table it replaced was wrong for six
                                                                #    parts, four of them visibly so in
                                                                #    JLCPCB's assembly preview)

# Fab outputs — regenerate these together, after the board file is final.
# The --layers list is what JLCPCB needs; without it kicad-cli also emits
# Fab/Courtyard/User layers that don't belong in a fab package. Note the
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

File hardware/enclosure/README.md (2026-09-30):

# Bisque Kiln Controller — Enclosure Design

A build-it-from-catalog-parts enclosure for the complete controller: the
rev B PCB, the 4.0" display, the 5-way nav switch, the 24 V supply, both
SSRs and their heatsinks, the mains distribution, and the CT sensors. The
enclosure itself is an **off-the-shelf wall-mount steel box** — no custom
sheet-metal fabrication, only drilling and one rectangular cutout (the
display window), all of which is covered by printable 1:1 templates
(`door-template*.svg`, regenerated by `generate_panel_template.py`).

This document describes **two door revisions** sharing one back-panel
design. **Rev 1** (the default throughout) uses the 5-way nav switch and a
sealed window. **Rev 2** drops every button for full touch control — see
[Revision 2](#revision-2--touch-only-door) at the end, which states only
what differs.

> **Safety scope.** Everything mains-side in this document must follow
> local electrical code, and none of it replaces the mechanical
> protections `hardware/kicad/README.md` requires: a mechanical
> over-temperature cutout and/or contactor in series with the elements,
> appropriately rated branch-circuit protection, and supervision while
> firing. The on-board watchdog and lid interlock are supplementary.

## What goes in the box

| Item | Source | Notes |
|---|---|---|
| Bisque controller PCB | `hardware/kicad/` | 100 × 100 mm, M3 holes on a 90 × 90 mm grid, **grounded** — metal standoffs deliberately bond board GND to the earthed door |
| Display module | LCDWIKI **MSP4021** (4.0" ST7796S SPI) | PCB 61.74 × 108.04 mm, active area 55.68 × 83.52 mm, used landscape; 14-pin loom to J5 |
| Nav switch | 5 × 12 mm panel-mount momentary pushbuttons | Cross layout (Up/Down/Left/Right/Select), wired to J6; active-low to GND, no resistors needed (ESP32 pull-ups) |
| 24 V supply | Mean Well **HDR-15-24** (24 V / 0.63 A, DIN rail) | One supply for the whole box. The board regulates its own 5 V (U11), so it draws ~0.25 A at 24 V; the rest is available for 24 V relay coils on `AUX_VP` |
| Aux coil supply | *none needed* | `AUX_VP` can come off the same 24 V rail. A 24 V relay coil draws 10–20 mA against a 5 V coil's 70–100 mA, so the one HDR-15-24 drives roughly 20 of them. A separate supply is still fine — leave `SJ1` open when one is fitted |
| SSR × 2 | Omron **G3NA-240B** (40 A) or Crydom D2440-class | DC input 5–24 V, zero-cross, **with a datasheet control↔load isolation rating** — this is the only mains barrier to the board, see the KiCad README |
| SSR heatsinks × 2 | Omron **Y92B-N100** (1.63 K/W) or per vendor pairing table | See "Thermal design" — the sizing rule, not the part number, is the requirement |
| Mains distribution | DIN terminal blocks, 2× DIN fuse holder or MCB (controller feed + aux), PE block | On the same DIN rail as the PSU |
| Contactor (strongly recommended) | Definite-purpose contactor sized for total element current | In series with both SSR outputs, dropped by the mechanical over-temp cutout / E-stop loop |
| CT × 2 | Split-core CT matched to the board's 5.1 Ω burden (full scale ≈ 139 A rms) | Clamped on each zone's load conductor inside the box, twisted pair to J12 |
| Wi-Fi antenna | U.FL → SMA bulkhead pigtail + 2.4 GHz antenna | Off-BOM accessory from the KiCad README; the steel box is exactly why the 1U module was chosen |
| Enclosure | Generic 16 × 12 × 6 in IP66 steel wall-mount box with inner plate | See below |

## Enclosure selection

**Baseline: a generic imported 16 × 12 × 6 in (406 × 305 × 152 mm) IP66
carbon-steel wall-mount box** — hinged, latched door, 1.5 mm
cold-rolled steel, sold **with a galvanized inner mounting plate
included** — the Vevor/SKYSHALO-class boxes on Amazon/Walmart, ~$60.
The name-brand equivalent (Hammond **EN4SD16126GY** + **EP1612** panel,
Saginaw/Hoffman similar) is the same box mechanically but runs
**~$240 + ~$35 for the panel** — worth it only if you need the **UL 50/508A
listing** for an inspected or commercial installation, or a
NEMA 4/12 rating you'd actually preserve (the baseline design vents the
box for the SSR chimney anyway, which forfeits the sealed rating
regardless of what you paid for it).

Two things to check on an import that a Hammond buyer gets for free:
that the **door is bonded** to the body (most include a ground screw on
door and body — fit a braided strap between them if there's no factory
strap), and that the inner plate is actually steel and lands on welded
studs, not adhesive standoffs.

Why this class of box:

- **The door is the front panel.** 305 × 406 mm of flat steel takes the
  display window, the nav cross, and the controller PCB with room to
  spare, and hinges open for USB-C access without unwiring anything.
- **Depth.** 152 mm clears an SSR + internal heatsink stack (~90 mm off
  the back panel) plus the door-mounted PCB and looms (~30 mm) with
  ~30 mm to spare.
- **Steel = shield.** The board already assumes a grounded steel shell
  (U.FL external antenna, grounded mounting holes); a plastic box would
  waste both decisions.
- **The inner panel** carries all the mains-side gear, so the box shell
  itself gets only holes, and the whole mains assembly can be built and
  wired on the bench.

Sizing alternatives, same series so every dimension below scales
trivially:

| Situation | Box |
|---|---|
| ≤ 25 A per zone, no contactor | 16 × 12 × 6 in generic (baseline), ~$60 |
| Up to 40 A per zone, contactor + aux PSU fitted | 20 × 16 × 6 in generic (~$80–100); Hammond EN4SD20166GY + EP2016 if listed gear is required |
| Inspected / commercial install | Hammond EN4SD16126GY + EP1612 (UL listed, ~$275 all-in) |

## Layout

Two zones, hard-segregated: **everything SELV lives on the door,
everything mains lives on the back panel.** The only things that cross
are the SSR control pairs, the CT twisted pairs, the 24 V feed to J2, and (if
fitted) the aux coil feed — all SELV, all in one loomed bundle across
the hinge with a strain-relieved slack loop.

```
        DOOR (inside view)                 BACK PANEL (inner plate)
  ┌──────────────────────────┐         ┌───────────────────────────────┐
  │      ┌────────────┐      │         │  DIN RAIL:                    │
  │      │  display   │      │         │  [PE][IN][FUSE][HDR-15-24][AUX]│
  │      │  window    │      │         │                               │
  │      └────────────┘      │         │  ┌────────┐    ┌────────┐    │
  │           (U)            │         │  │ SSR 1  │    │ SSR 2  │    │
  │        (L)(S)(R)         │         │  │  on    │    │  on    │    │
  │           (D)            │         │  │heatsink│    │heatsink│    │
  │      ┌────────────┐      │         │  └────────┘    └────────┘    │
  │      │ controller │      │         │   CT1 ○         CT2 ○        │
  │      │    PCB     │      │         │                               │
  │      └────────────┘      │         │  [load terminal blocks]       │
  └──────────────────────────┘         └───────────────────────────────┘
       hinge side: SELV loom              bottom: cable glands
```

Board orientation on the door: rotate the PCB so its **south edge
(J5/J6/J7/J11) faces up**, toward the display — the 14-pin display loom
and the nav loom stay short (SPI runs at 40 MHz; keep the display loom
under ~150 mm). That puts USB-C (J1) at the bottom, reachable with the
door open, the SSR/power terminals (J2/J10/J4/J9) on one side facing the
hinge loom, and the TC/CT terminals (J3/J8/J12) on the other.

**Thermocouple routing.** J3/J8's screw terminals are the cold junction
reference — the MAX31856s compensate on-die a few mm away. Door mounting
is what keeps them away from the SSR heat plume; run the K-type
extension wire up the SELV side, ≥ 50 mm from any mains conductor, with
no intermediate junctions between the kiln probe and the board terminal.
Both probes must be **ungrounded-junction** (see the KiCad README).

**Antenna.** SMA bulkhead through the enclosure's top-left side wall
(SELV side), 6.5 mm D-hole. The U.FL end is good for ~30 mating cycles —
connect it once, at final assembly, and route the pigtail away from the
SSR wiring. Stay within the module's certified antenna list (CERT-001 in
`FAB-READINESS-REVIEW-REVB.md`).

### Door drilling — rev 1 (`door-template.svg`, print 1:1)

Coordinates from the door's top-left corner, door mounted 406 mm tall.
All positions are centered horizontally at x = 152.5 mm.

| Feature | Position (center) | Size |
|---|---|---|
| Display window | (152.5, 110) | 86 × 58 mm rectangular cutout |
| Display module M3 holes | corners of the module PCB, nominally inset 2.5 mm | ⌀3.2 — **measure your module before drilling**; clone modules vary, and the template marks these as VERIFY |
| Nav buttons ×5 | cross at (152.5, 190), 24 mm pitch | ⌀12.2 each |
| Controller PCB M3 holes | (152.5 ± 45, 290 ± 45) | ⌀3.2, the board's 90 × 90 mm grid |

The window is cut 86 × 58 so it reveals the full 83.5 × 55.7 mm active
area with ~1 mm margin while staying inside the module's glass. Bond a
gasketed 2 mm polycarbonate window behind the cutout — kiln rooms are
dusty, and nothing needs the resistive touch surface exposed (firmware
has no touch driver; the nav switch is the input). Mount the module on
M3 standoffs so the glass sits just behind the window; mount the PCB on
**metal** M3 standoffs — H1–H4 are grounded on purpose, and the standoffs
bond board GND to the earthed door.

### Back panel and shell

- **DIN rail** across the top of the inner plate: PE terminal, incoming line
  terminals, a fuse holder (1 A slow-blow) feeding the HDR-15-24, an
  optional second fused position for the aux PSU. Feed the controller
  from its own small circuit or tap ahead of the SSRs per local code —
  never downstream of them.
- **SSRs** on the lower half, one per zone, fins vertical, ≥ 25 mm apart
  and ≥ 25 mm from the panel edges. Load-side wiring in the bottom-right
  quadrant only.
- **CTs** clamp each zone's load conductor right at the SSR output
  terminal block; twist each secondary pair to J12.
- **Cable glands** through the bottom wall (never the top of a NEMA
  box): mains in (M25), zone 1 out (M25), zone 2 out (M25), TC1 (M16),
  TC2 (M16), spare M16 for lid switch / aux / inputs.
- **Grounding:** enclosure PE stud → incoming earth; door bonded to the
  body with a braided strap (factory-fitted on name-brand boxes; add one
  if the import lacks it); inner plate bonded via its mounting studs and
  ground screw; every gland on the
  mains side metallic and seated on bare metal or star washers.

## Thermal design

The SSRs are the only significant heat source. A hockey-puck SSR drops
roughly 1.0–1.6 V, so budget **≈ 1.25 W per amp per zone**:

| Per-zone element current | Dissipation per SSR | Heatsink + airflow |
|---|---|---|
| ≤ 12 A | ~15 W | Y92B-N100-class (≤ 1.7 K/W), passive |
| 12–25 A | ~30 W | ≤ 1.0 K/W or vendor-paired sink, louvred chimney (below) |
| 25–40 A | ~50 W | Vendor-paired sink **plus** a 60 mm fan on the chimney; or a through-wall heatsink kit that puts the fins outside |

The sizing rule behind that table: keep the SSR base ≤ 80 °C at your
worst-case in-box ambient (design for 50 °C inside — a kiln room runs
hot), so `R_sink ≤ (80 − 50) / (1.25 × I_zone)`. Whatever sink you fit,
verify the base temperature with a thermocouple during the first
full-power firing; if it exceeds 80 °C, add the fan. Always follow the
SSR vendor's own derating curve for the specific SSR/heatsink pairing
(Omron publishes G3NA ↔ Y92B charts), and derate the SSR itself to
≤ 70 % of nameplate.

**Ventilation.** For the passive chimney: a louvred vent low on the
right (mains) side wall and another high on the same wall, both with
insect mesh, giving convection a straight path up the heatsink fins.
This drops the box from NEMA 4/12 to effectively NEMA 1 — fine for an
indoor kiln room; if the box lives somewhere wet or dusty, use the
through-wall heatsink option and keep the shell sealed. The door-mounted
electronics benefit from the same segregation: the PCB and display hang
in the cool front half of the box, out of the heatsink plume, which also
keeps the cold-junction terminals stable.

The HDR-15-24 adds ~2 W; the on-board LDO's headroom analysis in the KiCad
README already assumes a hot enclosure ambient, so no further derating is
needed.

**The board input is 24 V and the 5 V rail is made on board.** J2 feeds
F1 (a 750 mA / 33 V resettable fuse) and D8 (an SMAJ30A TVS) at the entry,
then Q8 for reverse polarity, then U11 — an XL1509-5.0 buck whose absolute
maximum input is **40 V**. Two consequences worth knowing:

- **The trim pot no longer matters.** +5V used to be literally the input
  minus a series Schottky, so every turn of the PSU's trim landed on the
  WS2812B logic threshold, the SSR drive voltage and the relay coil at once.
  It is now a regulated 5.0 V across the HDR-15-24's whole +/-10% travel.
  Reverse polarity is a P-channel MOSFET rather than that Schottky, so the
  24 V SSR terminals — which hang off the protected input, not off the
  regulated rail — now sit within ~40 mV of the supply instead of ~0.4 V
  below it.
- **A 12 V supply on J2 is no longer fatal, and neither is 24 V on the aux
  terminal.** The rail that used to die at 6.4 V now tolerates 40 V, and
  F1/D8 clamp anything past that. This is the one place where the old
  "verify the PSU before connecting the board" warning can be relaxed —
  though landing mains on J2 is still a destroyed board, which is why the
  terminal is fused and labelled.

## Commissioning notes

1. **First power-on with unflashed firmware: both SSR channels are dead
   by design.** The hardware watchdog holds `SSR_EN` down until firmware
   kicks GPIO 36. Before concluding an SSR or wiring fault, read the
   `SJ2` / "WDT DEFEAT" section of `hardware/kicad/jlcpcb/README.md`.
   **Leave `SJ2` open in a finished install** — bridging it defeats the
   only heat cutoff that survives firmware death. It is a bench-debug
   jumper, not a build step.
2. **No lid switch fitted?** Jumper J11 pin 1 to J11 GND or set
   `KILN_PIN_LID_SWITCH=-1`, or the kiln will never heat — see
   `docs/pin-assignments.md` §1.
3. Verify the SSR control polarity: J4/J9 pin 1 (`24V`) is `VIN_P`, the
   protected 24 V input and **always live**, to the SSR's `+` input. Pin 2
   (`OUT`) is the switched low side, to `−`; the watchdog gates the shared
   return behind it. Land each SSR's `−` on its own `OUT` and nowhere else.
   A `−` that reaches ground by any other route (the PSU `−`, a shared
   negative bus, a lead chafed onto this earthed box) turns that SSR on with
   no way for the board to turn it off. Meter `OUT` to GND with firmware
   idle: it should read close to 24 V. Check that the SSR's DC input
   *operating* range reaches 26.4 V, the HDR-15-24 at full +10 % trim. The
   amber board LEDs show true drive state.
4. Megger/continuity-check the mains side with the SELV loom
   disconnected, prove the over-temp cutout drops the contactor, then
   fire the bench smoke test (`docs/bench-smoke-test.md`) before the
   first real firing.

## Revision 2 — touch-only door

A v2 door with **no buttons at all**: the 5-way nav switch is gone and the
MSP4021's own resistive touch panel is the only local input. Everything on
the back panel — PSU, SSRs, heatsinks, mains distribution, CTs, thermal
design, grounding — is **unchanged**. Only the door changes.

Drill from **`door-template-touch.svg`**, not `door-template.svg`.

### It needs no board respin

`J5` already carries the complete XPT2046 pin set: pins 10–14 are
`T_CLK`/`T_CS`/`T_DIN`/`T_DO`/`T_IRQ`, with the touch controller on the
display module itself and `T_CLK`/`T_DIN`/`T_DO` sharing SPI2 through the
33 Ω damping resistors. Only `T_CS` (GPIO 5) and `T_IRQ` (GPIO 6) are
dedicated. So rev 2 is a **panel and firmware change on the existing rev B
board** — `J6` is simply left unpopulated and its loom deleted. Nothing to
depopulate, no net left floating that wasn't already pulled up: the five
`BTN_*` pins keep the ESP32's internal pull-ups and read as "not pressed"
forever.

### The window becomes an opening, and that is the whole design problem

Rev 1 bonds a 2 mm polycarbonate pane behind an oversized cutout. **A
resistive panel cannot work behind that** — it responds to pressure on its
own surface, so the glass has to be reachable. Two consequences:

- **The cutout shrinks to the active area.** Rev 1's 86 × 58 mm window
  becomes **84.5 × 56.7 mm**, the 83.52 × 55.68 mm active area plus 0.5 mm
  all round. Bigger is not better here — see the land, below.
- **A thin overlay is still allowed, a rigid one is not.** A ≤ 0.5 mm PET
  film bonded to the door face restores dust sealing and costs little
  sensitivity. Anything with real stiffness (a 2 mm pane, an acrylic
  bezel) spreads the load and kills it. Do not reuse rev 1's pane.

**The tight dimension is the gasket land, and it is tight.** The MSP4021's
active area nearly fills its PCB vertically: 61.74 mm of PCB against
55.68 mm of glass leaves only 3.03 mm above and below. After the cutout's
0.5 mm margin, the steel overlaps the module by **2.53 mm top and bottom**
(left and right get a comfortable 11.8 mm). That 2.53 mm is the entire
sealing and clamping land, so:

- Use a **soft closed-cell silicone or EPDM gasket, ~1 mm**, die-cut to the
  module outline with the cutout removed — not a bead of sealant, which
  will squeeze into the active area.
- **Clamp through the module's four M3 holes onto standoffs**, drawing the
  module up against the door. Do not clamp the glass edge.
- **Deburr and lightly chamfer the cutout.** 1.5 mm of raw sheared steel
  sits directly against the panel a hair outside the touch area, and the
  operator's finger crosses it on every press.
- **Keep touch targets ≥ 3 mm inside the active area** in firmware. The
  outer ~0.5 mm sits under the steel lip and cannot be pressed reliably.
  That is good UI practice anyway; here it is a mechanical constraint.

### Keep the panel resistive

Resistive is usually the compromise choice, but for this application it is
the right one: **it works through gloves**, which a capacitive panel does
not, and gloves are normal around a kiln. It is also indifferent to the
dust that a ceramics studio guarantees. Do not "upgrade" rev 2 to
capacitive without solving the glove problem first.
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

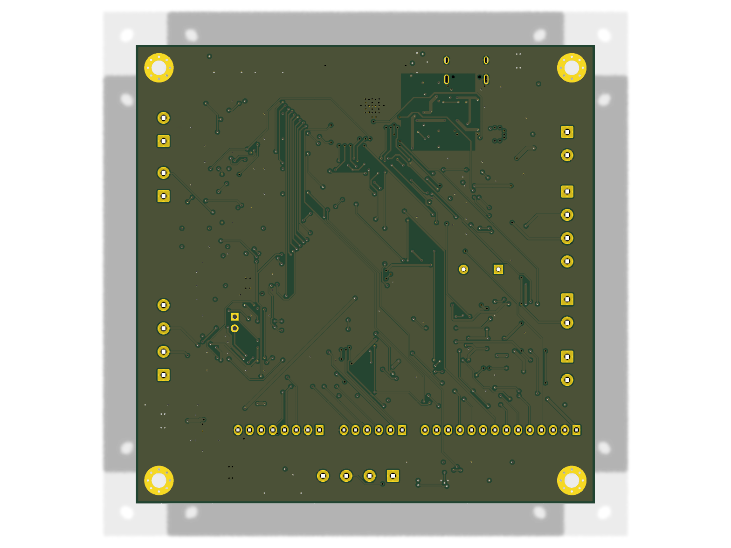
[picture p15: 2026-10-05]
hardware/kicad/3d/board-3d-bottom.png

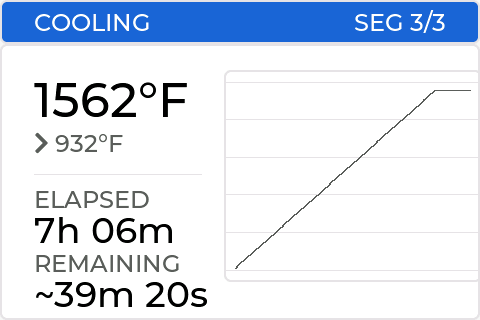
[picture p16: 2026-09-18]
docs/screenshots/lcd-cooling.png

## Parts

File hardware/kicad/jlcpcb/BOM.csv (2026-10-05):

Comment | Designator | Footprint | LCSC Part # | Notes
22uF/25V | C1,C3 | C_1206_3216Metric | C12891 | CL31A226KAHNNNE 22uF 25V X5R 1206
10nF | C16,C17,C21,C22 | C_0805_2012Metric | C1710 | CL21B103KBANNNC 10nF 50V X7R 0805
4.7uF | C27,C29,C33 | C_0805_2012Metric | C1779 | CL21A475KAQNNNE 4.7uF 25V X5R 0805
33nF | C31,C40,C32 | C_0805_2012Metric | C1739 | 0805B333K500NT 33nF 50V X7R 0805
10uF/50V | C41,C42 | C_1206_3216Metric | C13585 | CL31A106KBHNNNE 10uF 50V X5R 1206
100nF | C43,C2,C4,C6,C13,C14,C15,C18,C19,C20,C39,C10,C12,C23,C24,C25,C28,C30,C34,C36 | C_0805_2012Metric | C49678 | CC0805KRX7R9BB104 100nF 50V X7R 0805
22uF | C44,C45,C38 | C_1206_3216Metric | C12891 | CL31A226KAHNNNE 22uF 25V X5R 1206
100uF/16V | C46 | CP_Elec_5x5.4 | C2977550 | RVT1C101M0505 100uF 16V D5x5.4 aluminium electrolytic
1uF | C47,C48 | C_0402_1005Metric | C52923 | CL05A105KA5NQNC 1uF 25V X5R 0402
1uF | C5,C37 | C_0805_2012Metric | C28323 | CL21B105KBFNNNE 1uF 50V X7R 0805
10uF | C7,C35,C11 | C_0805_2012Metric | C15850 | CL21A106KAYNNNE 10uF 25V X5R 0805
BZT52C8V2 | D11 | D_SOD-323 | C22375294 | BZT52C8V2S 8.2V 200mW zener SOD-323
SS34 | D7 | D_SMA | C8678 | SS34 40V 3A Schottky SMA - U11 catch diode
SMAJ30A | D8 | D_SMA | C19077547 | SMAJ30A 30V 400W unidirectional TVS SMA
1N4148W | D9,D10,D4,D3 | D_SOD-123 | C81598 | 1N4148W SOD-123 - SSR1 terminal freewheel
750mA/33V | F1 | Fuse_1812_4532Metric | C369169 | JK-mSMD075-33 PPTC 750mA hold / 1.5A trip, 33V, 1812
USB-C | J1 | USB_C_Receptacle_HRO_TYPE-C-31-M-12 | C165948 | HRO TYPE-C-31-M-12 USB-C 16P
QWIIC | J14 | JST_SH_SM04B-SRSS-TB_1x04-1MP_P1.00mm_Horizontal | C160404 | JST SM04B-SRSS-TB(LF)(SN) SH 1x04
47uH/2A | L1 | L_Changjiang_FXL0650 | C475527 | FXL0650-470-M 47uH 2A 2.6A-sat 230mohm 7x6.6mm
green | LED2 | LED_0805_2012Metric | C2297 | KT-0805G green LED 0805
amber | LED3,LED4 | LED_0805_2012Metric | C2296 | KT-0805Y amber LED 0805
AO3400A | Q3,Q2 | SOT-23 | C20917 | AO3400A SOT-23
CJ2310 | Q5,Q6,Q7 | SOT-23 | C75882 | CJ2310 60V 3A N-channel SOT-23
AO3401A | Q8,Q4 | SOT-23 | C15127 | AO3401A P-channel SOT-23 - reverse polarity
100R | R11 | R_0805_2012Metric | C17408 | 100R 0805 1%
100R 1% | R14,R15,R16,R17 | R_0805_2012Metric | C17408 | 100R 0805 1%
330R | R3 | R_0805_2012Metric | C17630 | 330R 0805 1%
5R1 | R31,R34 | R_0805_2012Metric | C17724 | 0805W8F510KT5E 5.1R 0805 1%
33 | R39,R40,R41,R42,R43,R54,R55,R56,R57,R58 | R_0805_2012Metric | C17634 | 33R 0805 1%
5.1k | R4,R5 | R_0805_2012Metric | C27834 | 5.1k 0805 1%
220R | R6,R19 | R_0805_2012Metric | C17557 | 220R 0805 1%
100k | R62,R22,R49,R46,R48,R47 | R_0805_2012Metric | C149504 | 100k 0805 1%
30k | R63 | R_0805_2012Metric | C17621 | 30k 0805 1%
10k | R64,R1,R2,R10,R21,R18,R23,R24,R25,R8,R13,R27,R29,R30,R37,R38,R50,R51,R52,R53 | R_0805_2012Metric | C17414 | 10k 0805 1%
4.7k | R7,R20,R44,R45 | R_0805_2012Metric | C17673 | 4.7k 0805 1%
1k | R9,R12,R26,R28,R32,R33,R59,R60,R61,R35,R36 | R_0805_2012Metric | C17513 | 1k 0805 1%
RESET | SW1 | SW_Push_1P1T_XKB_TS-1187A | C318884 | TS-1187A-B-A-B 5.1x5.1mm SMD tactile switch
BOOT | SW2 | SW_Push_1P1T_XKB_TS-1187A | C318884 | TS-1187A-B-A-B 5.1x5.1mm SMD tactile switch
ESP32-S3-WROOM-1U-N16R2 | U1 | ESP32-S3-WROOM-1U | C3013945 | ESP32-S3-WROOM-1U-N16R2 (16MB flash, 2MB quad PSRAM, U.FL)
SN74LVC1G123 | U10 | SSOP-8_2.95x2.8mm_P0.65mm | C123302 | SN74LVC1G123DCTR retriggerable monostable SSOP-8
XL1509-5.0E1 | U11 | SOIC-8_3.9x4.9mm_P1.27mm | C61063 | XL1509-5.0E1 4.5-40Vin 5V fixed 2A 150kHz buck SOIC-8
TPS2116DRLR | U12 | SOT-583-8 | C3235557 | TPS2116DRLR 2.5A power mux SOT-583
TLV1117LV33 | U2 | SOT-223-3_TabPin2 | C48937499 | TLV1117LV33DCYR SOT-223 LDO (700mV max dropout)
MAX31856MUD+ | U3,U5 | TSSOP-14_4.4x5mm_P0.65mm | C2653162 | MAX31856MUD+T TSSOP-14
SRV05-4 | U4,D5,D6 | SOT-23-6 | C7420376 | SRV05-4 TVS array SOT-23-6
ULN2003A | U6 | SOIC-16_3.9x9.9mm_P1.27mm | C7512 | ULN2003ADR SOIC-16 Darlington array
ADE7953ACPZ | U7 | QFN-28-1EP_5x5mm_P0.5mm_EP3.1x3.1mm | C515890 | ADE7953ACPZ-RL LFCSP-28 energy metering
TLP291 | U8,U9 | SOP-4_4.4x2.6mm_P1.27mm | C55144 | TLP291(GB-TP,SE) optocoupler CTR 100-400% (rank GB) SOP-4
3.579545MHz XO | Y1 | Oscillator_SMD_Abracon_ASE-4Pin_3.2x2.5mm | C2838127 | TFOM3.579545M4RHKCNT2T 3.579545MHz XO SMD3225-4P

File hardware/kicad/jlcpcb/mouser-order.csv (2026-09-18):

Mfr Part Number | Quantity | Manufacturer | Description | Customer Part Number
CMI-1295-0585T | 1 | Same Sky | active magnetic buzzer, 5V, 12x9.5mm THT, 7.6mm pitch | BZ1
1715721 | 5 | Phoenix Contact | MKDS 1,5/2-5,08 screw terminal block, 1x02, 5.08mm, horizontal | J2,J3,J4,J8,J9
22-27-2141 | 1 | Molex | KK 254 vertical friction-lock header, 1x14, 2.54mm (AE-6410-14A) | J5
22-27-2061 | 1 | Molex | KK 254 vertical friction-lock header, 1x06, 2.54mm (AE-6410-06A) | J6
22-27-2081 | 1 | Molex | KK 254 vertical friction-lock header, 1x08, 2.54mm (AE-6410-08A) | J7
1715747 | 3 | Phoenix Contact | MKDS 1,5/4-5,08 screw terminal block, 1x04, 5.08mm, horizontal | J10,J11,J12
22-01-3147 | 1 | Molex | KK 254 crimp housing, 14 ckt, friction ramp with polarizing ribs (2695-14RP) | J5
22-01-3067 | 1 | Molex | KK 254 crimp housing, 6 ckt, friction ramp with polarizing ribs (2695-06RP) | J6
22-01-3087 | 1 | Molex | KK 254 crimp housing, 8 ckt, friction ramp with polarizing ribs (2695-08RP) | J7
08-50-0114 | 35 | Molex | KK 254 female crimp terminal, 30-22 AWG, tin (series 2759) | J5,J6,J7

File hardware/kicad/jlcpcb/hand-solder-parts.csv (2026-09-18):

Kind | Designator | Comment | Footprint | LCSC Part # | Qty per board | Description | Mouser MPN | Mouser Manufacturer | Notes
board | BZ1 | active 5V | Buzzer_12x9.5RM7.6 | C96093 | 1 | TMB12A05 active magnetic buzzer 5V 12mm THT P7.6 | CMI-1295-0585T | Same Sky | 12x9.5mm body, 7.6mm pitch, 5V THT active - datasheet-verified
board | J2,J3,J4,J8,J9 | 24V_IN / TC1_K / SSR1 / TC2_K / SSR2 | TerminalBlock_Phoenix_MKDS-1,5-2-5.08_1x02_P5.08mm_Horizontal | C8465 | 5 | WJ500V-5.08-2P 5.08mm screw terminal 1x02 | 1715721 | Phoenix Contact | MKDS 1,5/2-5,08 - the part this footprint is named for
board | J5 | DISPLAY | Molex_KK-254_AE-6410-14A_1x14_P2.54mm_Vertical | C17701004 | 1 | XD-2510-14A KK-254 friction-lock wafer 1x14 | 22-27-2141 | Molex | genuine KK-254 1x14 (AE-6410-14A); LCSC line is an XD-2510-14A clone
board | J6 | NAV_SW | Molex_KK-254_AE-6410-06A_1x06_P2.54mm_Vertical | C239381 | 1 | A2547WV-6P KK-254 friction-lock wafer 1x06 | 22-27-2061 | Molex | genuine KK-254 1x06; LCSC line is an A2547WV clone
board | J7 | AUX | Molex_KK-254_AE-6410-08A_1x08_P2.54mm_Vertical | C240822 | 1 | Molex 22-27-2081 KK-254 friction-lock wafer 1x08 | 22-27-2081 | Molex | identical part - the LCSC line is already genuine Molex
board | J10,J11,J12 | AUX / INPUTS / CT | TerminalBlock_Phoenix_MKDS-1,5-4-5.08_1x04_P5.08mm_Horizontal | C42377749 | 3 | WJ500V-5.08-04P 5.08mm screw terminal 1x04 | 1715747 | Phoenix Contact | MKDS 1,5/4-5,08 - the part this footprint is named for
board | LED1 | WS2812B | LED_WS2812B_PLCC4_5.0x5.0mm_P3.2mm | C2761795 | 1 | WS2812B-B/T 5050 RGB |  |  | NOT AT MOUSER - source from LCSC, DigiKey, Adafruit or SparkFun
mating | J5 | DISPLAY mate |  |  | 1 | KK 254 crimp housing, 14 ckt, friction ramp with polarizing ribs (2695-14RP) | 22-01-3147 | Molex | mates J5, the 22-27-2141 header on the board
mating | J6 | NAV_SW mate |  |  | 1 | KK 254 crimp housing, 6 ckt, friction ramp with polarizing ribs (2695-06RP) | 22-01-3067 | Molex | mates J6, the 22-27-2061 header on the board
mating | J7 | AUX mate |  |  | 1 | KK 254 crimp housing, 8 ckt, friction ramp with polarizing ribs (2695-08RP) | 22-01-3087 | Molex | mates J7, the 22-27-2081 header on the board
mating | J5,J6,J7 | loom terminals |  |  | 28 | KK 254 female crimp terminal, 30-22 AWG, tin (series 2759) | 08-50-0114 | Molex | one per circuit across J5,J6,J7; Molex-obsolete but the only tin terminal Mouser sells at MOQ 1 - the active successor 08-50-0113 is reel-only there, and 08-55-0102 is active/bagged/MOQ 1 but gold onto a tin pin

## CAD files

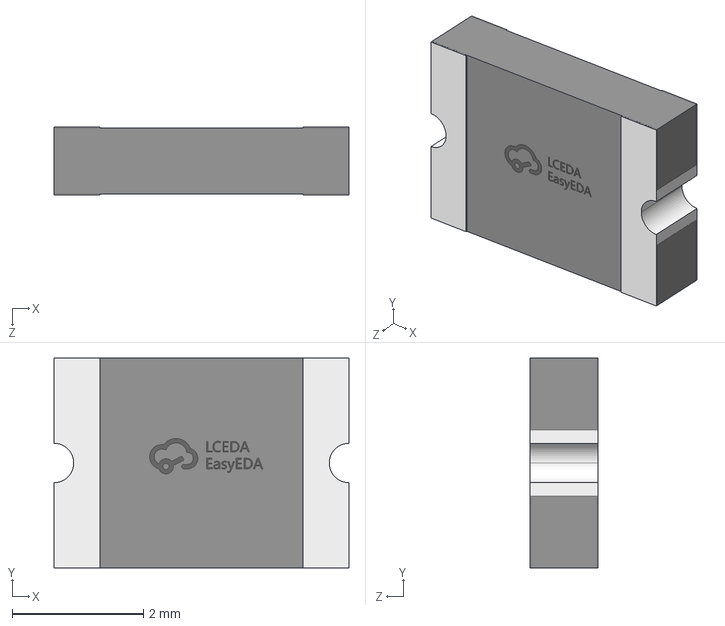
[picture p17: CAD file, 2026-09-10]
hardware/kicad/3dmodels/Fuse_1812_4532Metric.step
4.50 x 3.20 x 1.04 mm

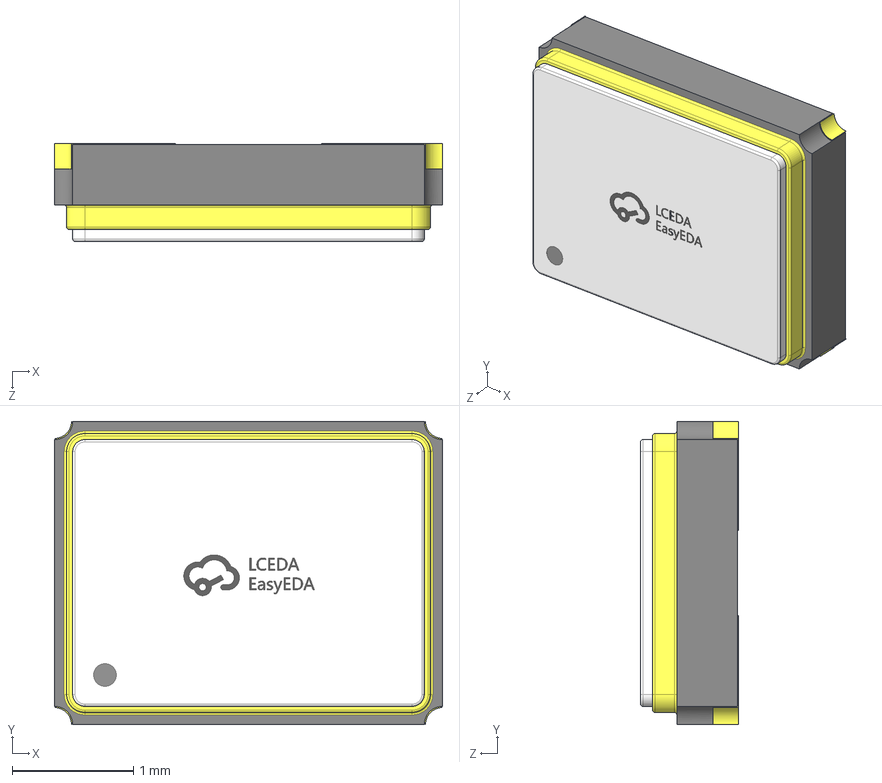
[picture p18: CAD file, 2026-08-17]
hardware/kicad/3dmodels/Oscillator_SMD_Abracon_ASE-4Pin_3.2x2.5mm.step
3.20 x 2.50 x 0.811 mm

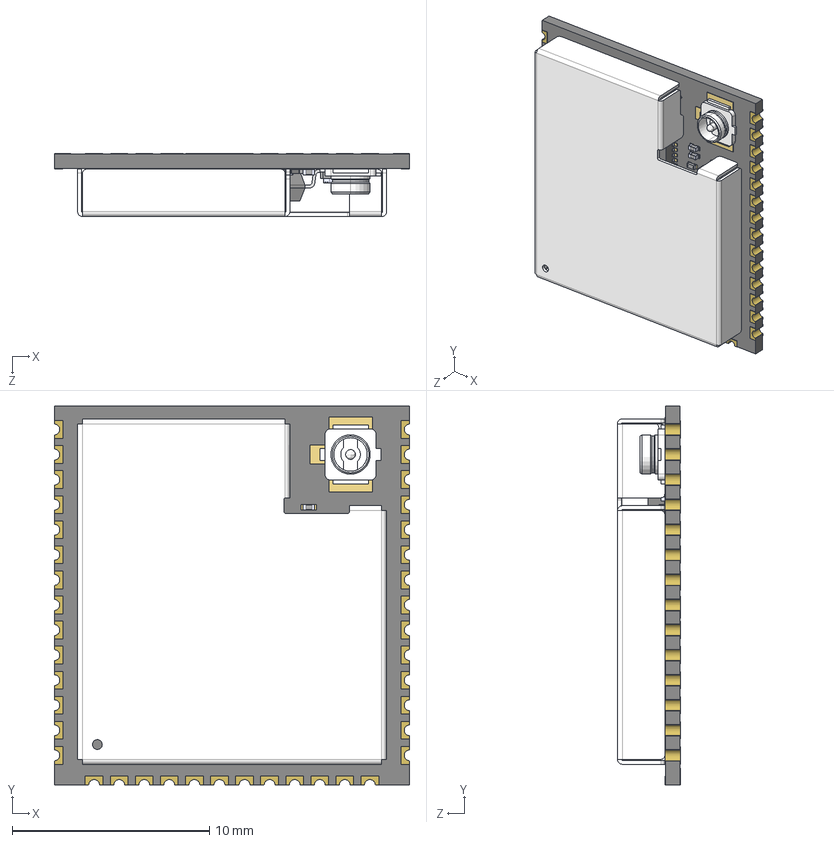
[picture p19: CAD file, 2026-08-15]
hardware/kicad/3dmodels/ESP32-S3-WROOM-1U.step
18.0 x 19.2 x 3.20 mm
R0201_20210301.STEP^R0201_20210301.STEP_Submodel-R0201_part_DesignRootModel_ESP32-S3-WROOM-1U(2)_ESP32-S3-WROOM-1U_2 x 8
L0201_20210301.STEP^L0201_20210301.STEP_Submodel-L0201_part_DesignRootModel_ESP32-S3-WROOM-1U(2)_ESP32-S3-WROOM-1U_2 x 2
C0201_20210301.STEP^C0201_20210301.STEP_Submodel-C0201_part_DesignRootModel_ESP32-S3-WROOM-1U(2)_ESP32-S3-WROOM-1U_2 x 13
C0402_20210301.STEP^C0402_20210301.STEP_Submodel-C0402_part_DesignRootModel_ESP32-S3-WROOM-1U(2)_ESP32-S3-WROOM-1U_2
I-IPEX.STEP^I-IPEX.STEP_Submodel-IPEX_3P_part_DesignRootModel_ESP32-S3-WROOM-1U(2)_ESP32-S3-WROOM-1U_2
DFN1006.STEP^DFN1006.STEP_Submodel-SOD882_part_DesignRootModel_ESP32-S3-WROOM-1U(2)_ESP32-S3-WROOM-1U_2
SOP8_rev1_20210308.STEP^SOP8_rev1_20210308.STEP_Submodel-SOP8_1P27_6P6_part_DesignRootModel_ESP32-S3-WROOM-1U(2)_ESP32-S3-WROOM-1U_2
ESP32-S3_20210301.STEP^ESP32-S3_20210301.STEP_Submodel-QFN56_0P4_7_part_DesignRootModel_ESP32-S3-WROOM-1U(2)_ESP32-S3-WROOM-1U_2
XTAL3225_20210301.STEP^XTAL3225_20210301.STEP_Submodel-XTAL3225_part_DesignRootModel_ESP32-S3-WROOM-1U(2)_ESP32-S3-WROOM-1U_2
uid__4-111^DesignRootModel_ESP32-S3-WROOM-1U(2)_ESP32-S3-WROOM-1U_2
uid__4-112^DesignRootModel_ESP32-S3-WROOM-1U(2)_ESP32-S3-WROOM-1U_2
uid__4-113^DesignRootModel_ESP32-S3-WROOM-1U(2)_ESP32-S3-WROOM-1U_2
uid__4-130^DesignRootModel_ESP32-S3-WROOM-1U(2)_ESP32-S3-WROOM-1U_2
uid__4-131^DesignRootModel_ESP32-S3-WROOM-1U(2)_ESP32-S3-WROOM-1U_2
uid__4-132^DesignRootModel_ESP32-S3-WROOM-1U(2)_ESP32-S3-WROOM-1U_2
uid__4-148^DesignRootModel_ESP32-S3-WROOM-1U(2)_ESP32-S3-WROOM-1U_2
uid__4-149^DesignRootModel_ESP32-S3-WROOM-1U(2)_ESP32-S3-WROOM-1U_2
uid__4-150^DesignRootModel_ESP32-S3-WROOM-1U(2)_ESP32-S3-WROOM-1U_2
uid__1-253^DesignRootModel_ESP32-S3-WROOM-1U(2)_ESP32-S3-WROOM-1U_2
uid__1-254^DesignRootModel_ESP32-S3-WROOM-1U(2)_ESP32-S3-WROOM-1U_2
uid__1-256^DesignRootModel_ESP32-S3-WROOM-1U(2)_ESP32-S3-WROOM-1U_2
uid__1-257^DesignRootModel_ESP32-S3-WROOM-1U(2)_ESP32-S3-WROOM-1U_2
uid__1-266^DesignRootModel_ESP32-S3-WROOM-1U(2)_ESP32-S3-WROOM-1U_2
uid__1-269^DesignRootModel_ESP32-S3-WROOM-1U(2)_ESP32-S3-WROOM-1U_2
uid__1-270^DesignRootModel_ESP32-S3-WROOM-1U(2)_ESP32-S3-WROOM-1U_2
uid__1-271^DesignRootModel_ESP32-S3-WROOM-1U(2)_ESP32-S3-WROOM-1U_2
uid__1-272^DesignRootModel_ESP32-S3-WROOM-1U(2)_ESP32-S3-WROOM-1U_2
uid__1-273^DesignRootModel_ESP32-S3-WROOM-1U(2)_ESP32-S3-WROOM-1U_2
uid__1-274^DesignRootModel_ESP32-S3-WROOM-1U(2)_ESP32-S3-WROOM-1U_2
uid__1-275^DesignRootModel_ESP32-S3-WROOM-1U(2)_ESP32-S3-WROOM-1U_2
uid__1-276^DesignRootModel_ESP32-S3-WROOM-1U(2)_ESP32-S3-WROOM-1U_2
uid__1-277^DesignRootModel_ESP32-S3-WROOM-1U(2)_ESP32-S3-WROOM-1U_2
uid__1-280^DesignRootModel_ESP32-S3-WROOM-1U(2)_ESP32-S3-WROOM-1U_2
uid__1-292^DesignRootModel_ESP32-S3-WROOM-1U(2)_ESP32-S3-WROOM-1U_2
uid__1-293^DesignRootModel_ESP32-S3-WROOM-1U(2)_ESP32-S3-WROOM-1U_2
uid__1-297^DesignRootModel_ESP32-S3-WROOM-1U(2)_ESP32-S3-WROOM-1U_2
uid__1-300^DesignRootModel_ESP32-S3-WROOM-1U(2)_ESP32-S3-WROOM-1U_2
uid__1-301^DesignRootModel_ESP32-S3-WROOM-1U(2)_ESP32-S3-WROOM-1U_2
uid__1-302^DesignRootModel_ESP32-S3-WROOM-1U(2)_ESP32-S3-WROOM-1U_2
uid__1-303^DesignRootModel_ESP32-S3-WROOM-1U(2)_ESP32-S3-WROOM-1U_2
uid__1-307^DesignRootModel_ESP32-S3-WROOM-1U(2)_ESP32-S3-WROOM-1U_2
uid__1-313^DesignRootModel_ESP32-S3-WROOM-1U(2)_ESP32-S3-WROOM-1U_2
uid__1-319^DesignRootModel_ESP32-S3-WROOM-1U(2)_ESP32-S3-WROOM-1U_2
uid__1-320^DesignRootModel_ESP32-S3-WROOM-1U(2)_ESP32-S3-WROOM-1U_2
uid__1-321^DesignRootModel_ESP32-S3-WROOM-1U(2)_ESP32-S3-WROOM-1U_2
uid__1-328^DesignRootModel_ESP32-S3-WROOM-1U(2)_ESP32-S3-WROOM-1U_2
uid__1-332^DesignRootModel_ESP32-S3-WROOM-1U(2)_ESP32-S3-WROOM-1U_2
uid__1-333^DesignRootModel_ESP32-S3-WROOM-1U(2)_ESP32-S3-WROOM-1U_2
uid__1-334^DesignRootModel_ESP32-S3-WROOM-1U(2)_ESP32-S3-WROOM-1U_2
uid__1-335^DesignRootModel_ESP32-S3-WROOM-1U(2)_ESP32-S3-WROOM-1U_2
uid__1-336^DesignRootModel_ESP32-S3-WROOM-1U(2)_ESP32-S3-WROOM-1U_2
uid__1-337^DesignRootModel_ESP32-S3-WROOM-1U(2)_ESP32-S3-WROOM-1U_2
uid__1-338^DesignRootModel_ESP32-S3-WROOM-1U(2)_ESP32-S3-WROOM-1U_2
uid__1-339^DesignRootModel_ESP32-S3-WROOM-1U(2)_ESP32-S3-WROOM-1U_2
uid__1-340^DesignRootModel_ESP32-S3-WROOM-1U(2)_ESP32-S3-WROOM-1U_2
uid__1-341^DesignRootModel_ESP32-S3-WROOM-1U(2)_ESP32-S3-WROOM-1U_2
uid__1-342^DesignRootModel_ESP32-S3-WROOM-1U(2)_ESP32-S3-WROOM-1U_2
uid__1-343^DesignRootModel_ESP32-S3-WROOM-1U(2)_ESP32-S3-WROOM-1U_2
uid__1-344^DesignRootModel_ESP32-S3-WROOM-1U(2)_ESP32-S3-WROOM-1U_2
uid__1-345^DesignRootModel_ESP32-S3-WROOM-1U(2)_ESP32-S3-WROOM-1U_2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

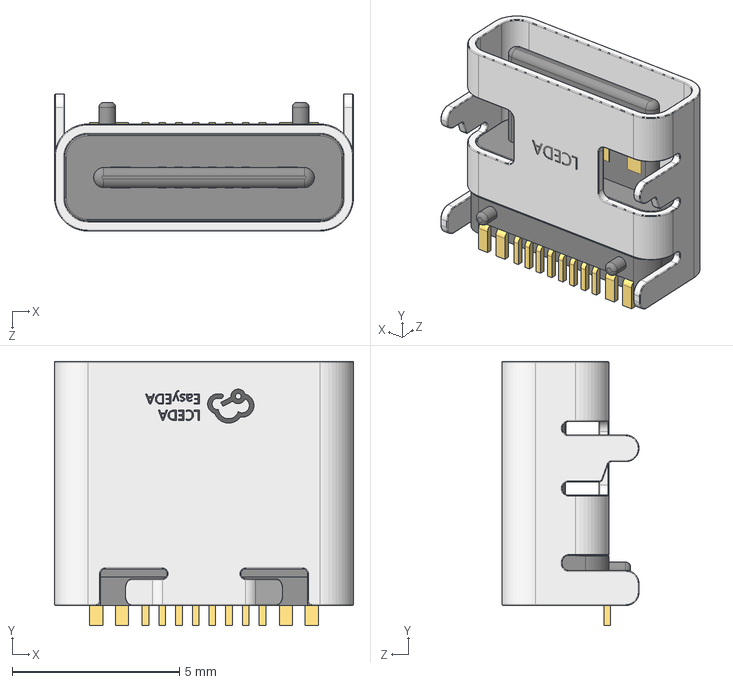
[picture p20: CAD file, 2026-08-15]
hardware/kicad/3dmodels/USB_C_Receptacle_HRO_TYPE-C-31-M-12.step
8.94 x 7.90 x 4.10 mm

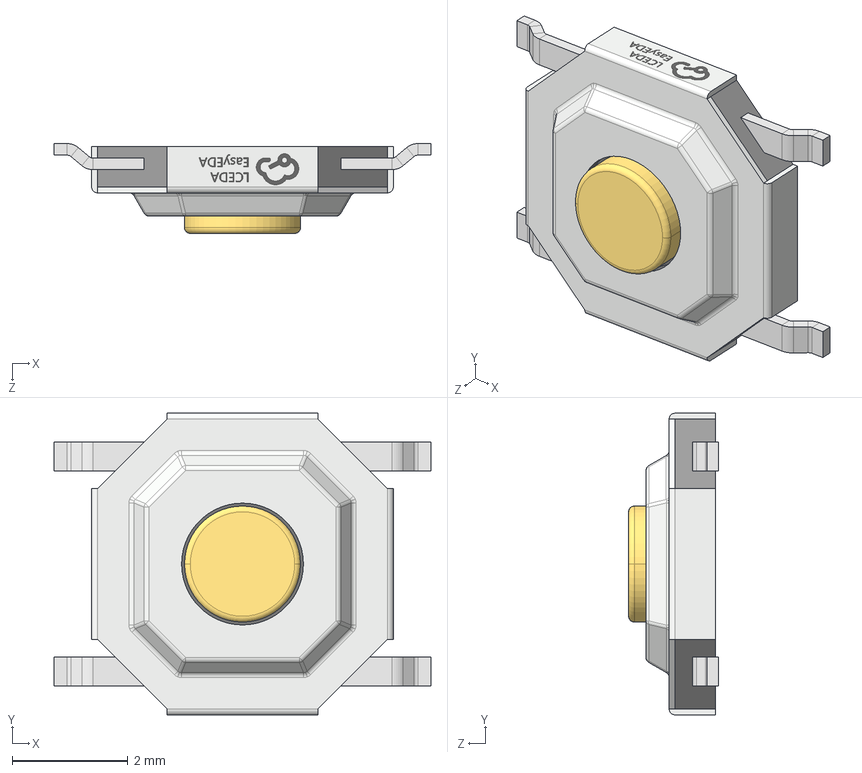
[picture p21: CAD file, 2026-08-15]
hardware/kicad/3dmodels/SW_Push_1P1T_XKB_TS-1187A.step
6.50 x 5.20 x 1.55 mm

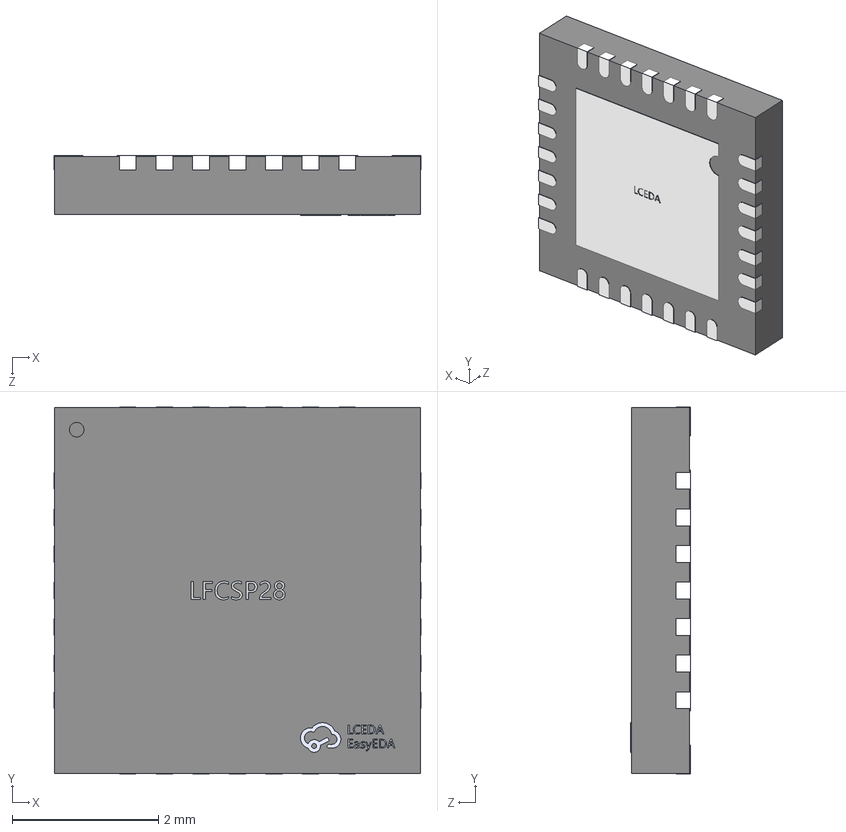
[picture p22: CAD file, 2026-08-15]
hardware/kicad/3dmodels/QFN-28-1EP_5x5mm_P0.5mm_EP3.1x3.1mm.step
5.02 x 5.02 x 0.82 mm

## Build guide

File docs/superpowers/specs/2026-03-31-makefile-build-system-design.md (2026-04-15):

# Makefile Build System Design

## Context

The monorepo currently uses `build.sh` to orchestrate builds across 3 components (web UI, ESP-IDF firmware, iOS app). This is fragile, doesn't support partial rebuilds, and duplicates commands already defined in CI. Replace it with a standard Makefile.

## Approach

Single flat root Makefile with `.PHONY` targets delegating to underlying tools (npm, idf.py, xcodebuild). No file-level dependency tracking at the Make level — each tool handles its own incrementality.

## Makefile Targets

### Build Targets

| Target | Depends On | Command |
|---|---|---|
| `all` (default) | `firmware` | — |
| `web` | — | `cd web_ui && npm ci && npm run build` |
| `gzip` | `web` | `find` + `gzip -9 -f` on JS/CSS/HTML/SVG in `spiffs_data/www/` |
| `firmware` | `gzip` | `idf.py build` |
| `flash` | `firmware` | `idf.py flash monitor` |
| `ios` | — | `cd ios/Bisque && xcodegen generate && xcodebuild ...` |

### Lint & Format Targets

| Target | Depends On | Command |
|---|---|---|
| `lint` | `lint-web lint-c` | — |
| `lint-web` | — | `cd web_ui && npm run typecheck && npm run lint && npm run format:check` |
| `lint-c` | — | `clang-format --dry-run --Werror` on `main/` and `components/` |
| `format` | `format-web format-c` | — |
| `format-web` | — | `cd web_ui && npm run format` |
| `format-c` | — | `clang-format -i` on `main/` and `components/` |
| `typecheck` | — | `cd web_ui && npm run typecheck` |

### Check Targets

| Target | Depends On | Command |
|---|---|---|
| `check` | `check-spiffs check-firmware` | — |
| `check-spiffs` | `gzip` | `./scripts/check-spiffs-size.sh` |
| `check-firmware` | `firmware` | `./scripts/check-firmware-size.sh` |

### Clean Targets

| Target | What it removes |
|---|---|
| `clean` | All build outputs |
| `clean-web` | `spiffs_data/www/*`, `web_ui/node_modules/` |
| `clean-firmware` | `idf.py fullclean` |
| `clean-ios` | `ios/Bisque/build/`, generated `.xcodeproj` |

## Dependency Chain

```
firmware → gzip → web    (sequential, mandatory)
ios                       (independent)
lint-web, lint-c          (independent, parallelizable)
```

## CI Changes

Update `.github/workflows/build.yml` to use Make targets where possible:

- `lint-web` job: `make lint-web` (still needs Node setup first)
- `lint-c` job: `make lint-c`
- `build` job: `make firmware && make check`
- `build-ios` job: `make ios` (still needs xcodegen install)

**Note:** The ESP-IDF CI action runs inside a Docker container, so `make firmware` needs `make` available in that container (it is — it's Ubuntu-based). The lint and web build steps run directly on the runner.

## What Gets Deleted

- `build.sh` — fully replaced by `make` / `make firmware`

## Design Decisions

- **All .PHONY:** The underlying tools (npm, idf.py, xcodebuild) all have their own incremental build caching. Adding file-level Make dependencies would add complexity for marginal (seconds) savings.
- **No recursive Make:** Single file is easier to maintain and understand for a small project.
- **npm ci vs npm install:** Keep `npm ci` for clean, reproducible installs (matches CI behavior).
- **gzip as separate target:** Keeps the web build and compression steps independently runnable, matching the existing `build.sh` structure.

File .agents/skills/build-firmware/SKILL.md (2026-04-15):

---
name: build-firmware
description: Build and validate ESP-IDF firmware
---

Build firmware: run `./build.sh` from the project root. Check for errors in output. If build fails, analyze the error and fix the source file before retrying.

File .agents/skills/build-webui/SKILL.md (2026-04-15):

---
name: build-webui
description: Build and validate web UI dashboard
---

Build web UI: cd into web_ui/ and run `npm run typecheck && npm run lint && npm run build`. Fix any TypeScript or lint errors before retrying.

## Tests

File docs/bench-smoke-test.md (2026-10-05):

# Bench Smoke Test

A one-page checklist for the manual hardware test that should run on the
bench before tagging a release. Verifies the parts that automated tests
*cannot* exercise: real SSR clicking, real thermocouple reading,
end-to-end firing flow, and history persistence across reboot.

This is **not** a pottery firing. It peaks at ~50°C, takes 3–8 minutes
wall-clock for a typical empty bench kiln, and tests the controller —
not the kiln, the elements, or your clay. Don't fire pottery with this
profile.

CI already covers everything else:

- Layers 1 & 2 — pure-logic + accelerated firing scenarios (`unit-host`)
- Layer 3 — API JSON contract (`unit-host` + `lint-web`)
- Layer 4 — UI screenshot regression (`ui-screenshots`)
- Layer 5 — Web UI schemas, hooks, and mock-server parity (`lint-web`)

If a green PR ships, the only thing left to verify on the bench is that
the firmware actually talks to the hardware. That's what this
checklist is for.

## Rev B board prerequisites

Skip this section on a rev A board. These checks apply to the rev B.2 board,
which carries `REV B.2` in its silk nameplate. Each item below stops the board
dead, damages it, or leaves an SSR that nothing on the board can turn off.
None of them is a firmware bug.

- [ ] **The supply is 24 V.** J2 feeds F1 → D8 → Q8 (reverse polarity) →
      `VIN_P`, which supplies U11 (the XL1509-5.0 buck) **and both SSR
      terminals**. Meter the PSU *before* landing the wire. 5 V there browns
      the board out, and anything above ~33 V takes out the TVS and the fuse.
- [ ] **The SSRs' control inputs take 24 V.** J4/J9 pin 1 is the 24 V input
      itself, up to 26.4 V at the HDR-15-24's full +10 % trim. Check the
      SSR's *operating* input range, not only the rated one: an SSR-40DA-class
      input is 3–32 V and fine, but a 5 V-only input is destroyed.
- [ ] **Each SSR's `−` is on its own `OUT` terminal and nowhere else.**
      J4/J9 pin 1 (`24V`) is always live, and the board switches the
      *return*. An SSR whose `−` reaches ground by any other route is on, and
      neither firmware nor the hardware watchdog can turn it off. That
      includes the PSU `−`, J2 `-`, a negative bus shared between the two
      SSRs, or a lead touching the enclosure, which is bonded to board GND.
      `+` to `24V`, `−` to `OUT`, one pair per SSR.
- [ ] **`SJ2` ("WDT DEFEAT") is open.** The SSR stage is gated by the U10
      one-shot, which firmware retriggers on GPIO 36 at 5 Hz. Open is the
      supervised (correct) state — see "Bring-up: leave SJ2 open" in
      [`hardware/kicad/jlcpcb/README.md`](../hardware/kicad/jlcpcb/README.md).
- [ ] **`SJ1` ("AUX=5V") is open** if anything is landed on J10 pin 1.
      Bridging it with an external 24 V coil rail present puts 24 V on `+5V`.
- [ ] **The lid input is satisfied.** `IN1` (J11 pin 1) is pulled up, so an
      unwired terminal reads *lid open* and the kiln will not heat. Fit the
      lid switch, jumper J11 pin 1 to J11 pin 4 (GND), or build with
      `KILN_PIN_LID_SWITCH=-1`.
- [ ] **Channel 2 is not driven by firmware yet.** Zone 2 support has not
      landed ([#310](https://github.com/BenSeverson/bisque/issues/310)), and
      rev B.2 no longer pins that line on the board. Firmware parks GPIO 21
      (SSR2) low at boot instead; the boot log says "Parked zone 2 SSR
      control low on GPIO 21". Confirm it with the "SSR2 stays off" check
      below before relying on J9.

## First power-up on board 1 (once only)

The 24 V front end, the buck, the reverse-polarity FET (Q8) and the
USB/buck power mux (U12) have never been built. Work through this section
with **J4/J9/J10 empty** and a current-limited bench supply at 24 V, with the
limit set around 300 mA.

**Test points:** TP1 `+3V3`, TP2 `+5V`, TP3 GND, TP9 `SSR1_CTRL`,
TP10 `SSR2_CTRL`, TP12 the watchdog timing node. `BUCK_5V`, the buck's own
output ahead of the mux, is not `+5V`; probe it at C44.

### Power stage

- [ ] **Idle draw.** Once booted with the display lit, expect roughly
      50–150 mA at 24 V. A supply sitting in current limit with nothing
      connected means stop and look.
- [ ] **Rails:** TP2 (`+5V`) 4.9–5.1 V, TP1 (`+3V3`) 3.2–3.4 V, C44
      (`BUCK_5V`) the same as TP2 to within a few tens of mV.
- [ ] **Q8 is switched on, not conducting through its body diode.** J4
      pin 1 (`VIN_P`) reads within ~50 mV of J2's `+`. If it is ~0.6 V
      below, the gate is not being pulled: check R62, and D11's orientation
      (cathode to `VIN_P`).
- [ ] **Scope `BUCK_5V`** at C44 under load (Wi-Fi associated, backlight on).
      Expect < ~100 mV of ripple at 150 kHz and **no** low-frequency
      envelope. Subharmonic wobble at a few kHz means the buck's loop is
      marginal and C46, the bulk electrolytic, is doing less than intended.
- [ ] **Check U2, U11 and Q8 by hand** after 10 minutes at temperature.
      U2 is warm (it dissipates ~0.5 W). U11 is warm. Q8 should be barely
      above ambient; if it is hot, it is running on its body diode.
- [ ] *Optional, board 1 only:* **reverse the supply** with the current
      limit at ~100 mA. The supply should sit in current limit (D8 conducting
      forward), the board should stay dark, and nothing should warm. Restore
      the polarity, and the board boots.

### USB/buck source selection (U12)

- [ ] **USB-C alone, J2 disconnected.** The board boots and enumerates, TP2
      reads close to the port's VBUS, and **C44 (`BUCK_5V`) stays near 0 V**.
      With the buck absent, MODE and PR1 are both at 0 V, and the TPS2116
      datasheet has the mux pass the higher input, which is USB. This check
      confirms that on hardware, and also proves the buck is not being
      back-fed. If the board is dead on USB alone, check U12 before anything
      else.
- [ ] **Both connected: the buck wins.** With 24 V and USB both present,
      TP2 reads the buck's 5.0 V, not the port's (often 5.1–5.2 V).
      Unplugging USB should not move it.
- [ ] **Switchover.** With USB attached, switch the 24 V off, then on again.
      The board must **not reset**: check that uptime (Settings → System, or
      `GET /api/v1/system`) carried on. If you have a scope on TP2, `+5V`
      should bottom out no lower than ~3.7 V **in both directions**; the
      return of 24 V dips it too, by design. If you can spare a second
      channel, probe VBUS at C47 while the 24 V comes back: C47/C48 are U12's
      input caps, and VBUS should not overshoot 6 V. On a board built before
      they were added (fab review A6), treat any overshoot as a stop.
- [ ] Bring the display up at a reduced SPI clock first if it is unstable.
      SCLK is a multi-drop net with two thermocouple stubs and ~150 mm of
      loom before the panel.

### Output stage and watchdog (before a real kiln)

Use an SSR with nothing on its load side. Failing that, use a dummy for
each channel: a 4.7 kΩ ¼ W resistor in series with an LED, wired `24V` →
LED anode, cathode → resistor → `OUT`. Flash the release build first. Every
check here runs at **idle**: firmware kicks the watchdog whenever its
supervision loop is healthy, firing or not, so `SSR_EN` (the watchdog's
permission rail) is live without starting a profile.

- [ ] **`OUT` is not grounded.** With firmware idle, meter J4 pin 2 (and
      J9 pin 2) to GND. Expect close to 24 V, a few volts less with nothing
      connected. **Near 0 V means that SSR's `−` has found ground** and the
      SSR is on with nothing able to stop it. Fix the wiring before anything
      else.
- [ ] **Idle is dark.** LED3/LED4 (the amber `SSR1`/`SSR2` indicators) and
      the SSRs' own input LEDs are off. A lit indicator at idle means either
      `SJ2` is bridged or `OUT` is grounded. Both indicators sit across the
      terminal, so they report what the channel is actually doing.
- [ ] **Watchdog cutoff with the MCU dead.** Hold RESET (SW1) and, while
      holding it, connect TP9 (`SSR1_CTRL`) to TP1 (`+3V3`) through 1 kΩ.
      That lights channel 1's opto as if firmware had asked for heat, so the
      expired watchdog is the only thing holding the channel off. **The SSR
      and LED3 must stay off.** Remove the resistor before releasing RESET.
      The firing below is the positive control: the same channel does come on
      when the watchdog is live.
- [ ] **Watchdog window.** Scope TP12 and `SSR_EN`. `SSR_EN` is R18's
      non-ground pad, which reads ~5 V while firmware runs. Press and hold
      RESET. The time from TP12's last retrigger to `SSR_EN`
      falling should be **1.65–2.71 s**. Record the number; it is the one
      safety-path figure that is extrapolated rather than specified.
- [ ] **SSR2 stays off.** With `SSR_EN` live, R20's non-ground pad
      (`SSR2_GATE`) reads **below 0.3 V**, and LED4 and the J9 dummy stay
      dark. If the gate sits higher, something is lifting GPIO 21 despite
      firmware parking it low: disconnect J9 and report it.

## Pre-flight

- [ ] Flash the release build (`./build.sh && idf.py flash`).
- [ ] LCD boots, shows the idle dashboard.
- [ ] Thermocouple reads a sensible room temperature (15–30°C) — not 0,
      not 1000, no fault icon.
- [ ] SSR is wired and its input LED (or audible click) is observable from
      the bench. On rev B the board has **two** channels (J4 = zone 1,
      J9 = zone 2) with amber indicators LED3/LED4. The firmware drives
      zone 1 only, so LED4 staying dark is expected.
- [ ] The `SSR1` indicator (LED3) is **off** at idle. If it is lit before
      any firing starts, `SJ2` is bridged or J4's `OUT` is grounded (see
      above). Neither is something firmware can override.

## Load the smoke-test profile

Either import the JSON or type the values into the web UI.

The profile is in [`docs/smoke-test-profile.json`](smoke-test-profile.json):

| Segment | Ramp rate | Target | Hold |
|---|---|---|---|
| Heat | 600 °C/hr | 50 °C  | 0 m  |
| Cool | −300 °C/hr | 30 °C | 0 m  |

To import: web UI → Profiles → Import → upload the JSON, **or**:

```bash
curl -X POST http://<kiln-ip>/api/v1/profiles/import \
  -H 'Content-Type: application/json' \
  -d @docs/smoke-test-profile.json
```

## Run the firing

- [ ] Start the **Smoke Test** profile (web UI or LCD action menu).
- [ ] **SSR clicks on** within ~5 s of start (LED on / audible click).
- [ ] LCD dashboard shows `heating` status, temperature climbs.
- [ ] Temperature reaches ~50°C and the **status changes to `cooling`**
      (segment 1 → segment 2 advance).
- [ ] **SSR clicks off** during cooling — the dashboard should show the
      relay disengaged. Temperature drifts back down passively.
- [ ] When the kiln cools to ~30°C, status transitions to `complete`.
      (If your kiln cools slowly, this can take a while; the segment
      advance from `heating` → `cooling` is the more important check.
      Press the on-screen Stop button if you don't want to wait for
      the cool segment to finish naturally.)
- [ ] **BZ1 sounds on completion** — three ~500 ms beeps, 200 ms apart, at
      a clear steady volume. A weak or raspy buzz means the alarm pin is
      being chopped rather than held
      ([#342](https://github.com/BenSeverson/bisque/issues/342)).
- [ ] **No error events** during the run (no `error` status, no fault
      banner on the LCD).

## Verify persistence

- [ ] Open the History screen on the LCD or `GET /api/v1/history` — the
      smoke run is recorded with `outcome: "complete"` (or `aborted` if
      you pressed Stop), peak ~50°C, plausible duration.
- [ ] **Power-cycle the controller.** After it boots, the same history
      record is still present.

## Done

If every checkbox passed, the firmware is ready for a release tag.

If anything failed — SSR didn't click, thermocouple read wrong, segment
didn't advance, history vanished after reboot — open an issue with the
checkbox you stopped at and what you observed. Don't tag the release.

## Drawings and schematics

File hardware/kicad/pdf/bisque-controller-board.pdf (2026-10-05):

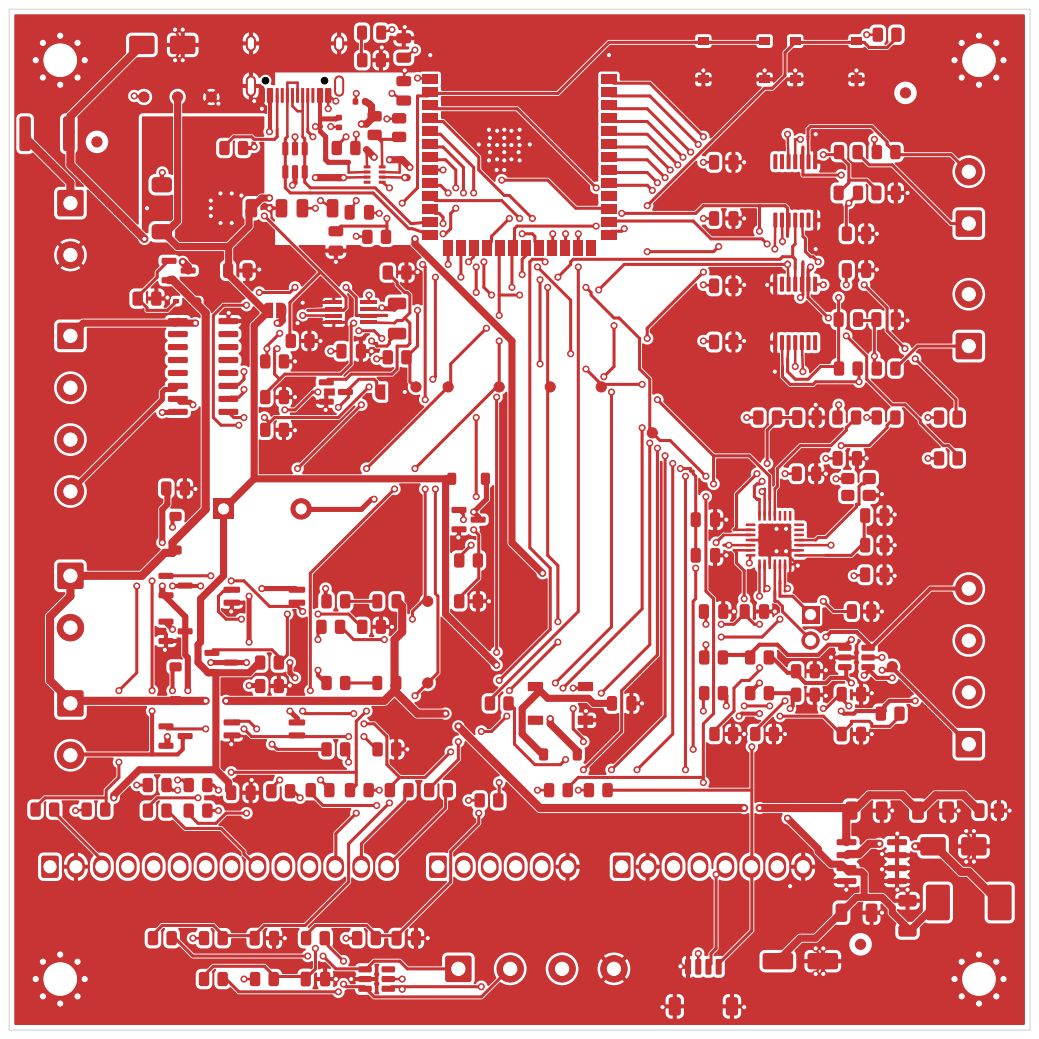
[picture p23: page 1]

4-layer, 100 x 100 mm, JLCPCB standard process
ESP32-S3-WROOM-1U-N16R2 + 2x MAX31856 + dual SSR + ADE7953
Bisque project
Sheet:
File: bisque-controller.kicad_pcb
Title: Bisque Kiln Controller

Size: A4 | Rev: B
KiCad E.D.A. 10.0.6 | Id: 1/6

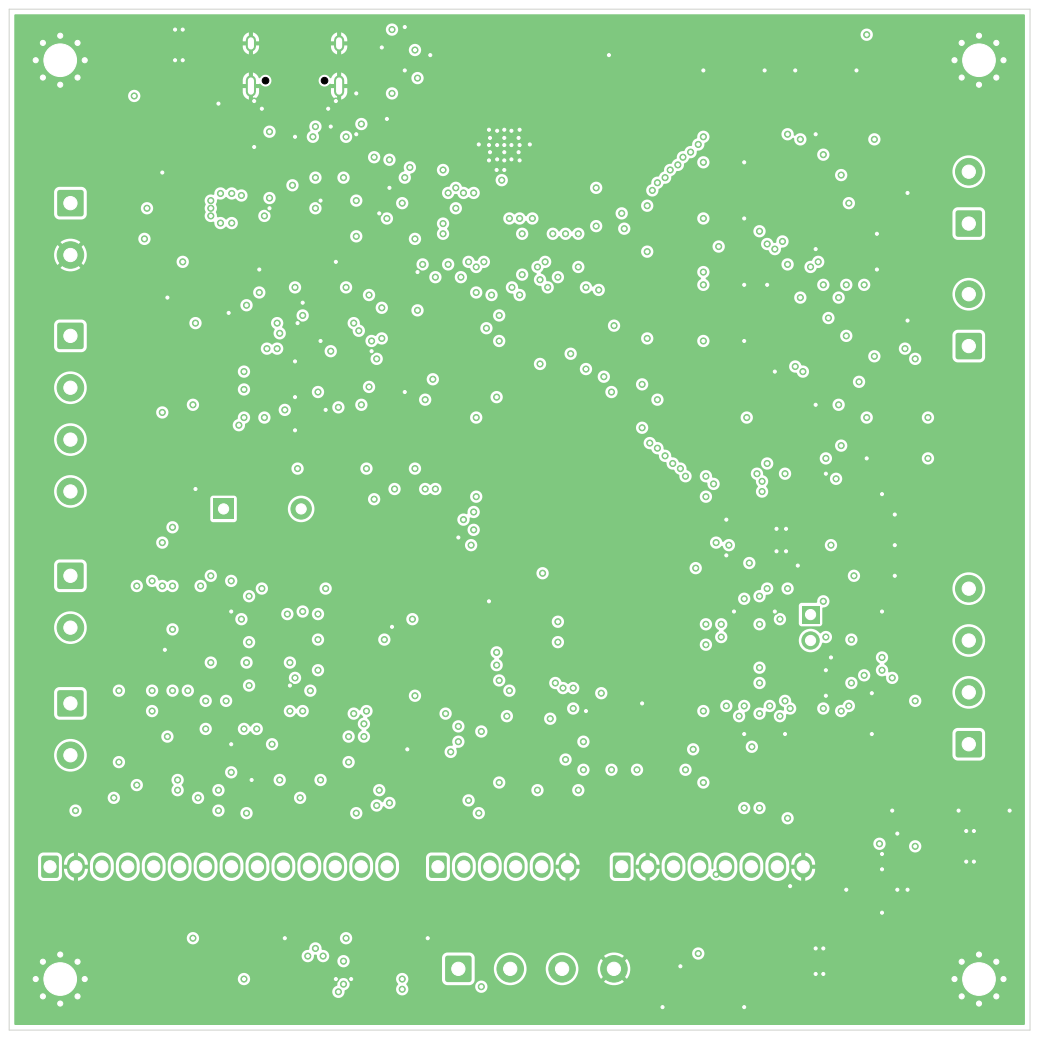
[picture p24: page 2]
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

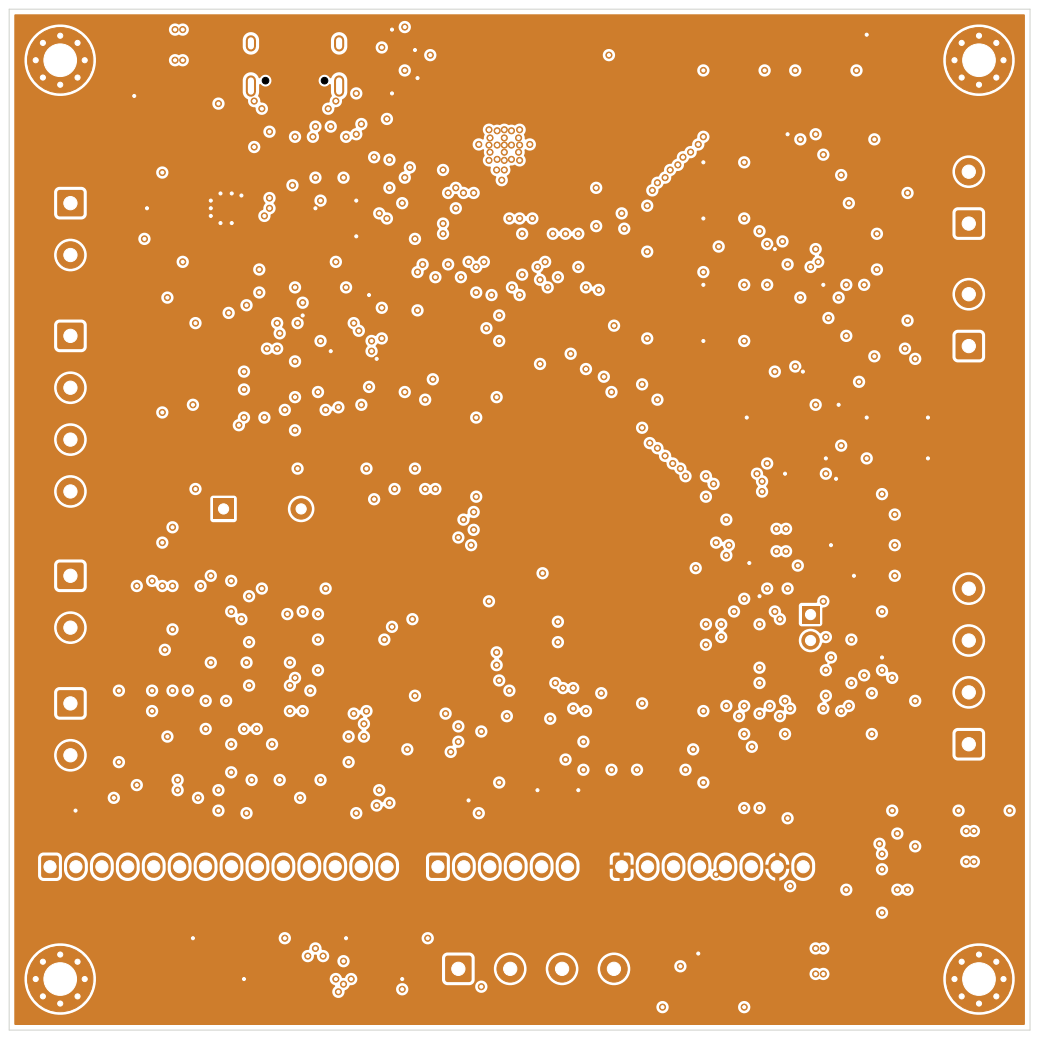
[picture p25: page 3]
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

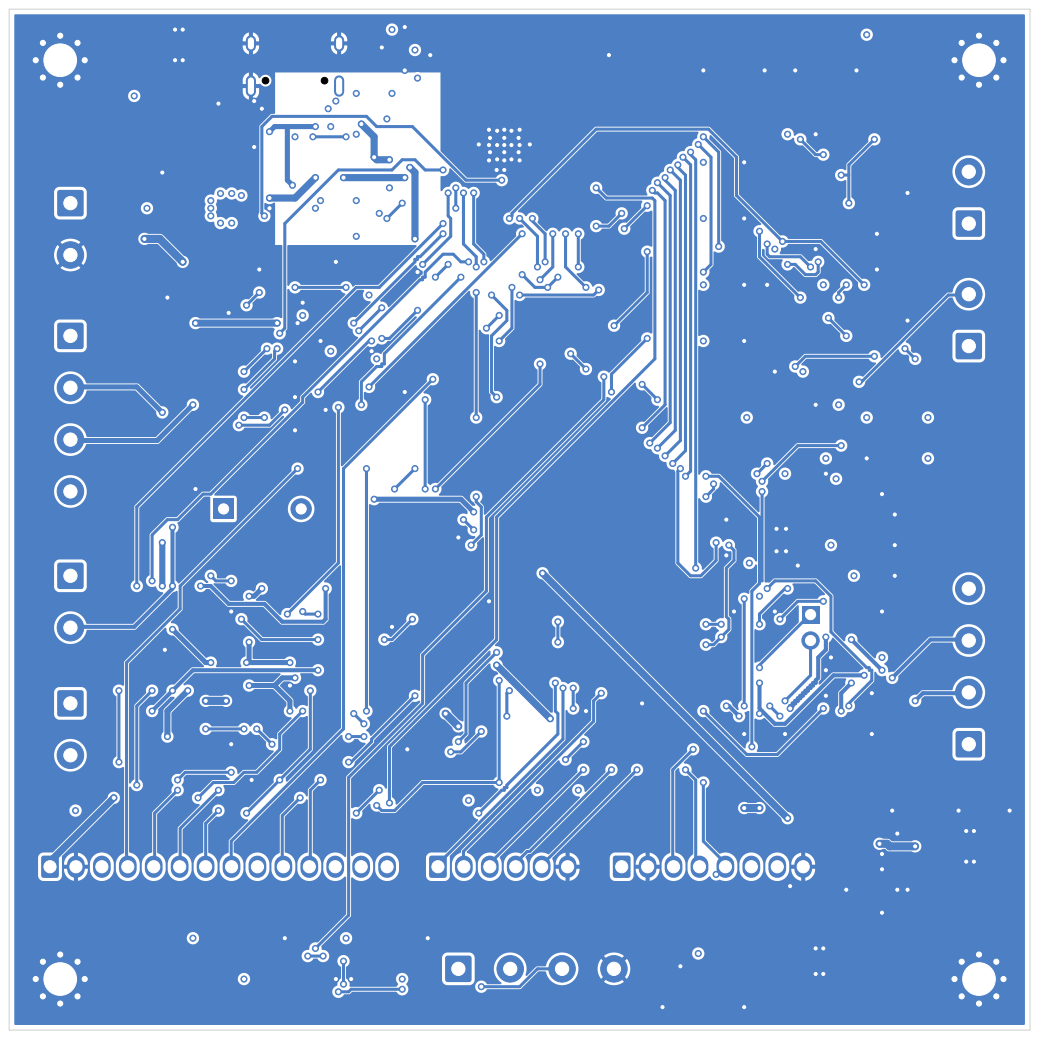
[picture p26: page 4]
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

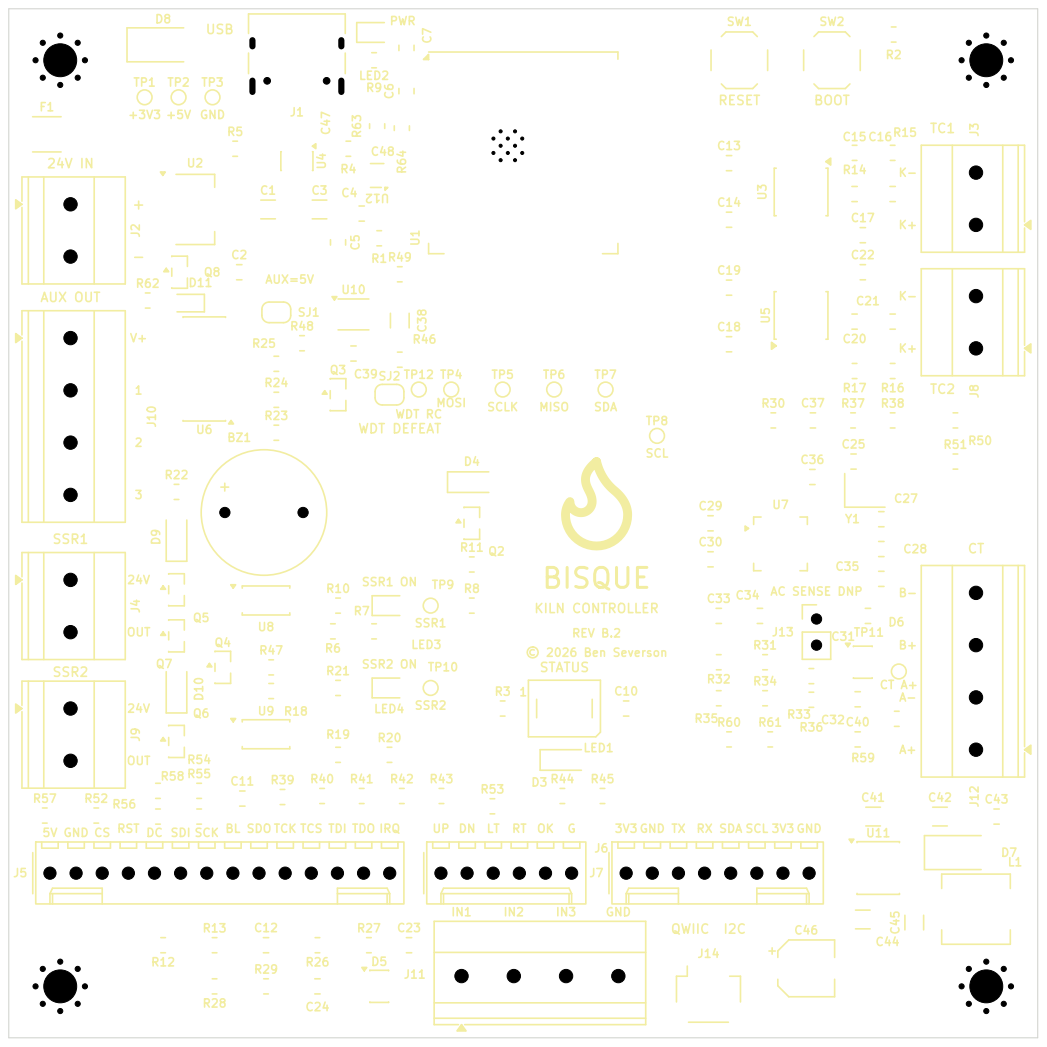
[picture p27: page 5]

+5V SDI SCK
REV B.2 © 2026 Ben Severson SDAGND

TX RX SDA SCL 3V3 GND

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

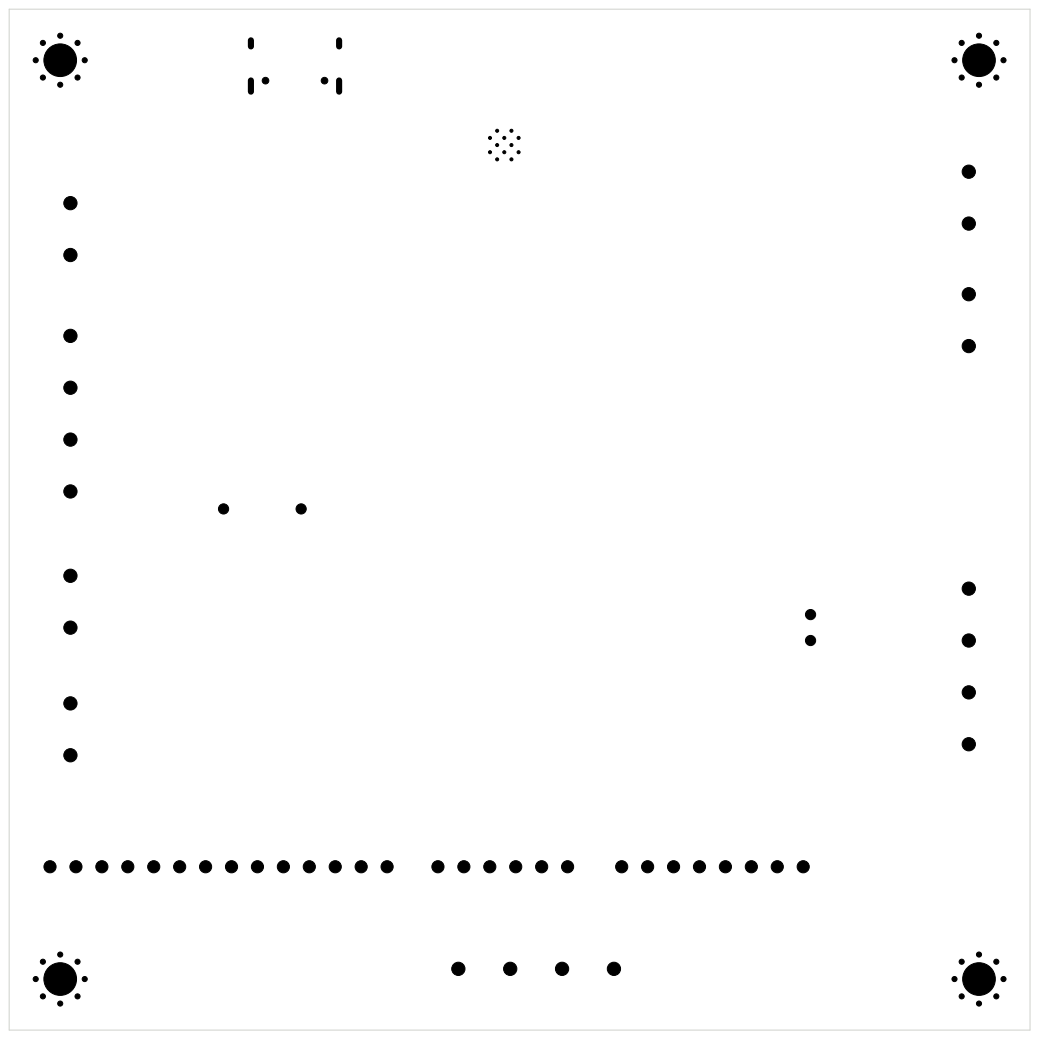
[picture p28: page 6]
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

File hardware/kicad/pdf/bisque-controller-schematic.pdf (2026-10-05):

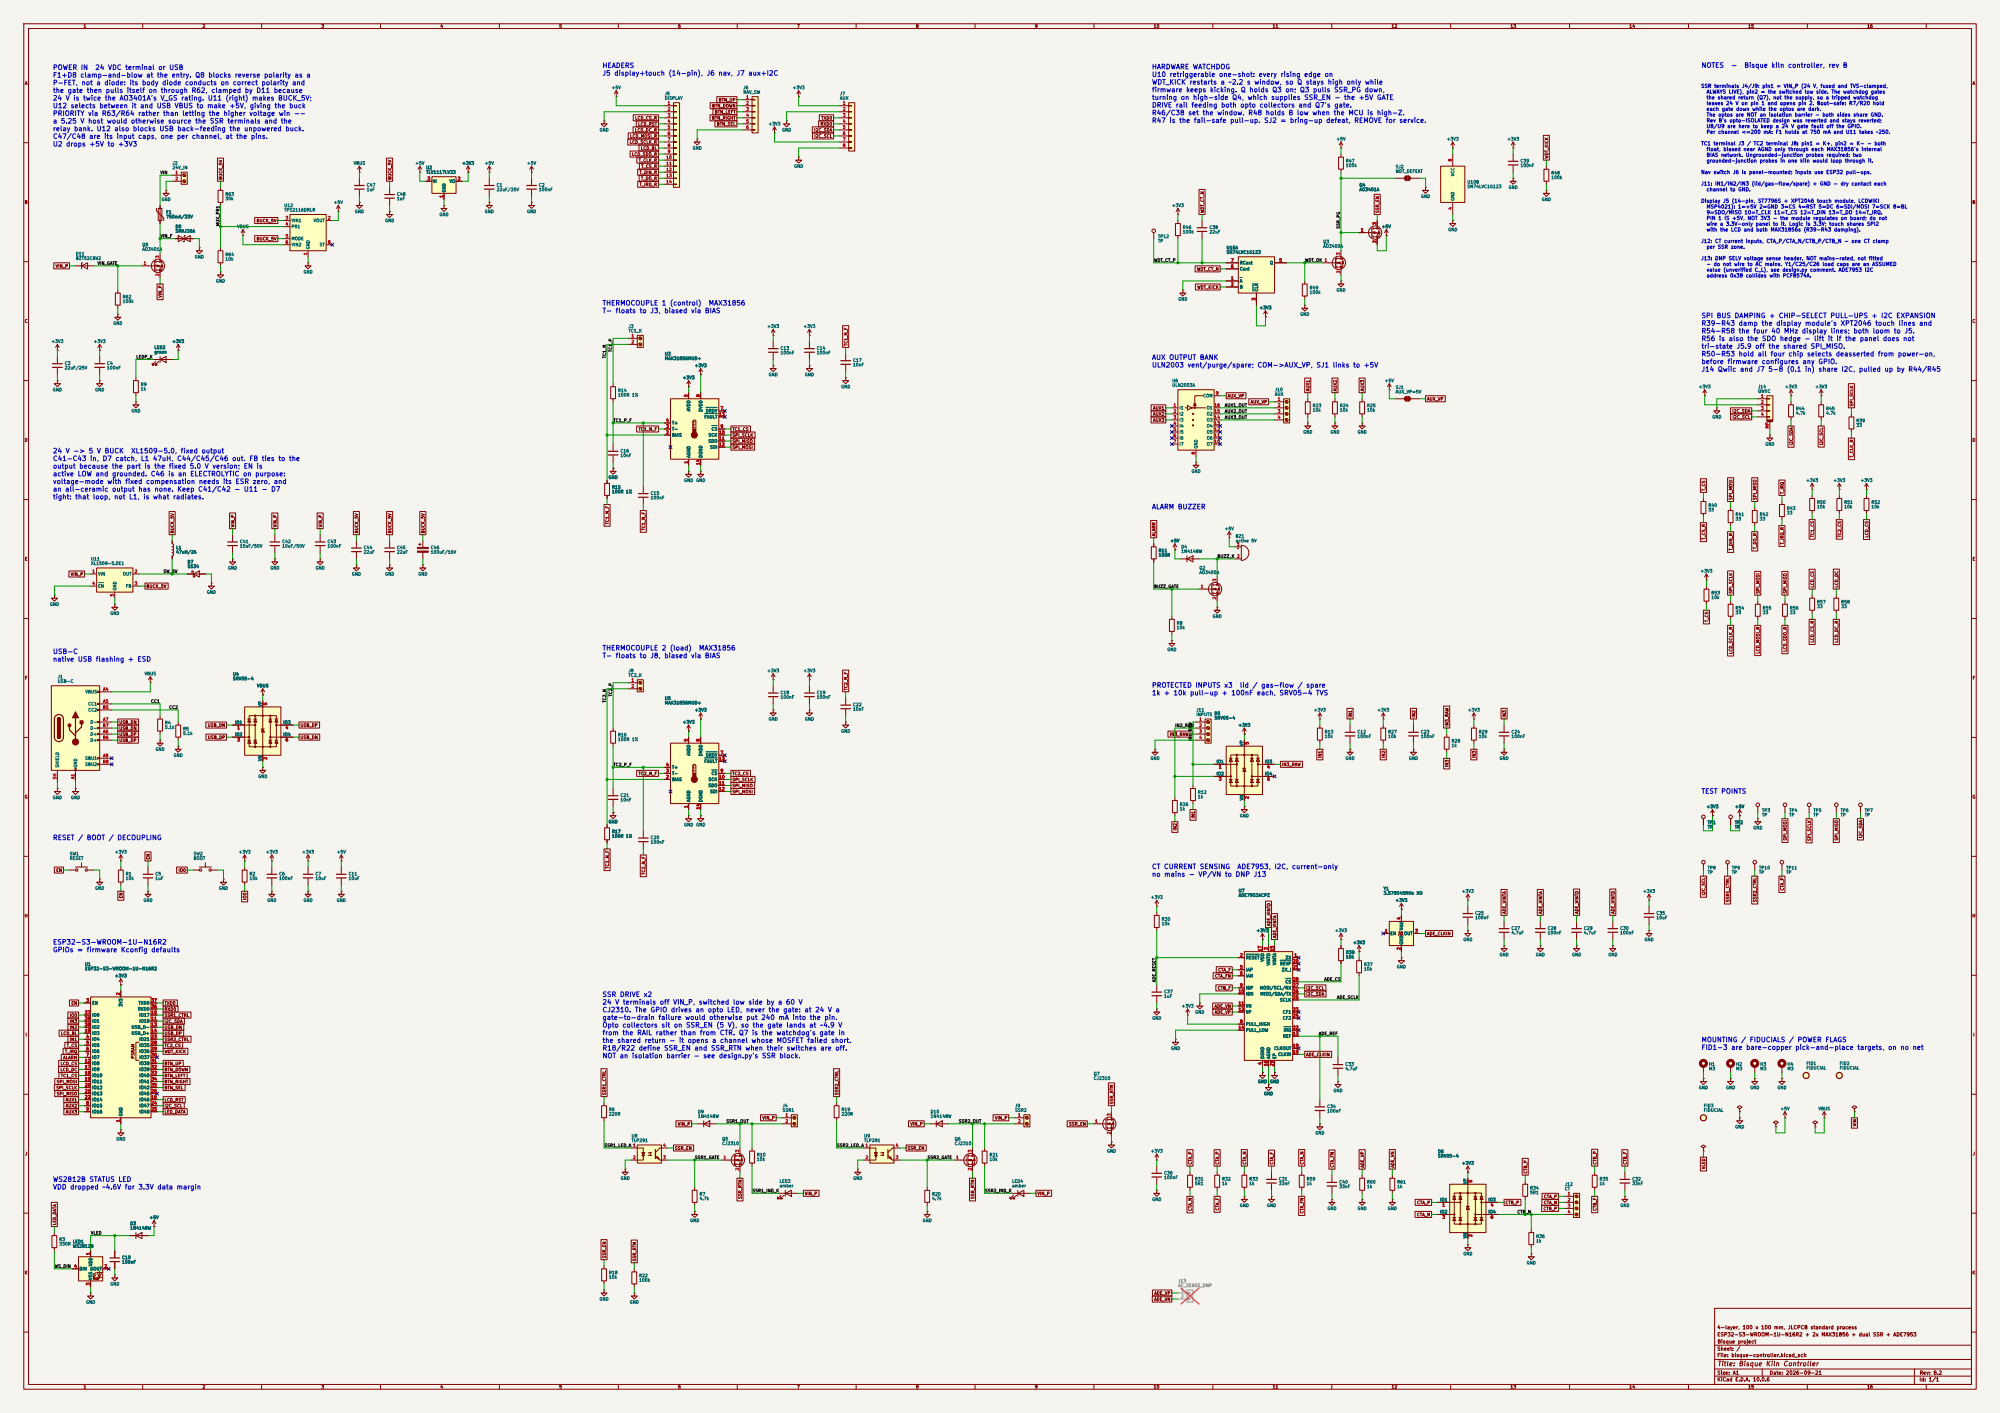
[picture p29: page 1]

F1+D8 clamp-and-blow at the entry. Q8 blocks reverse polarity as a
P-FET, not a diode: its body diode conducts on correct polarity and
the gate then pulls itself on through R62, clamped by D11 because
24 V is twice the AO3401A's V_GS rating. U11 (right) makes BUCK_5V;
U12 selects between it and USB VBUS to make +5V, giving the buck
PRIORITY via R63/R64 rather than letting the higher voltage win --
a 5.25 V host would otherwise source the SSR terminals and the
relay bank. U12 also blocks USB back-feeding the unpowered buck.
C47/C48 are its input caps, one per channel, at the pins.
U2 drops +5V to +3V3

HEADERS
J5 display+touch (14-pin), J6 nav, J7 aux+I2C

HARDWARE WATCHDOG
U10 retriggerable one-shot: every rising edge on
WDT_KICK restarts a ~2.2 s window, so Q stays high only while
firmware keeps kicking. Q holds Q3 on; Q3 pulls SSR_PG down,
turning on high-side Q4, which supplies SSR_EN - the +5V GATE
DRIVE rail feeding both opto collectors and Q7's gate.
R46/C38 set the window. R48 holds B low when the MCU is high-Z.
R47 is the fail-safe pull-up. SJ2 = bring-up defeat, REMOVE for service.

SSR terminals J4/J9: pin1 = VIN_P (24 V, fused and TVS-clamped,
ALWAYS LIVE), pin2 = the switched low side. The watchdog gates
the shared return (Q7), not the supply, so a tripped watchdog
leaves 24 V on pin 1 and opens pin 2. Boot-safe: R7/R20 hold
each gate down while the optos are dark.
The optos are NOT an isolation barrier - both sides share GND.
Rev B's opto-ISOLATED design was reverted and stays reverted;
U8/U9 are here to keep a 24 V gate fault off the GPIO.
Per channel <=200 mA: F1 holds at 750 mA and U11 takes ~250.

TC1 terminal J3 / TC2 terminal J8: pin1 = K+, pin2 = K- - both
float, biased near AGND only through each MAX31856's internal
BIAS network. Ungrounded-junction probes required: two
grounded-junction probes in one kiln would loop through it.

Nav switch J6 is panel-mounted; inputs use ESP32 pull-ups.

J11: IN1/IN2/IN3 (lid/gas-flow/spare) + GND - dry contact each
channel to GND.

Display J5 (14-pin, ST7796S + XPT2046 touch module, LCDWIKI
MSP4021): 1=+5V 2=GND 3=CS 4=RST 5=DC 6=SDI/MOSI 7=SCK 8=BL
9=SDO/MISO 10=T_CLK 11=T_CS 12=T_DIN 13=T_DO 14=T_IRQ.
PIN 1 IS +5V, NOT 3V3 - the module regulates on board; do not
wire a 3.3V-only panel to it. Logic is 3.3V; touch shares SPI2
with the LCD and both MAX31856s (R39-R43 damping).

J12: CT current inputs, CTA_P/CTA_N/CTB_P/CTB_N - one CT clamp
per SSR zone. J13: DNP SELV voltage sense header. NOT mains-rated, not fitted - do not wire to AC mains. Y1/C25/C26 load caps are an ASSUMED

value (unverified C_L), see design.py comment. ADE7953 I2C
address 0x38 collides with PCF8574A.

THERMOCOUPLE 1 (control) MAX31856
T- floats to J3, biased via BIAS

SPI BUS DAMPING + CHIP-SELECT PULL-UPS + I2C EXPANSION
R39-R43 damp the display module's XPT2046 touch lines and
R54-R58 the four 40 MHz display lines; both loom to J5.
R56 is also the SDO hedge - lift it if the panel does not
tri-state J5.9 off the shared SPI_MISO.
R50-R53 hold all four chip selects deasserted from power-on,
before firmware configures any GPIO.
J14 Qwiic and J7 5-8 (0.1 in) share I2C, pulled up by R44/R45

AUX OUTPUT BANK
ULN2003 vent/purge/spare; COM->AUX_VP, SJ1 links to +5V

24 V -> 5 V BUCK XL1509-5.0, fixed output
C41-C43 in, D7 catch, L1 47uH, C44/C45/C46 out. FB ties to the
output because the part is the fixed 5.0 V version; EN is
active LOW and grounded. C46 is an ELECTROLYTIC on purpose:
voltage-mode with fixed compensation needs its ESR zero, and
an all-ceramic output has none. Keep C41/C42 - U11 - D7
tight: that loop, not L1, is what radiates.

THERMOCOUPLE 2 (load) MAX31856
T- floats to J8, biased via BIAS

USB-C
native USB flashing + ESD

PROTECTED INPUTS x3 lid / gas-flow / spare
1k + 10k pull-up + 100nF each, SRV05-4 TVS

CT CURRENT SENSING ADE7953, I2C, current-only
no mains - VP/VN to DNP J13
ADE7953ACPZ
28 EP 29 +3V3 GND

SSR DRIVE x2
24 V terminals off VIN_P, switched low side by a 60 V
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

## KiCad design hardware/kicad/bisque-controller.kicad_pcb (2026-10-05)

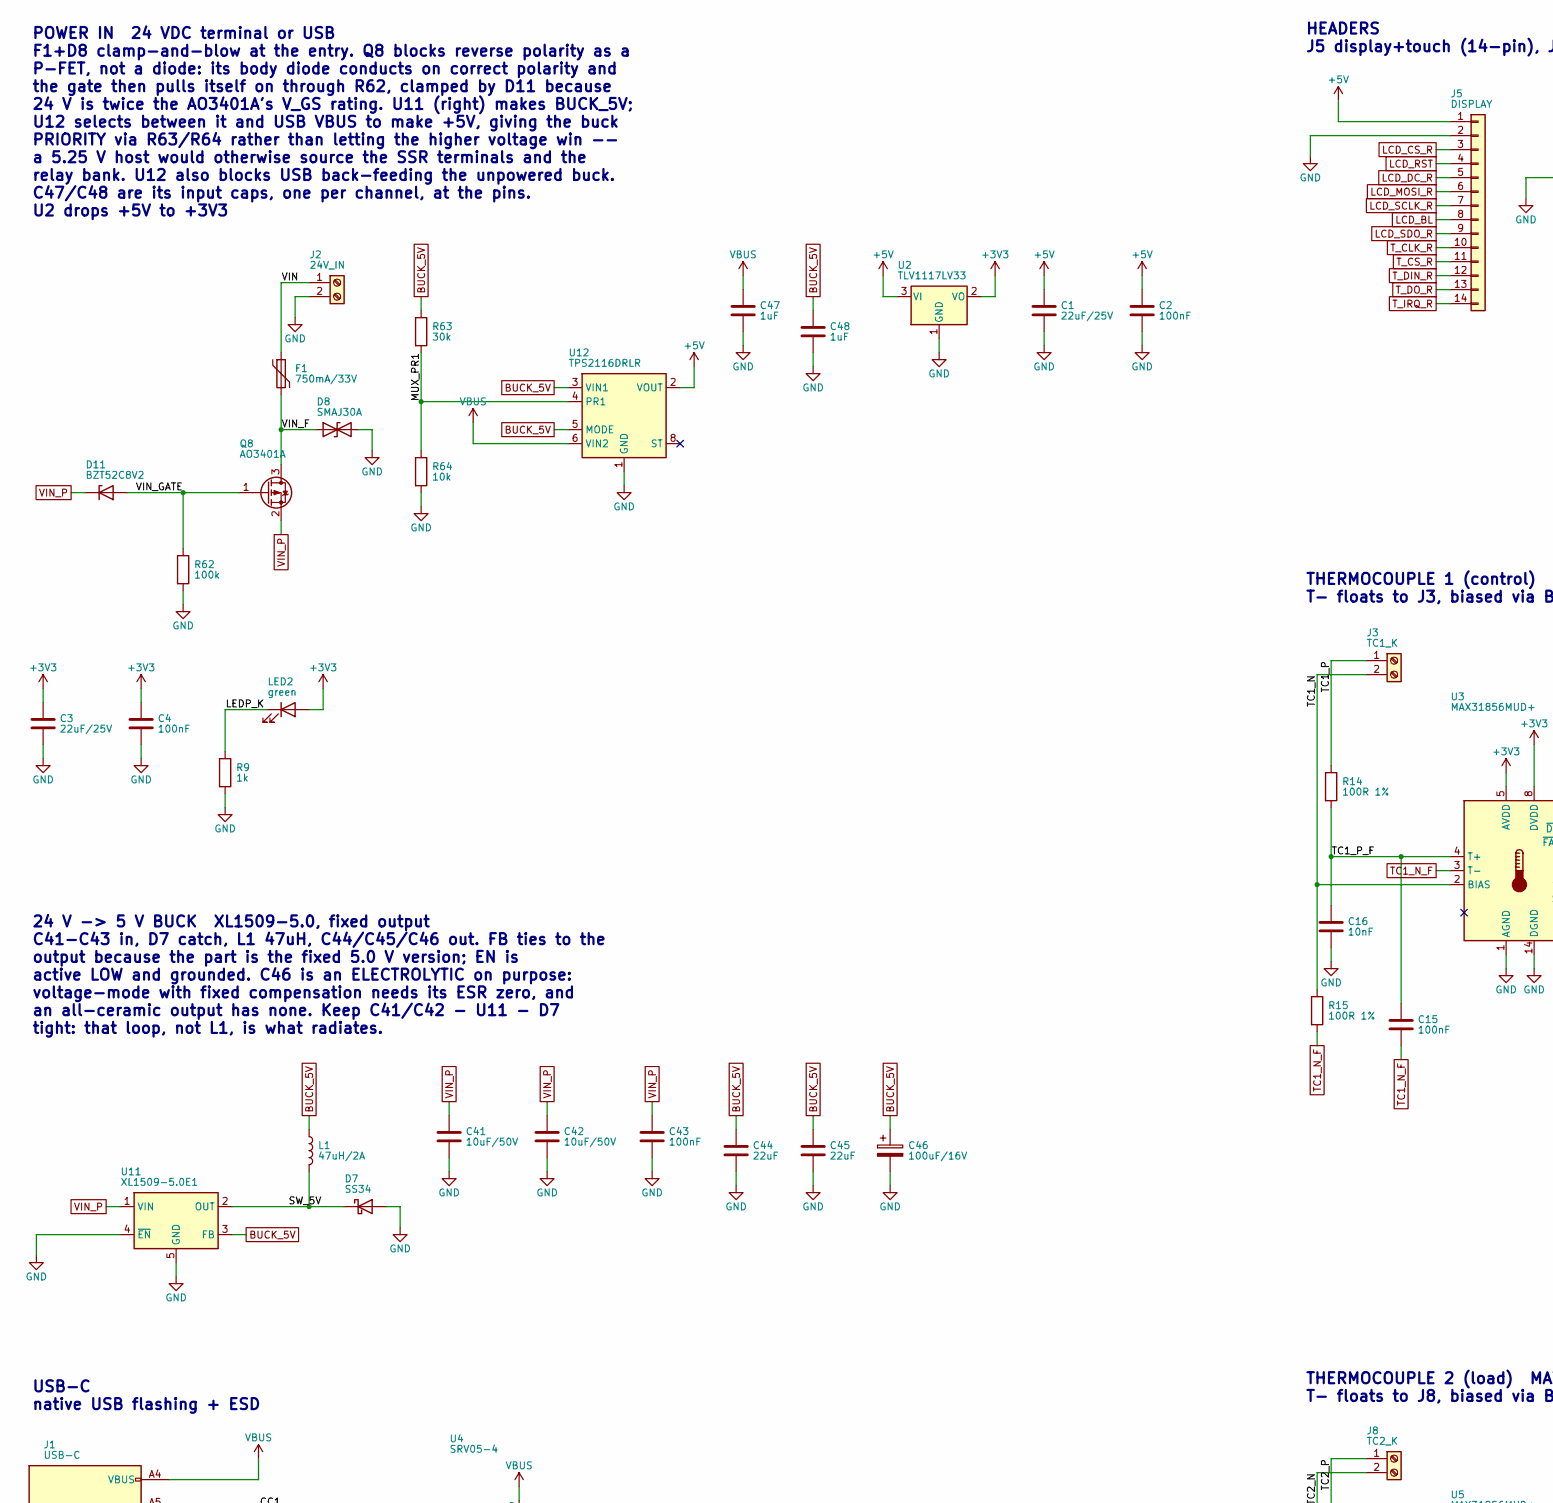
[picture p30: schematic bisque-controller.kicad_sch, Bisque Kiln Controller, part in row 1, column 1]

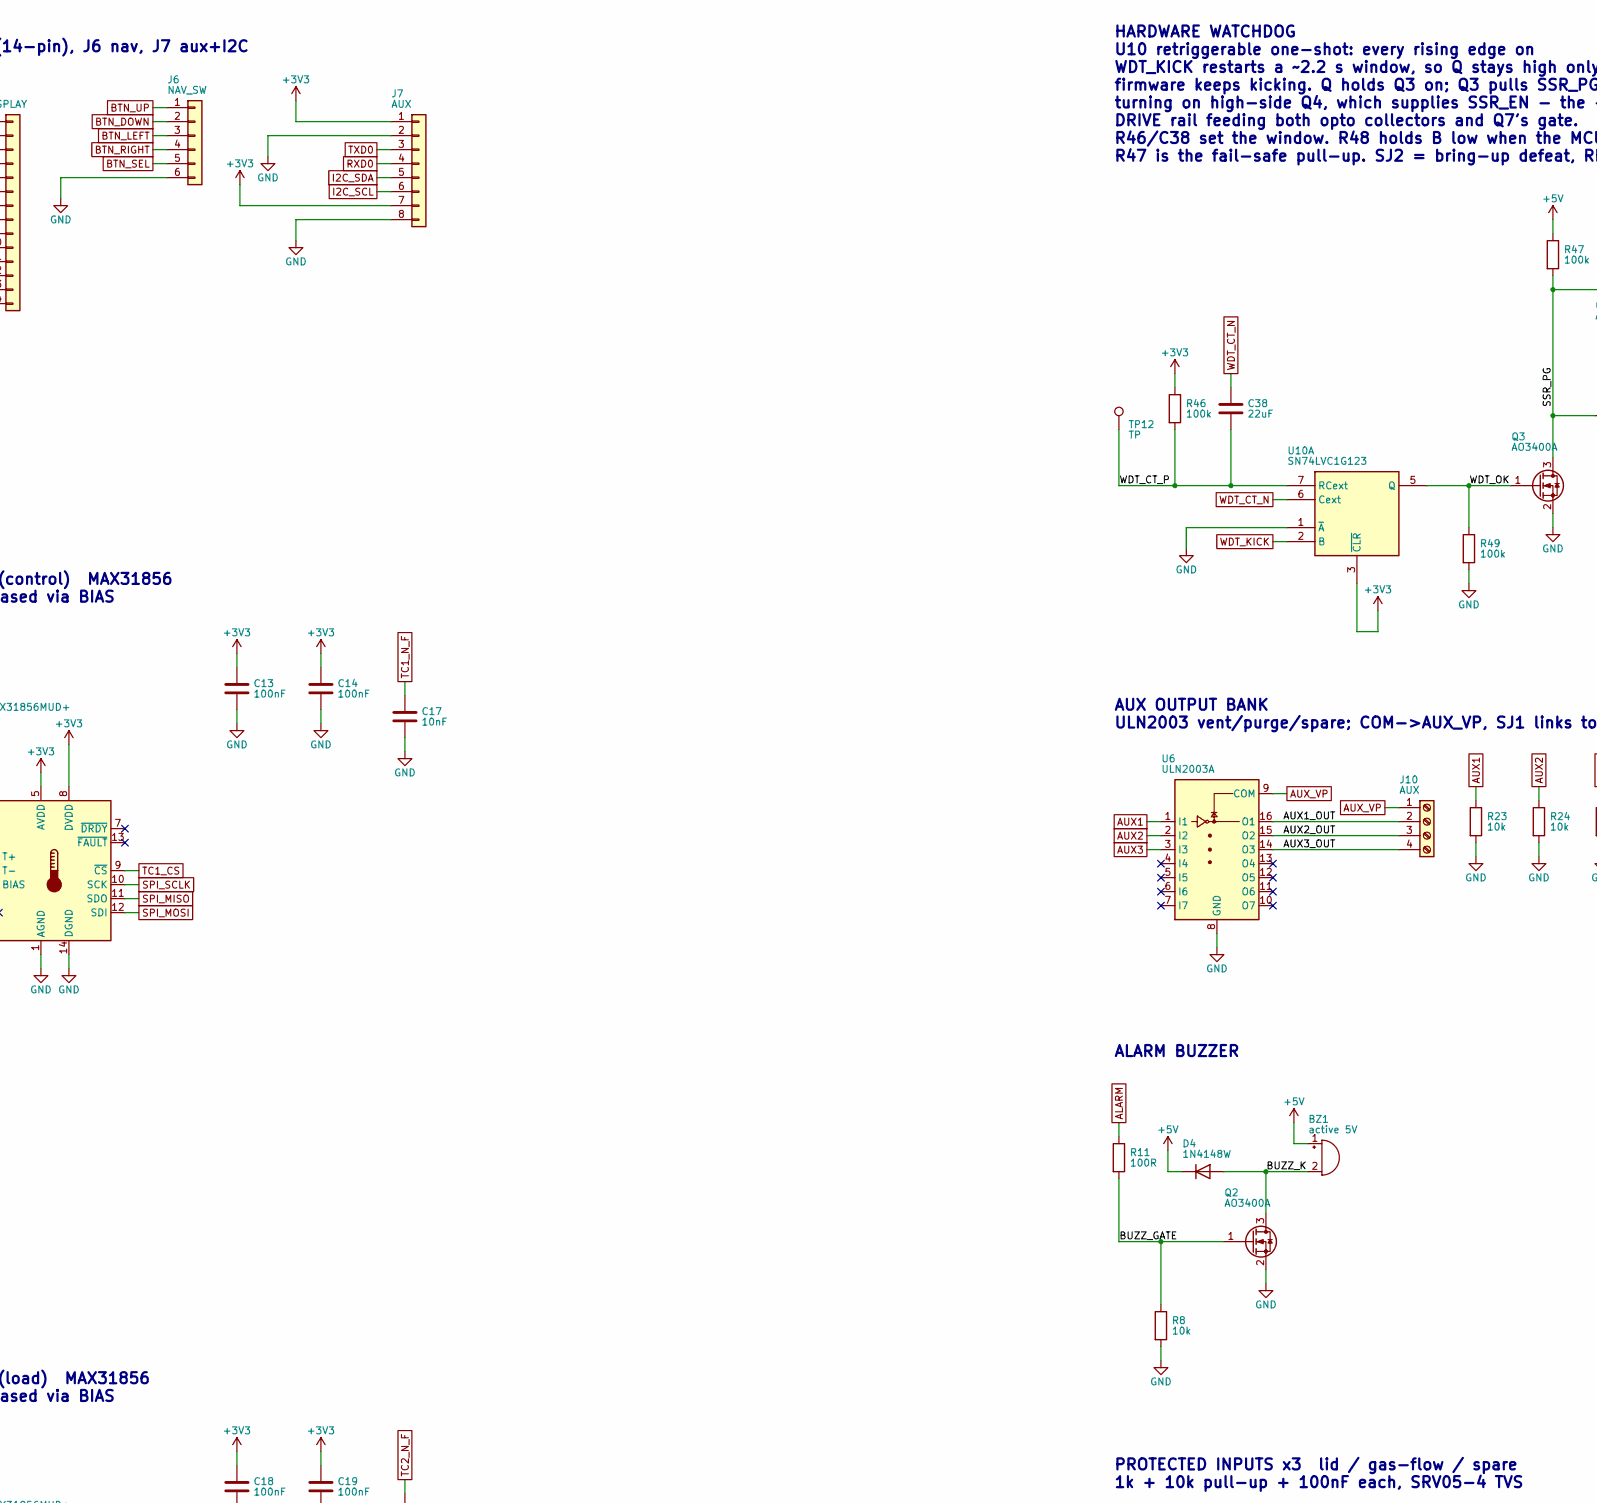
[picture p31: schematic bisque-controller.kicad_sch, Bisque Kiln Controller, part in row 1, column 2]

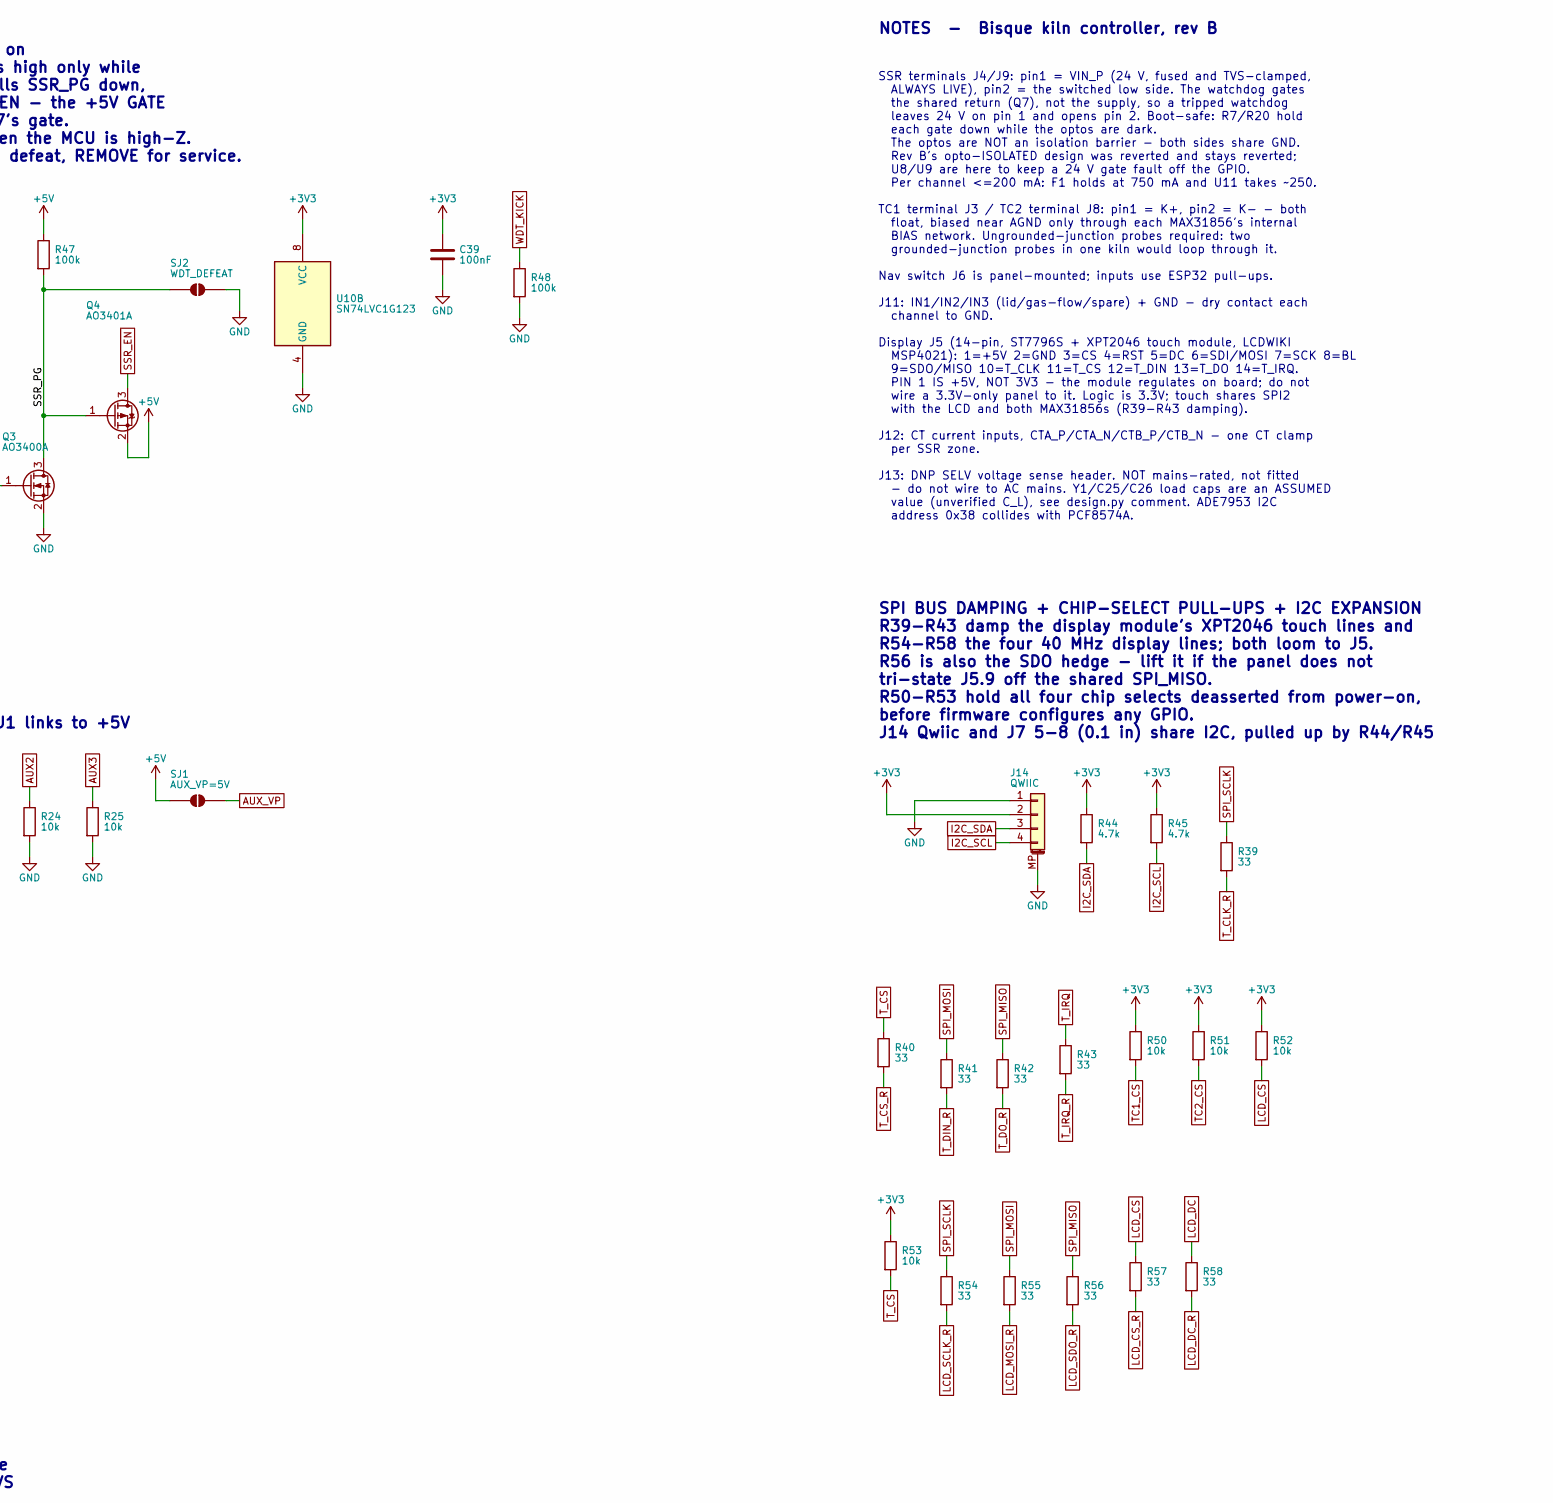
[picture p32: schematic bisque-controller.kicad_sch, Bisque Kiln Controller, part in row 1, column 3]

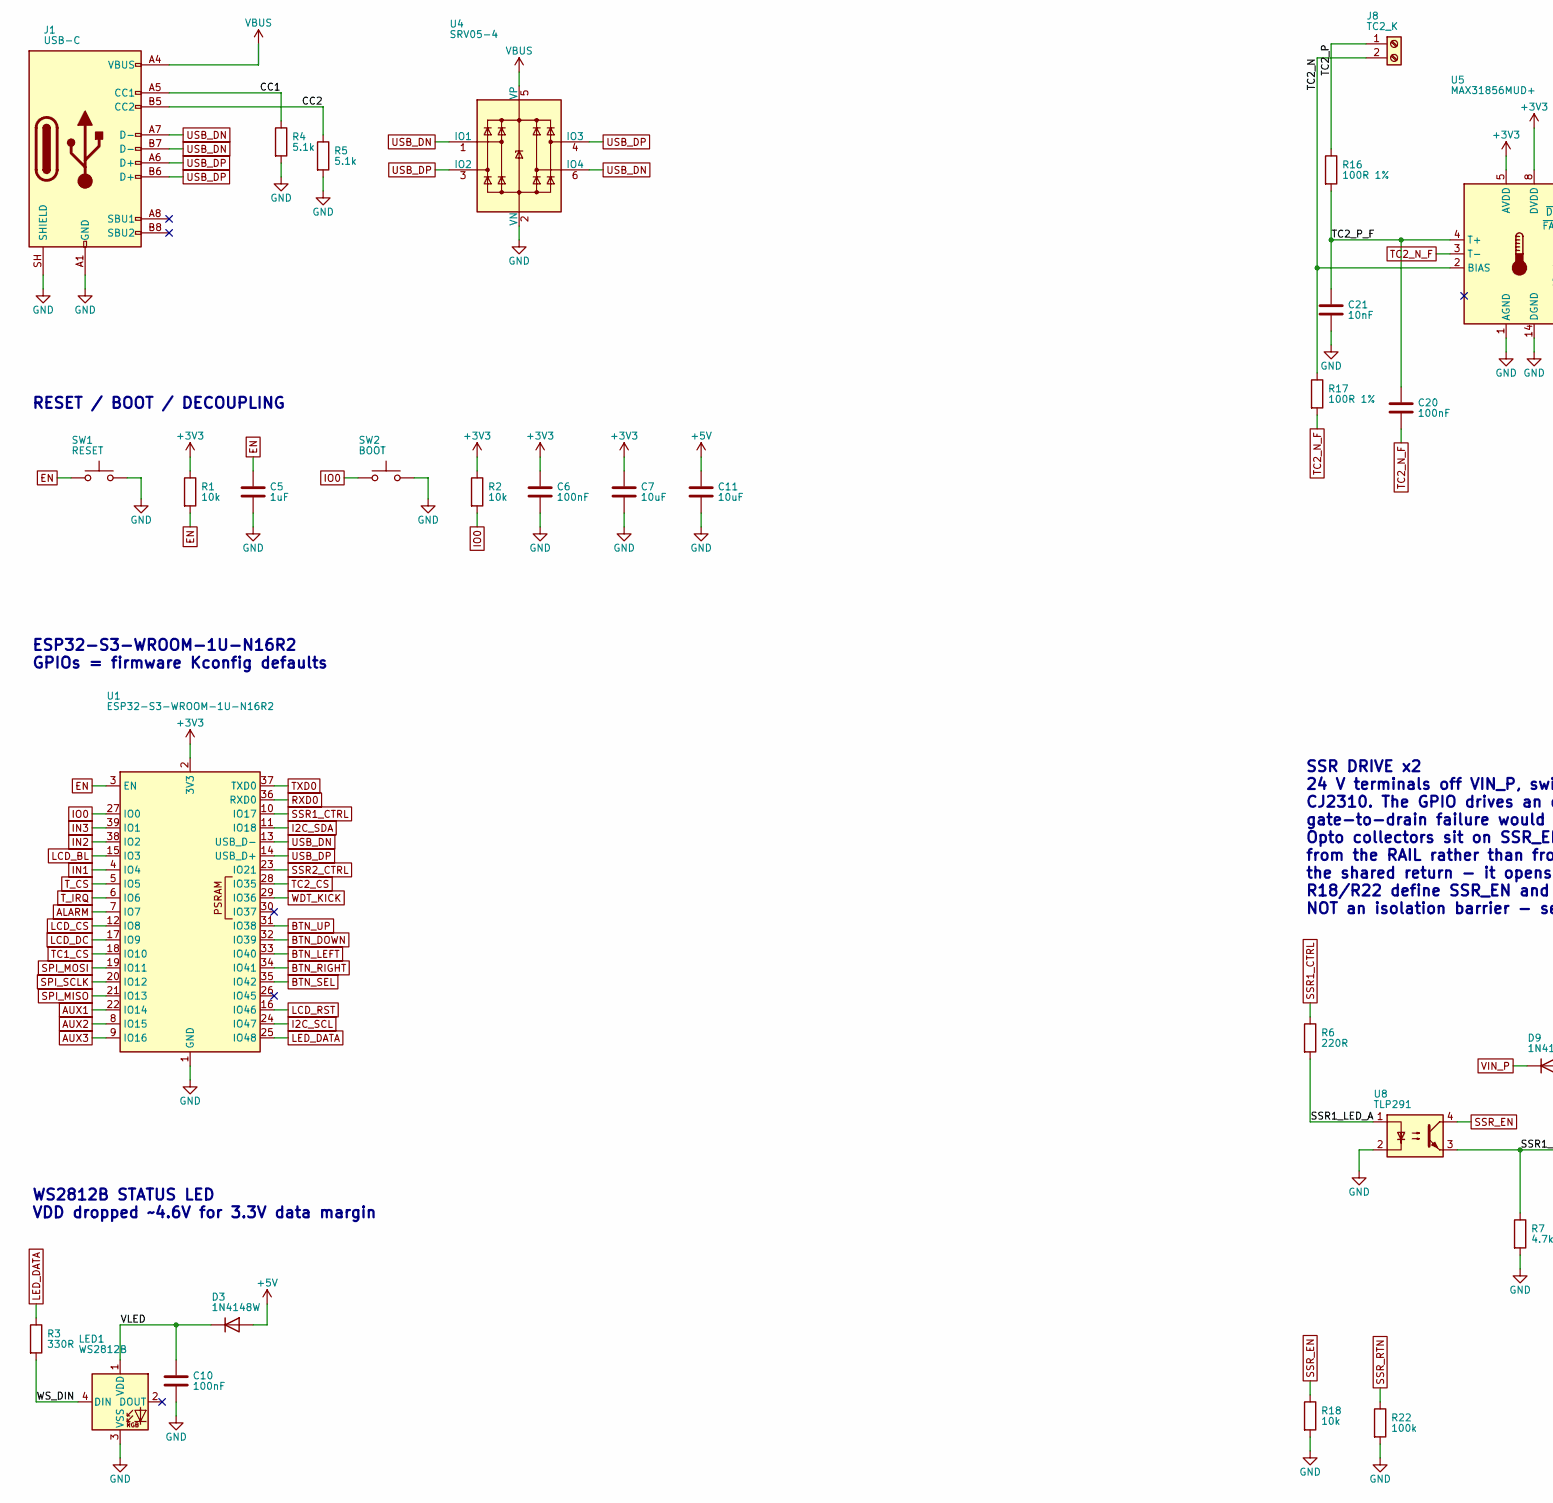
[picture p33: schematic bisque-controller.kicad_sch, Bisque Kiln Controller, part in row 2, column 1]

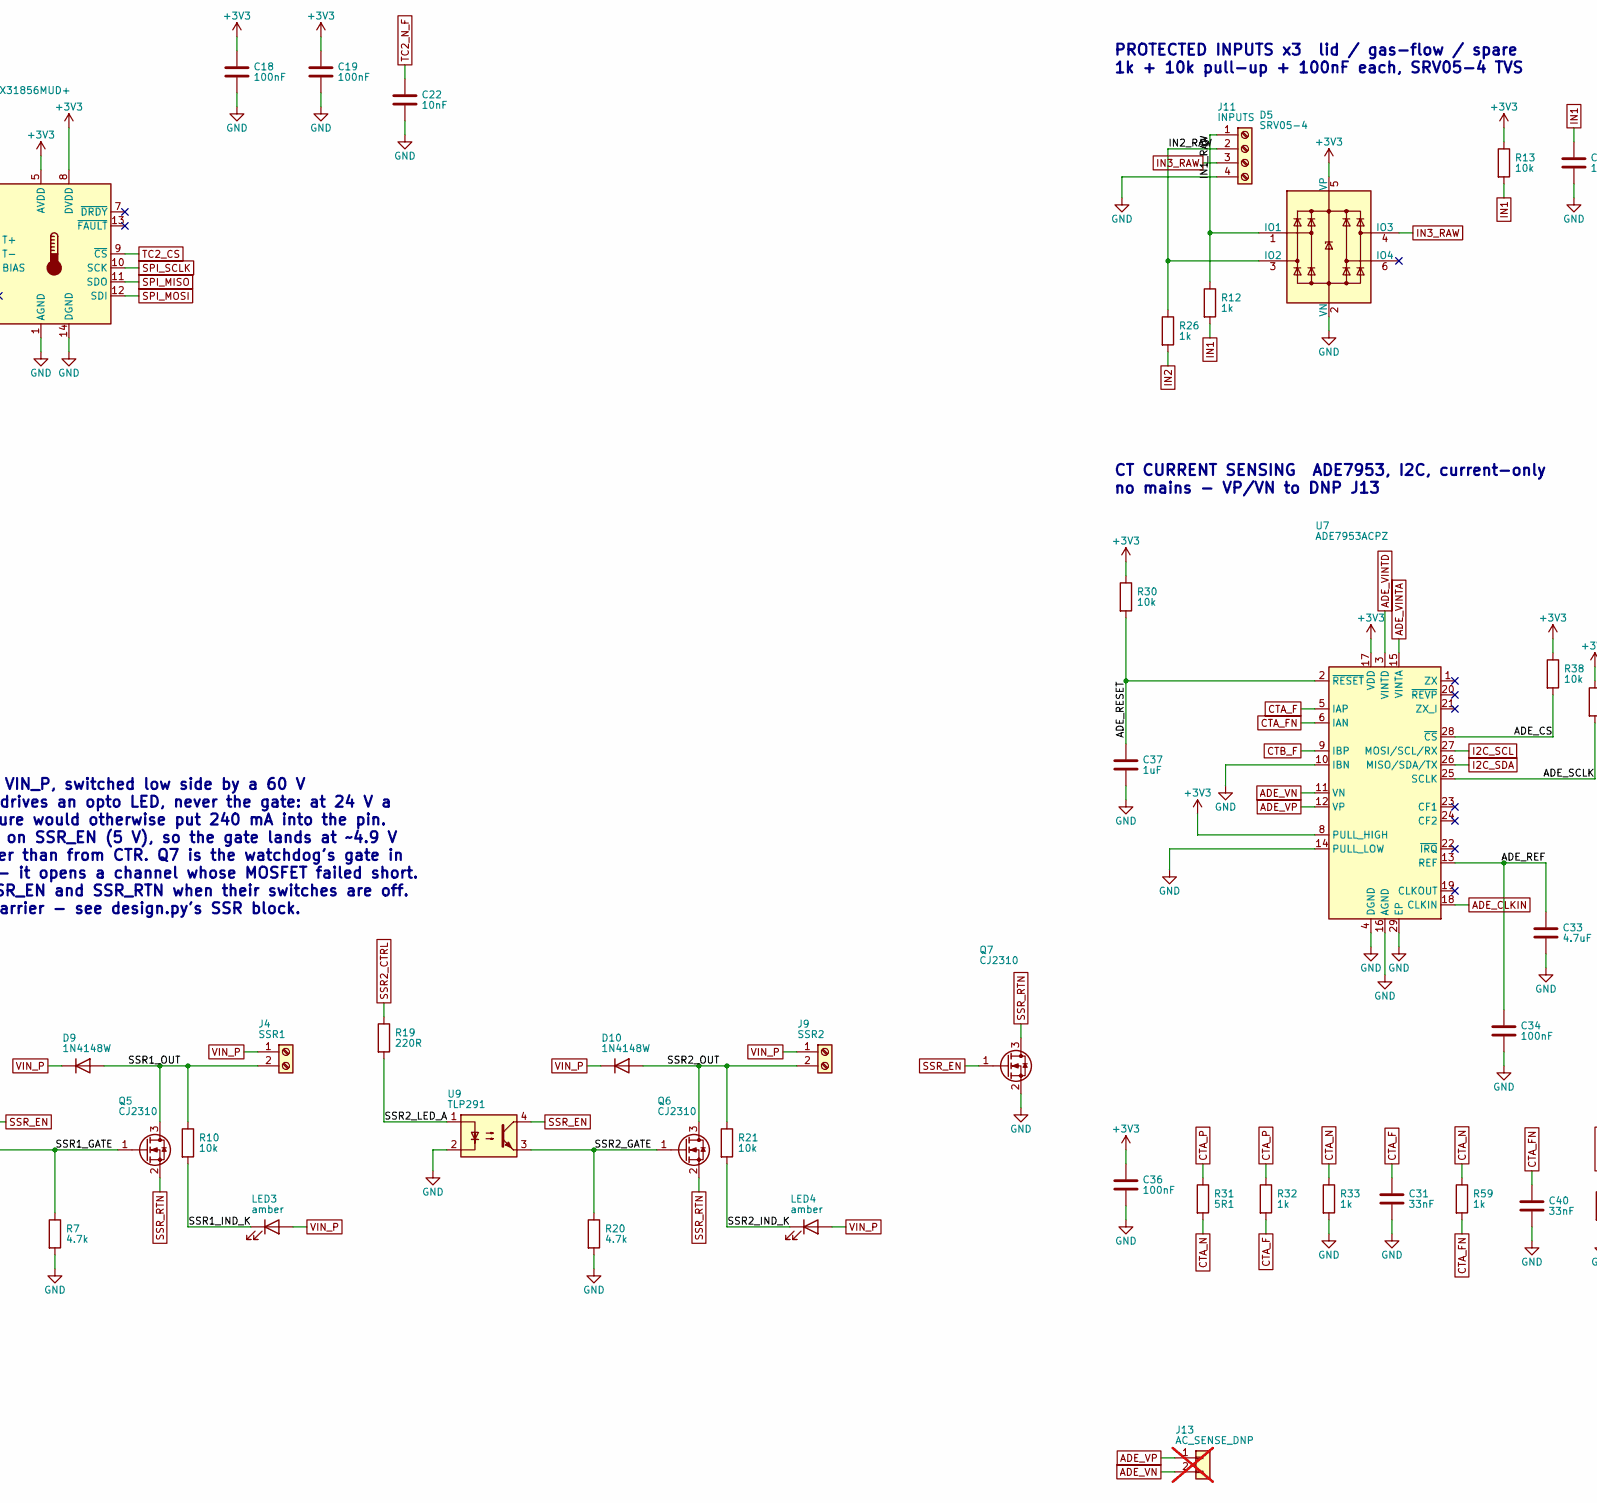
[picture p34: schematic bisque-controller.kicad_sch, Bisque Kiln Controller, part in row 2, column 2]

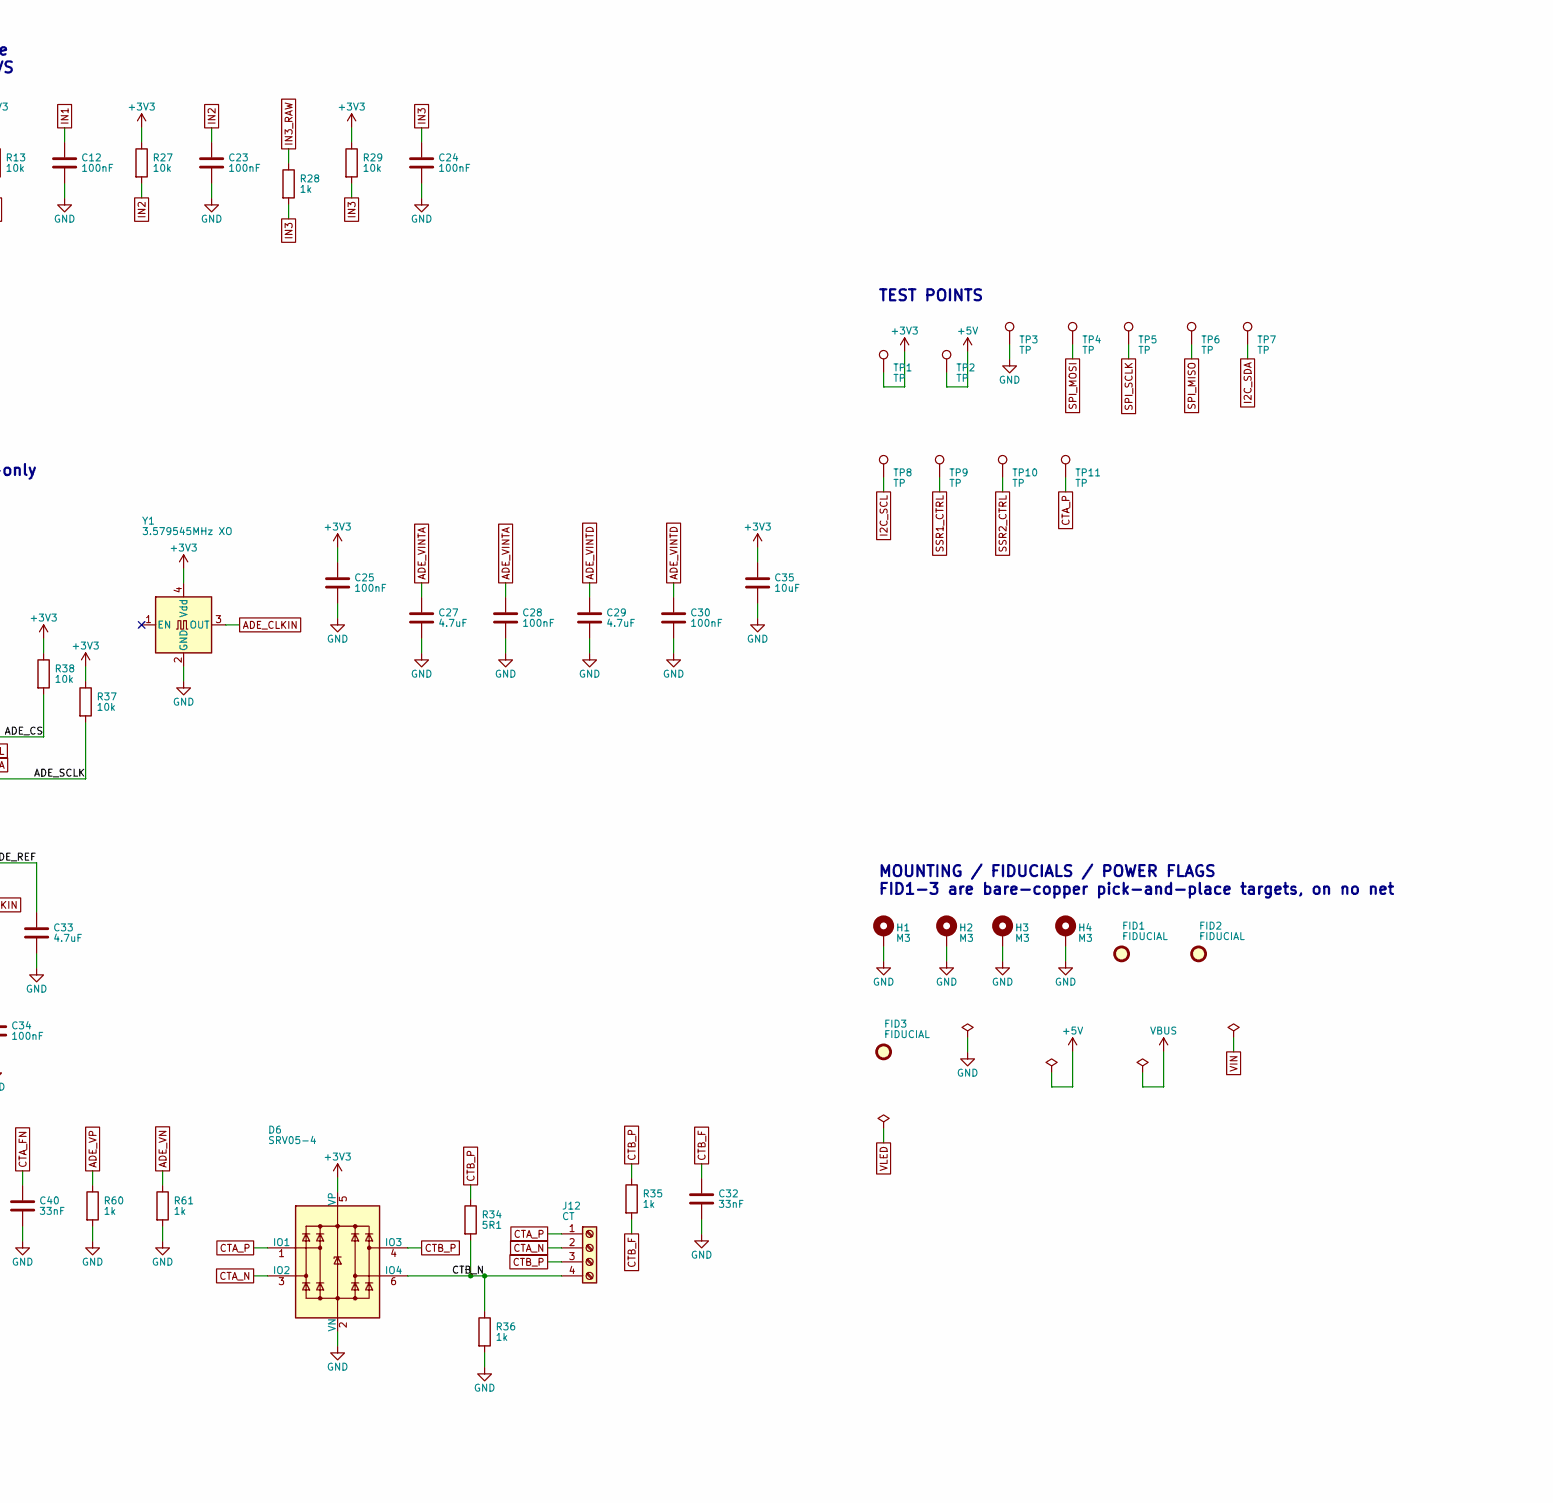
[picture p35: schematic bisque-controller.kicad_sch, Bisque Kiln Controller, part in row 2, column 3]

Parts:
BZ1: active 5V; Buzzer_12x9.5RM7.6; MPN C96093; LCSC C96093
C1, C3: 22uF/25V; C_1206_3216Metric; MPN C12891; LCSC C12891
C2, C4, C6, C10, C12, C13, C14, C15, C18, C19, C20, C23, C24, C25, C28, C30, C34, C36, C39, C43: 100nF; C_0805_2012Metric; MPN C49678; LCSC C49678
C5, C37: 1uF; C_0805_2012Metric; MPN C28323; LCSC C28323
C7, C11, C35: 10uF; C_0805_2012Metric; MPN C15850; LCSC C15850
C16, C17, C21, C22: 10nF; C_0805_2012Metric; MPN C1710; LCSC C1710
C27, C29, C33: 4.7uF; C_0805_2012Metric; MPN C1779; LCSC C1779
C31, C32, C40: 33nF; C_0805_2012Metric; MPN C1739; LCSC C1739
C38, C44, C45: 22uF; C_1206_3216Metric; MPN C12891; LCSC C12891
C41, C42: 10uF/50V; C_1206_3216Metric; MPN C13585; LCSC C13585
C46: 100uF/16V; CP_Elec_5x5.4; MPN C2977550; LCSC C2977550
C47, C48: 1uF; C_0402_1005Metric; MPN C52923; LCSC C52923
D3, D4, D9, D10: 1N4148W; D_SOD-123; MPN C81598; LCSC C81598
D5, D6: SRV05-4; SOT-23-6; MPN C7420376; LCSC C7420376
D7: SS34; D_SMA; MPN C8678; LCSC C8678
D8: SMAJ30A; D_SMA; MPN C19077547; LCSC C19077547
D11: BZT52C8V2; D_SOD-323; MPN C22375294; LCSC C22375294
F1: 750mA/33V; Fuse_1812_4532Metric; MPN C369169; LCSC C369169
FID1, FID2, FID3: FIDUCIAL; Fiducial_1mm_Mask2mm
H1, H2, H3, H4: M3; MountingHole_3.2mm_M3_Pad_Via
J1: USB-C; USB_C_Receptacle_HRO_TYPE-C-31-M-12; MPN C165948; LCSC C165948
J2: 24V_IN; TerminalBlock_Phoenix_MKDS-1,5-2-5.08_1x02_P5.08mm_Horizont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; MPN C8465; LCSC C8465
J3: TC1_K; TerminalBlock_Phoenix_MKDS-1,5-2-5.08_1x02_P5.08mm_Horizont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; MPN C8465; LCSC C8465
J4: SSR1; TerminalBlock_Phoenix_MKDS-1,5-2-5.08_1x02_P5.08mm_Horizont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; MPN C8465; LCSC C8465
J5: DISPLAY; Molex_KK-254_AE-6410-14A_1x14_P2.54mm_Vertical; MPN C17701004; LCSC C17701004
J6: NAV_SW; Molex_KK-254_AE-6410-06A_1x06_P2.54mm_Vertical; MPN C239381; LCSC C239381
J7: AUX; Molex_KK-254_AE-6410-08A_1x08_P2.54mm_Vertical; MPN C240822; LCSC C240822
J8: TC2_K; TerminalBlock_Phoenix_MKDS-1,5-2-5.08_1x02_P5.08mm_Horizont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; MPN C8465; LCSC C8465
J9: SSR2; TerminalBlock_Phoenix_MKDS-1,5-2-5.08_1x02_P5.08mm_Horizont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; MPN C8465; LCSC C8465
J10: AUX; TerminalBlock_Phoenix_MKDS-1,5-4-5.08_1x04_P5.08mm_Horizont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; MPN C42377749; LCSC C42377749
J11: INPUTS; TerminalBlock_Phoenix_MKDS-1,5-4-5.08_1x04_P5.08mm_Horizont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; MPN C42377749; LCSC C42377749
J12: CT; TerminalBlock_Phoenix_MKDS-1,5-4-5.08_1x04_P5.08mm_Horizont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; MPN C42377749; LCSC C42377749
J13: AC_SENSE_DNP; PinHeader_1x02_P2.54mm_Vertical; not fitted
J14: QWIIC; JST_SH_SM04B-SRSS-TB_1x04-1MP_P1.00mm_Horizontal; MPN C160404; LCSC C160404
L1: 47uH/2A; L_Changjiang_FXL0650; MPN C475527; LCSC C475527
LED1: WS2812B; LED_WS2812B_PLCC4_5.0x5.0mm_P3.2mm; MPN C2761795; LCSC C2761795
LED2: green; LED_0805_2012Metric; MPN C2297; LCSC C2297
LED3, LED4: amber; LED_0805_2012Metric; MPN C2296; LCSC C2296
Q2, Q3: AO3400A; SOT-23; MPN C20917; LCSC C20917
Q4, Q8: AO3401A; SOT-23; MPN C15127; LCSC C15127
Q5, Q6, Q7: CJ2310; SOT-23; MPN C75882; LCSC C75882
R1, R2, R8, R10, R13, R18, R21, R23, R24, R25, R27, R29, R30, R37, R38, R50, R51, R52, R53, R64: 10k; R_0805_2012Metric; MPN C17414; LCSC C17414
R3: 330R; R_0805_2012Metric; MPN C17630; LCSC C17630
R4, R5: 5.1k; R_0805_2012Metric; MPN C27834; LCSC C27834
R6, R19: 220R; R_0805_2012Metric; MPN C17557; LCSC C17557
R7, R20, R44, R45: 4.7k; R_0805_2012Metric; MPN C17673; LCSC C17673
R9, R12, R26, R28, R32, R33, R35, R36, R59, R60, R61: 1k; R_0805_2012Metric; MPN C17513; LCSC C17513
R11: 100R; R_0805_2012Metric; MPN C17408; LCSC C17408
R14, R15, R16, R17: 100R 1%; R_0805_2012Metric; MPN C17408; LCSC C17408
R22, R46, R47, R48, R49, R62: 100k; R_0805_2012Metric; MPN C149504; LCSC C149504
R31, R34: 5R1; R_0805_2012Metric; MPN C17724; LCSC C17724
R39, R40, R41, R42, R43, R54, R55, R56, R57, R58: 33; R_0805_2012Metric; MPN C17634; LCSC C17634
R63: 30k; R_0805_2012Metric; MPN C17621; LCSC C17621
SJ1: AUX_VP=5V; SolderJumper-2_P1.3mm_Open_RoundedPad1.0x1.5mm
SJ2: WDT_DEFEAT; SolderJumper-2_P1.3mm_Open_RoundedPad1.0x1.5mm
SW1: RESET; SW_Push_1P1T_XKB_TS-1187A; MPN C318884; LCSC C318884
SW2: BOOT; SW_Push_1P1T_XKB_TS-1187A; MPN C318884; LCSC C318884
TP1, TP2, TP3, TP4, TP5, TP6, TP7, TP8, TP9, TP10, TP11, TP12: TP; TestPoint_Pad_D1.0mm
U1: ESP32-S3-WROOM-1U-N16R2; ESP32-S3-WROOM-1U; MPN C3013945; LCSC C3013945
U2: TLV1117LV33; SOT-223-3_TabPin2; MPN C48937499; LCSC C48937499
U3, U5: MAX31856MUD+; TSSOP-14_4.4x5mm_P0.65mm; MPN C2653162; LCSC C2653162
U4: SRV05-4; SOT-23-6; MPN C7420376; LCSC C7420376
U6: ULN2003A; SOIC-16_3.9x9.9mm_P1.27mm; MPN C7512; LCSC C7512
U7: ADE7953ACPZ; QFN-28-1EP_5x5mm_P0.5mm_EP3.1x3.1mm; MPN C515890; LCSC C515890
U8, U9: TLP291; SOP-4_4.4x2.6mm_P1.27mm; MPN C55144; LCSC C55144
U10: SN74LVC1G123; SSOP-8_2.95x2.8mm_P0.65mm; MPN C123302; LCSC C123302
U11: XL1509-5.0E1; SOIC-8_3.9x4.9mm_P1.27mm; MPN C61063; LCSC C61063
U12: TPS2116DRLR; SOT-583-8; MPN C3235557; LCSC C3235557
Y1: 3.579545MHz XO; Oscillator_SMD_Abracon_ASE-4Pin_3.2x2.5mm; MPN C2838127; LCSC C2838127

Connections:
+3V3: C3.1, C4.1, C6.1, C7.1, C13.1, C14.1, C18.1, C19.1, C25.1, C35.1, C36.1, C39.1, D5.5 (VP), D6.5 (VP), J7.1, J7.7, J14.2, LED2.2 (A), R1.1, R2.1, R13.1, R27.1, R29.1, R30.1, R37.1, R38.1, R44.1, R45.1, R46.1, R50.1, R51.1, R52.1, R53.1, TP1.1, U1.2 (3V3), U2.2 (VO), U3.5 (AVDD), U3.8 (DVDD), U5.5 (AVDD), U5.8 (DVDD), U7.7 (PULL_HIGH), U7.8 (PULL_HIGH), U7.17 (VDD), U10.3 (~CLR), U10.8 (VCC), Y1.4 (Vdd)
+5V: BZ1.1 (+), C1.1, C2.1, C11.1, D3.2 (A), D4.1 (K), J5.1, Q4.2 (S), R47.1, SJ1.1 (A), TP2.1, U2.3 (VI), U12.2 (VOUT), U12.7 (VOUT)
ADE_CLKIN: U7.18 (CLKIN), Y1.3 (OUT)
ADE_CS: R38.2, U7.28 (~CS)
ADE_REF: C33.1, C34.1, U7.13 (REF)
ADE_RESET: C37.1, R30.2, U7.2 (~RESET)
ADE_SCLK: R37.2, U7.25 (SCLK)
ADE_VINTA: C27.1, C28.1, U7.15 (VINTA)
ADE_VINTD: C29.1, C30.1, U7.3 (VINTD)
ADE_VN: J13.2, R61.1, U7.11 (VN)
ADE_VP: J13.1, R60.1, U7.12 (VP)
ALARM: R11.1, U1.7 (IO7)
AUX1: R23.1, U1.22 (IO14), U6.1 (I1)
AUX1_OUT: J10.2, U6.16 (O1)
AUX2: R24.1, U1.8 (IO15), U6.2 (I2)
AUX2_OUT: J10.3, U6.15 (O2)
AUX3: R25.1, U1.9 (IO16), U6.3 (I3)
AUX3_OUT: J10.4, U6.14 (O3)
AUX_VP: J10.1, SJ1.2 (B), U6.9 (COM)
BTN_DOWN: J6.2, U1.32 (IO39)
BTN_LEFT: J6.3, U1.33 (IO40)
BTN_RIGHT: J6.4, U1.34 (IO41)
BTN_SEL: J6.5, U1.35 (IO42)
BTN_UP: J6.1, U1.31 (IO38)
BUCK_5V: C44.1, C45.1, C46.1, C48.1, L1.1, R63.1, U11.3 (FB), U12.3 (VIN1), U12.5 (MODE)
BUZZ_GATE: Q2.1 (G), R8.1, R11.2
BUZZ_K: BZ1.2 (-), D4.2 (A), Q2.3 (D)
CC1: J1.A5 (CC1), R4.1
CC2: J1.B5 (CC2), R5.1
CTA_F: C31.1, R32.2, U7.5 (IAP)
CTA_FN: C40.1, R59.2, U7.6 (IAN)
CTA_N: D6.3 (IO2), J12.2, R31.2, R33.1, R59.1
CTA_P: D6.1 (IO1), J12.1, R31.1, R32.1, TP11.1
CTB_F: C32.1, R35.2, U7.9 (IBP)
CTB_N: D6.6 (IO4), J12.4, R34.2, R36.1
CTB_P: D6.4 (IO3), J12.3, R34.1, R35.1
EN: C5.1, R1.2, SW1.1, U1.3 (EN)
GND: C1.2, C2.2, C3.2, C4.2, C5.2, C6.2, C7.2, C10.2, C11.2, C12.2, C13.2, C14.2, C16.2, C17.2, C18.2, C19.2, C21.2, C22.2, C23.2, C24.2, C25.2, C27.2, C28.2, C29.2, C30.2, C31.2, C32.2, C33.2, C34.2, C35.2, C36.2, C37.2, C39.2, C40.2, C41.2, C42.2, C43.2, C44.2, C45.2, C46.2, C47.2, C48.2, D5.2 (VN), D6.2 (VN), D7.2 (A), D8.2 (A2), H1.1, H2.1, H3.1, H4.1, J1.A1 (GND), J1.A12 (GND), J1.B1 (GND), J1.B12 (GND), J1.SH (SHIELD), J2.2, J5.2, J6.6, J7.2, J7.8, J11.4, J14.1, J14.MP (MountPin), LED1.3 (VSS), Q2.2 (S), Q3.2 (S), Q7.2 (S), R4.2, R5.2, R7.2, R8.2, R9.2, R18.2, R20.2, R22.2, R23.2, R24.2, R25.2, R33.2, R36.2, R48.2, R49.2, R60.2, R61.2, R62.2, R64.2, SJ2.2 (B), SW1.2, SW2.2, TP3.1, U1.1 (GND), U1.40 (GND), U1.41 (GND), U2.1 (GND), U3.1 (AGND), U3.14 (DGND), U4.2 (VN), U5.1 (AGND), U5.14 (DGND), U6.8 (GND), U7.4 (DGND), U7.10 (IBN), U7.14 (PULL_LOW), U7.16 (AGND), U7.29 (EP), U8.2, U9.2, U10.1 (~A), U10.4 (GND), U11.4 (~EN), U11.5 (GND), U11.6 (GND), U11.7 (GND), U11.8 (GND), U12.1 (GND), Y1.2 (GND)
I2C_SCL: J7.6, J14.4, R45.2, TP8.1, U1.24 (IO47), U7.27 (MOSI/SCL/RX)
I2C_SDA: J7.5, J14.3, R44.2, TP7.1, U1.11 (IO18), U7.26 (MISO/SDA/TX)
IN1: C12.1, R12.2, R13.2, U1.4 (IO4)
IN1_RAW: D5.1 (IO1), J11.1, R12.1
IN2: C23.1, R26.2, R27.2, U1.38 (IO2)
IN2_RAW: D5.3 (IO2), J11.2, R26.1
IN3: C24.1, R28.2, R29.2, U1.39 (IO1)
IN3_RAW: D5.4 (IO3), J11.3, R28.1
IO0: R2.2, SW2.1, U1.27 (IO0)
LCD_BL: J5.8, U1.15 (IO3)
LCD_CS: R52.2, R57.1, U1.12 (IO8)
LCD_CS_R: J5.3, R57.2
LCD_DC: R58.1, U1.17 (IO9)
LCD_DC_R: J5.5, R58.2
LCD_MOSI_R: J5.6, R55.2
LCD_RST: J5.4, U1.16 (IO46)
LCD_SCLK_R: J5.7, R54.2
LCD_SDO_R: J5.9, R56.2
LEDP_K: LED2.1 (K), R9.1
LED_DATA: R3.1, U1.25 (IO48)
MUX_PR1: R63.2, R64.1, U12.4 (PR1)
RXD0: J7.4, U1.36 (RXD0)
SPI_MISO: R42.1, R56.1, TP6.1, U1.21 (IO13), U3.11 (SDO), U5.11 (SDO)
SPI_MOSI: R41.1, R55.1, TP4.1, U1.19 (IO11), U3.12 (SDI), U5.12 (SDI)
SPI_SCLK: R39.1, R54.1, TP5.1, U1.20 (IO12), U3.10 (SCK), U5.10 (SCK)
SSR1_CTRL: R6.1, TP9.1, U1.10 (IO17)
SSR1_GATE: Q5.1 (G), R7.1, U8.3
SSR1_IND_K: LED3.1 (K), R10.2
SSR1_LED_A: R6.2, U8.1
SSR1_OUT: D9.2 (A), J4.2, Q5.3 (D), R10.1
SSR2_CTRL: R19.1, TP10.1, U1.23 (IO21)
SSR2_GATE: Q6.1 (G), R20.1, U9.3
SSR2_IND_K: LED4.1 (K), R21.2
SSR2_LED_A: R19.2, U9.1
SSR2_OUT: D10.2 (A), J9.2, Q6.3 (D), R21.1
SSR_EN: Q4.3 (D), Q7.1 (G), R18.1, U8.4, U9.4
SSR_PG: Q3.3 (D), Q4.1 (G), R47.2, SJ2.1 (A)
SSR_RTN: Q5.2 (S), Q6.2 (S), Q7.3 (D), R22.1
SW_5V: D7.1 (K), L1.2, U11.2 (OUT)
TC1_CS: R50.2, U1.18 (IO10), U3.9 (~CS)
TC1_N: J3.2, R15.1, U3.2 (BIAS)
TC1_N_F: C15.2, C17.1, R15.2, U3.3 (T-)
TC1_P: J3.1, R14.1
TC1_P_F: C15.1, C16.1, R14.2, U3.4 (T+)
TC2_CS: R51.2, U1.28 (IO35), U5.9 (~CS)
TC2_N: J8.2, R17.1, U5.2 (BIAS)
TC2_N_F: C20.2, C22.1, R17.2, U5.3 (T-)
TC2_P: J8.1, R16.1
TC2_P_F: C20.1, C21.1, R16.2, U5.4 (T+)
TXD0: J7.3, U1.37 (TXD0)
T_CLK_R: J5.10, R39.2
T_CS: R40.1, R53.2, U1.5 (IO5)
T_CS_R: J5.11, R40.2
T_DIN_R: J5.12, R41.2
T_DO_R: J5.13, R42.2
T_IRQ: R43.1, U1.6 (IO6)
T_IRQ_R: J5.14, R43.2
USB_DN: J1.A7 (D-), J1.B7 (D-), U1.13 (USB_D-), U4.1 (IO1), U4.6 (IO4)
USB_DP: J1.A6 (D+), J1.B6 (D+), U1.14 (USB_D+), U4.3 (IO2), U4.4 (IO3)
VBUS: C47.1, J1.A4 (VBUS), J1.A9 (VBUS), J1.B4 (VBUS), J1.B9 (VBUS), U4.5 (VP), U12.6 (VIN2)
VIN: F1.1, J2.1
VIN_F: D8.1 (A1), F1.2, Q8.3 (D)
VIN_GATE: D11.2 (A), Q8.1 (G), R62.1
VIN_P: C41.1, C42.1, C43.1, D9.1 (K), D10.1 (K), D11.1 (K), J4.1, J9.1, LED3.2 (A), LED4.2 (A), Q8.2 (S), U11.1 (VIN)
VLED: C10.1, D3.1 (K), LED1.1 (VDD)
WDT_CT_N: C38.1, U10.6 (Cext)
WDT_CT_P: C38.2, R46.2, TP12.1, U10.7 (RCext)
WDT_KICK: R48.1, U1.29 (IO36), U10.2 (B)
WDT_OK: Q3.1 (G), R49.1, U10.5 (Q)
WS_DIN: LED1.4 (DIN), R3.2

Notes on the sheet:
THERMOCOUPLE 1 (control) MAX31856 T- floats to J3, biased via BIAS
SPI BUS DAMPING + CHIP-SELECT PULL-UPS + I2C EXPANSION R39-R43 damp the display module's XPT2046 touch lines and R54-R58 the four 40 MHz display lines; both loom to J5. R56 is also the SDO hedge - lift it if the panel does not tri-state J5.9 off the shared SPI_MISO. R50-R53 hold all four chip selec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
POWER IN 24 VDC terminal or USB F1+D8 clamp-and-blow at the entry. Q8 blocks reverse polarity as a P-FET, not a diode: its body diode conducts on correct polarity and the gate then pulls itself on through R62, clamped by D11 because 24 V is twice the AO3401A's V_GS rating. U11 (right) makes BUCK_5V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
ESP32-S3-WROOM-1U-N16R2 GPIOs = firmware Kconfig defaults
THERMOCOUPLE 2 (load) MAX31856 T- floats to J8, biased via BIAS
SSR DRIVE x2 24 V terminals off VIN_P, switched low side by a 60 V CJ2310. The GPIO drives an opto LED, never the gate: at 24 V a gate-to-drain failure would otherwise put 240 mA into the pin. Opto collectors sit on SSR_EN (5 V), so the gate lands at ~4.9 V from the RAIL rather than from CTR. Q7 is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
ALARM BUZZER
HEADERS J5 display+touch (14-pin), J6 nav, J7 aux+I2C
TEST POINTS
AUX OUTPUT BANK ULN2003 vent/purge/spare; COM->AUX_VP, SJ1 links to +5V
NOTES - Bisque kiln controller, rev B
WS2812B STATUS LED VDD dropped ~4.6V for 3.3V data margin
USB-C native USB flashing + ESD
PROTECTED INPUTS x3 lid / gas-flow / spare 1k + 10k pull-up + 100nF each, SRV05-4 TVS
CT CURRENT SENSING ADE7953, I2C, current-only no mains - VP/VN to DNP J13
MOUNTING / FIDUCIALS / POWER FLAGS FID1-3 are bare-copper pick-and-place targets, on no net
24 V -> 5 V BUCK XL1509-5.0, fixed output C41-C43 in, D7 catch, L1 47uH, C44/C45/C46 out. FB ties to the output because the part is the fixed 5.0 V version; EN is active LOW and grounded. C46 is an ELECTROLYTIC on purpose: voltage-mode with fixed compensation needs its ESR zero, and an all-ceramic 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
SSR terminals J4/J9: pin1 = VIN_P (24 V, fused and TVS-clamped, ALWAYS LIVE), pin2 = the switched low side. The watchdog gates the shared return (Q7), not the supply, so a tripped watchdog leaves 24 V on pin 1 and opens pin 2. Boot-safe: R7/R20 hold each gate down while the optos are dark. The opto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
HARDWARE WATCHDOG U10 retriggerable one-shot: every rising edge on WDT_KICK restarts a ~2.2 s window, so Q stays high only while firmware keeps kicking. Q holds Q3 on; Q3 pulls SSR_PG down, turning on high-side Q4, which supplies SSR_EN - the +5V GATE DRIVE rail feeding both opto collectors and Q7'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
RESET / BOOT / DECOUPLING

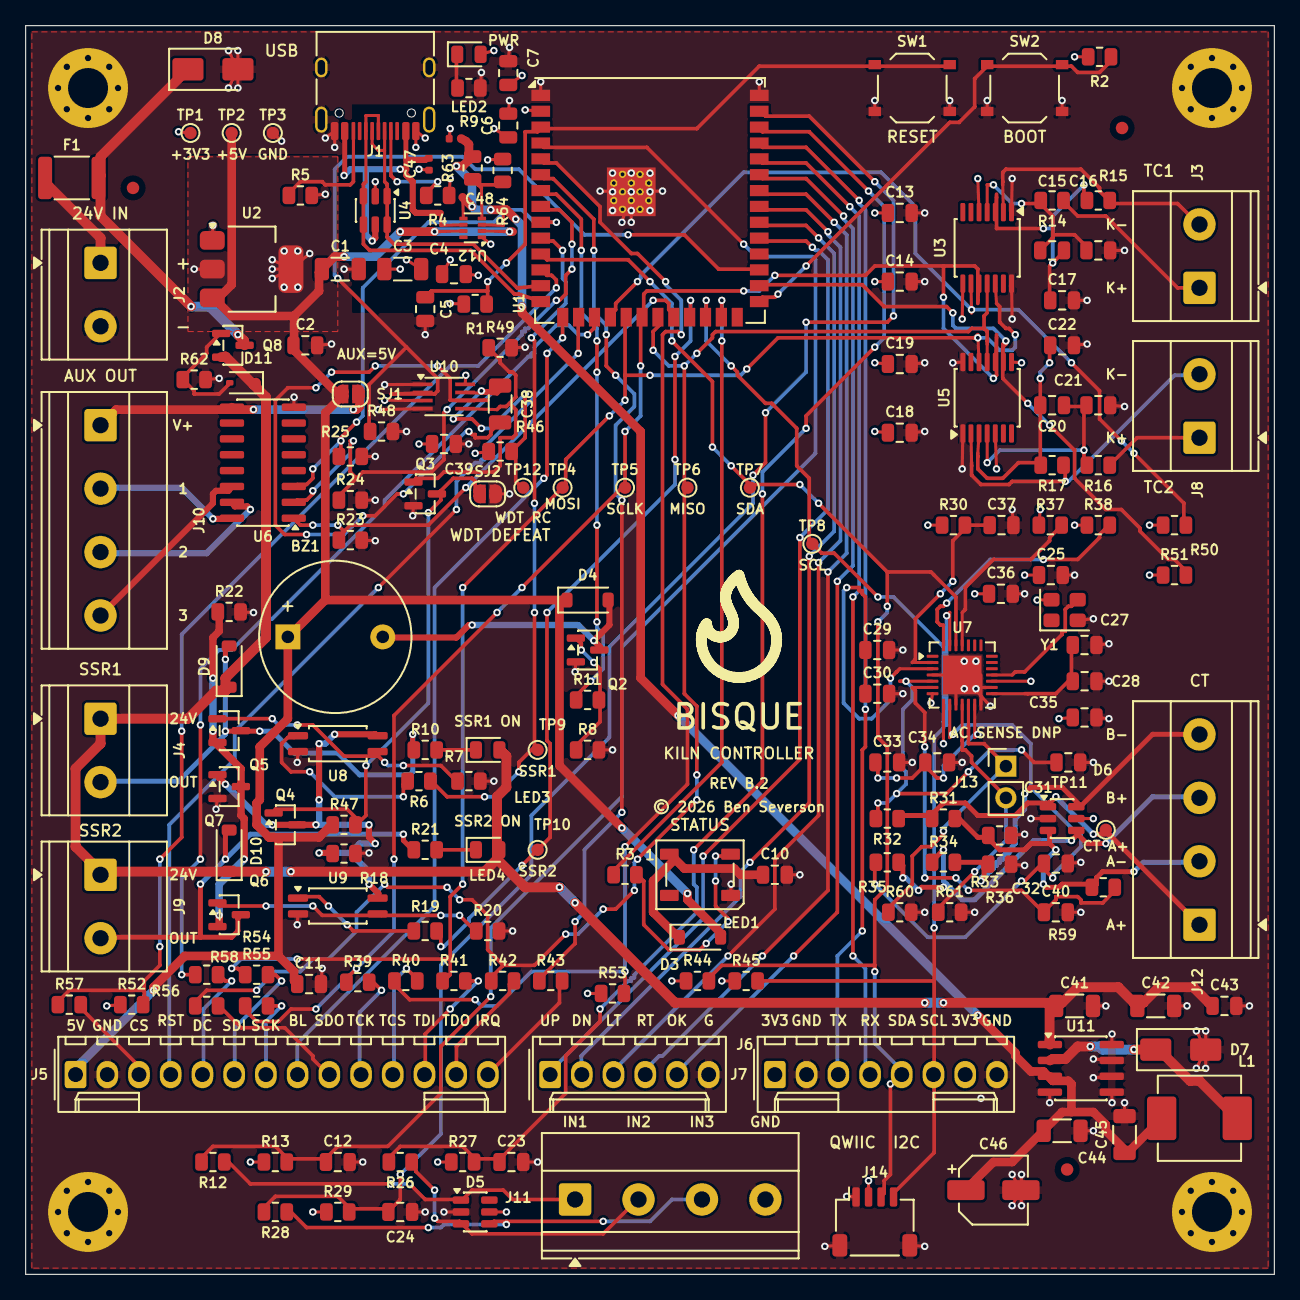
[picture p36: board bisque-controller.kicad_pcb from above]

Board: 4 copper layers, 100.0 x 100.0 mm, 182 parts (0 on the bottom side), 108 nets.

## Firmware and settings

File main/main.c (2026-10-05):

#include <stdbool.h>
#include <stdio.h>
#include "freertos/FreeRTOS.h"
#include "freertos/task.h"
#include "esp_log.h"
#include "esp_timer.h"
#include "esp_heap_caps.h"
#include "nvs_flash.h"
#include "esp_app_desc.h"
#include "ota_manager.h"
#include "driver/gpio.h"
#include "driver/spi_master.h"
#include "mdns.h"
#include "esp_sntp.h"

#include "app_config.h"
#include "thermocouple.h"
#include "firing_engine.h"
#include "safety.h"
#include "wifi_manager.h"
#include "web_server.h"
#include "display.h"
#include "boot_status.h"
#include "firing_history.h"
#include "status_led.h"
#include "device_log.h"

static const char *TAG = "main";

/* Create a Core 1 control task, turning FreeRTOS's silent errCOULD_NOT_ALLOCATE
   into an esp_err_t the caller can ESP_ERROR_CHECK. A control task that never
   starts is not a degraded mode: without safety_task there is no over-temp
   check, no SSR heartbeat, and no thermocouple-fault watchdog. Fail loudly. */
static esp_err_t start_control_task(TaskFunction_t fn, const char *name, uint32_t stack, UBaseType_t prio)
{
    if (xTaskCreatePinnedToCore(fn, name, stack, NULL, prio, NULL, 1) != pdPASS) {
        ESP_LOGE(TAG, "Failed to create %s task — out of internal RAM?", name);
        return ESP_ERR_NO_MEM;
    }
    return ESP_OK;
}

static void ws_broadcast_timer_cb(void *arg)
{
    (void)arg;
    /* Wake the broadcast worker; never block here — esp_timer callbacks run on
       a single shared task and any blocking work would stall every other timer. */
    ws_broadcast_notify();
}

void app_main(void)
{
    /* Before the first line worth keeping: the log hook only sees what is
       logged after it is installed, so this goes ahead of the banner. A failure
       here is not fatal — it costs the diagnostics bundle its log section and
       nothing else. */
    if (device_log_init() != ESP_OK) {
        ESP_LOGW(TAG, "Device log unavailable — /api/v1/log will be empty");
    }

    /* version already carries a leading 'v' (git describe of v* tags). */
    ESP_LOGI(TAG, "=== Bisque %s ===", esp_app_get_description()->version);

    /* ── NVS Init ──────────────────────────────────── */
    esp_err_t ret = nvs_flash_init();
    if (ret == ESP_ERR_NVS_NO_FREE_PAGES || ret == ESP_ERR_NVS_NEW_VERSION_FOUND) {
        ESP_ERROR_CHECK(nvs_flash_erase());
        ret = nvs_flash_init();
    }
    ESP_ERROR_CHECK(ret);

    /* ── SPI Bus Init (shared by thermocouple + display) ── */
    spi_bus_config_t spi_bus_cfg = {
        .mosi_io_num = APP_PIN_SPI_MOSI,
        .miso_io_num = APP_PIN_SPI_MISO,
        .sclk_io_num = APP_PIN_SPI_SCLK,
        .quadwp_io_num = -1,
        .quadhd_io_num = -1,
        .max_transfer_sz = APP_LCD_H_RES * 40 * 2,
    };
    ESP_ERROR_CHECK(spi_bus_initialize(APP_SPI_HOST, &spi_bus_cfg, SPI_DMA_CH_AUTO));
    ESP_LOGI(TAG, "SPI bus initialized");

    /* Park the chip selects of populated-but-undriven bus peers HIGH before any
     * traffic. Rev B multi-drops four devices on SPI2 — the LCD, both MAX31856s
     * and the XPT2046 touch controller — but only the LCD and TC1 have drivers,
     * which own their CS via spics_io_num. TC2's and touch's CS are left in
     * their reset state: no firmware writes them and neither net carries a
     * pull-up, so both sit floating at an active-low input. A float sampled low
     * puts that device on the bus for every transaction, and it drives MISO
     * alongside TC1 — so the failure is not "channel 2 misbehaves", it is TC1's
     * CR0 probe failing or its temperature reads returning contended data.
     *
     * The level is latched before the output driver is enabled so enabling it
     * cannot glitch the line low. Drop a pin from this list only when something
     * else has taken ownership of it (TC2 at RB-3, touch when a driver lands). */
    static const int idle_cs_pins[] = {APP_PIN_TC2_CS, APP_PIN_TOUCH_CS};
    for (size_t i = 0; i < sizeof(idle_cs_pins) / sizeof(idle_cs_pins[0]); i++) {
        int pin = idle_cs_pins[i];
        if (pin < 0) {
            continue; /* -1 = not fitted on this build */
        }
        gpio_set_level(pin, 1);
        gpio_config_t cs_cfg = {
            .pin_bit_mask = 1ULL << pin,
            .mode = GPIO_MODE_OUTPUT,
            /* Holds the line deasserted if the pin is ever floated again. */
            .pull_up_en = GPIO_PULLUP_ENABLE,
            .pull_down_en = GPIO_PULLDOWN_DISABLE,
            .intr_type = GPIO_INTR_DISABLE,
        };
        ESP_ERROR_CHECK(gpio_config(&cs_cfg));
        gpio_set_level(pin, 1);
        ESP_LOGI(TAG, "Parked idle SPI chip select on GPIO %d", pin);
    }

    /* Zone 2's SSR control has no driver until RB-5 (#310), and rev B.2 no
     * longer pins that line on the board: R20 moved to the gate side of the
     * U9 opto, so the GPIO's only load is the opto LED. The ESP32-S3 resets
     * GPIO 21 with no pull (datasheet v2.2 pin overview), so channel 2 is off
     * today by the datasheet alone. Hold it low explicitly, before
     * safety_init_wdt() starts the kick, so the watchdog never goes live with
     * the line undefined. RB-5 takes ownership of this pin. */
    if (APP_PIN_SSR2 >= 0) {
        gpio_set_level(APP_PIN_SSR2, 0);
        gpio_config_t ssr2_cfg = {
            .pin_bit_mask = 1ULL << APP_PIN_SSR2,
            .mode = GPIO_MODE_OUTPUT,
            .pull_up_en = GPIO_PULLUP_DISABLE,
            .pull_down_en = GPIO_PULLDOWN_ENABLE,
            .intr_type = GPIO_INTR_DISABLE,
        };
        ESP_ERROR_CHECK(gpio_config(&ssr2_cfg));
        gpio_set_level(APP_PIN_SSR2, 0);
        ESP_LOGI(TAG, "Parked zone 2 SSR control low on GPIO %d", APP_PIN_SSR2);
    }

    /* ── Thermocouple Init ─────────────────────────── */
    ESP_ERROR_CHECK(thermocouple_init(APP_SPI_HOST, APP_PIN_TC1_CS));

    /* ── Safety Init ───────────────────────────────── */
    ESP_ERROR_CHECK(safety_init(APP_PIN_SSR1, APP_DEFAULT_MAX_SAFE_TEMP));
    safety_init_io(APP_PIN_ALARM, APP_PIN_VENT, APP_PIN_LID_SWITCH);
    safety_init_wdt(APP_PIN_WDT_KICK);

    /* ── Firing Engine Init ────────────────────────── */
    ESP_ERROR_CHECK(firing_engine_init());

    /* Update safety max temp from loaded settings */
    kiln_settings_t settings;
    firing_engine_get_settings(&settings);
    safety_set_max_temp(settings.max_safe_temp);
    safety_set_tc_offset(settings.tc_offset_c);

    /* ── Storage for the firing history ────────────── */
    /* Mounted here rather than implicitly inside web_server_start() so
       history_init() — firing_task's only external dependency — is ready before
       the control tasks below. The mount is idempotent; web_server_start()
       still calls it and gets a no-op. */
    if (web_server_mount_spiffs() != ESP_OK) {
        ESP_LOGW(TAG, "SPIFFS mount failed; history and static files unavailable");
    }
    history_init();

    /* ── Create Real-Time Control Tasks (Core 1) ───── */
    /* These come before every optional or slow subsystem below — display, Wi-Fi,
       mDNS, NTP, web server. Safety supervision must never be gated on hardware
       that may be absent or on a network stack that can stall for 30 s (#250):
       safety_task is what runs the over-temp check, the SSR heartbeat, and the
       thermocouple-fault watchdog, and it is useless if it starts last.
       Keep it that way — nothing that can energize the SSR belongs above here. */
    ESP_ERROR_CHECK(start_control_task(safety_task, "safety", APP_TASK_SAFETY_STACK, APP_TASK_SAFETY_PRIO));
    ESP_ERROR_CHECK(start_control_task(temp_read_task, "temp_read", APP_TASK_TEMP_READ_STACK, APP_TASK_TEMP_READ_PRIO));
    ESP_ERROR_CHECK(start_control_task(firing_task, "firing", APP_TASK_FIRING_STACK, APP_TASK_FIRING_PRIO));

    /* ── Display Init ──────────────────────────────── */
    ret = display_init(APP_SPI_HOST, APP_PIN_LCD_CS, APP_PIN_LCD_DC, APP_PIN_LCD_RST, APP_PIN_LCD_BL);
    bool display_initialized = (ret == ESP_OK);
    if (ret != ESP_OK) {
        ESP_LOGW(TAG, "Display init failed (non-fatal): %s", esp_err_to_name(ret));
    }

    /* Bring up the display task immediately so the splash is on-screen during
     * the slow init steps below (Wi-Fi can take up to 30 s). The task gets a
     * hard error check because if internal SRAM is too tight to satisfy the
     * 16 KiB stack, FreeRTOS silently returns errCOULD_NOT_ALLOCATE and the UI
     * just never starts (with no diagnostic) — easier to crash loudly. */
    if (display_initialized) {
        BaseType_t disp_rc = xTaskCreatePinnedToCore(display_task, "display", APP_TASK_DISPLAY_STACK, NULL,
                                                     APP_TASK_DISPLAY_PRIO, NULL, 0);
        if (disp_rc != pdPASS) {
            ESP_LOGE(TAG, "Failed to create display_task (rc=%d) — out of internal RAM?", (int)disp_rc);
            abort();
        }
    } else {
        ESP_LOGW(TAG, "Display task skipped; controller will run headless");
    }

    /* ── Wi-Fi Init ────────────────────────────────── */
    /* Try NVS-saved credentials first, fall back to compile-time config */
    char nvs_ssid[WIFI_SSID_BUF_LEN] = {0};
    char nvs_pass[WIFI_PASS_BUF_LEN] = {0};
    const char *sta_ssid = "";
    const char *sta_pass = "";
    if (wifi_manager_load_creds(nvs_ssid, sizeof(nvs_ssid), nvs_pass, sizeof(nvs_pass)) == ESP_OK && nvs_ssid[0]) {
        sta_ssid = nvs_ssid;
        sta_pass = nvs_pass;
        ESP_LOGI(TAG, "Using Wi-Fi credentials from NVS");
    } else {
#ifdef CONFIG_KILN_WIFI_STA_SSID
        sta_ssid = CONFIG_KILN_WIFI_STA_SSID;
        sta_pass = CONFIG_KILN_WIFI_STA_PASS;
        ESP_LOGI(TAG, "Using compile-time Wi-Fi credentials");
        if (sta_ssid[0]) {
            /* Seed NVS so the credentials persist across firmware updates even
               if later removed from sdkconfig.local. */
            wifi_manager_save_creds(sta_ssid, sta_pass);
        }
#else
        ESP_LOGI(TAG, "No Wi-Fi credentials configured, starting in AP mode");
#endif
    }
    ESP_ERROR_CHECK(wifi_manager_init(sta_ssid, sta_pass, APP_WIFI_AP_SSID, APP_WIFI_AP_PASS));

    /* Wait for Wi-Fi (30s timeout) */
    boot_status_set("Connecting to Wi-Fi...");
    if (wifi_manager_wait_connected(30000) == ESP_OK) {
        ESP_LOGI(TAG, "Wi-Fi ready: %s (AP mode: %s)", wifi_manager_get_ip(), wifi_manager_is_ap_mode() ? "yes" : "no");
    } else {
        ESP_LOGW(TAG, "Wi-Fi connection timed out");
    }
    if (wifi_manager_is_ap_mode()) {
        boot_status_set("Wi-Fi: access point mode");
    }

    /* ── Status LED Init ────────────────────────────── */
    bool status_led_initialized = (status_led_init() == ESP_OK);
    if (!status_led_initialized) {
        ESP_LOGW(TAG, "Status LED init failed (non-fatal)");
    }

    /* ── mDNS ─────────────────────────────────────── */
    {
        esp_err_t mdns_err = mdns_init();
        if (mdns_err == ESP_OK) {
            mdns_hostname_set("bisque");
            mdns_instance_name_set("Bisque Kiln Controller");
            mdns_service_add(NULL, "_http", "_tcp", 80, NULL, 0);
            ESP_LOGI(TAG, "mDNS: http://bisque.local/");
        } else {
            ESP_LOGW(TAG, "mDNS init failed: %s", esp_err_to_name(mdns_err));
        }
    }

    /* ── NTP Time Sync ─────────────────────────────── */
    /* Start unconditionally: SNTP polls in the background and syncs whenever
       connectivity appears, so a STA that associates after the 30 s boot wait
       (or after a later AP→STA transition) still gets the clock set. In pure AP
       mode there's no route to pool.ntp.org and it simply keeps retrying
       harmlessly — cheap next to leaving firing-history timestamps at 1970. */
    esp_sntp_setoperatingmode(SNTP_OPMODE_POLL);
    esp_sntp_setservername(0, "pool.ntp.org");
    esp_sntp_init();
    ESP_LOGI(TAG, "NTP sync started");

    /* ── Web Server Init ───────────────────────────── */
    /* SPIFFS is already mounted (above, for history_init); this re-mount is a
       no-op and only serves as the fallback if that ordering ever changes. */
    ESP_ERROR_CHECK(web_server_start());
    ESP_LOGI(TAG, "Web server started at http://%s/", wifi_manager_get_ip());

    /* ── Create Remaining Tasks (Core 0: UI + network) ── */
    /* The Core 1 control tasks and display_task were created earlier — see the
     * ordering note above safety_task's creation. */

    if (status_led_initialized) {
        xTaskCreatePinnedToCore(status_led_task, "status_led", 2048, NULL, 1, NULL, 0);
    } else {
        ESP_LOGW(TAG, "Status LED task skipped");
    }

    /* ── Workers driven off firing engine + WS broadcast timer ── */
    ESP_ERROR_CHECK(ws_handler_start());
    ESP_ERROR_CHECK(notification_task_start());

    const esp_timer_create_args_t ws_timer_args = {
        .callback = ws_broadcast_timer_cb,
        .name = "ws_broadcast",
    };
    esp_timer_handle_t ws_timer;
    ESP_ERROR_CHECK(esp_timer_create(&ws_timer_args, &ws_timer));
    ESP_ERROR_CHECK(esp_timer_start_periodic(ws_timer, 1000000)); /* 1s broadcast interval */

    /* ── OTA Rollback Validation ─────────────────────── */
    /* If we booted after an OTA update, defer confirmation to a task that
       observes a healthy-uptime window before canceling rollback. A boot
       loop or panic reboots before the window elapses, so the bootloader
       reverts to the previous firmware. */
    ota_confirm_task_start();

    boot_status_set("Ready");
    boot_status_mark_ready();

    ESP_LOGI(TAG, "=== Bisque started successfully ===");
    /* Report internal SRAM separately: with PSRAM enabled the total is in the
       megabytes and hides the pool that actually constrains this firmware —
       task stacks, DMA buffers and MALLOC_CAP_INTERNAL requests all come out
       of internal RAM only. */
    ESP_LOGI(TAG, "Free heap: %lu bytes total, %lu bytes internal", (unsigned long)esp_get_free_heap_size(),
             (unsigned long)heap_caps_get_free_size(MALLOC_CAP_INTERNAL));
}

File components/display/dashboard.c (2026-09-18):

#include "dashboard.h"
#include "modal.h"
#include "modal_profile_picker.h"
#include "modal_action_menu.h"
#include "ui_common.h"
#include "ui_widgets.h"
#include "firing_engine.h"
#include "firing_history.h"
#include "esp_log.h"
#include <stdio.h>
#include <string.h>

extern lv_group_t *g_input_group;

static const char *TAG = "dashboard";

#define STATUS_BAR_H 44
#define CONTENT_Y    STATUS_BAR_H
#define LEFT_COL_X   16
#define LEFT_COL_W   180

#define CHART_X                    206
#define CHART_Y_REL                (52 - CONTENT_Y)
#define CHART_W                    258
#define CHART_H                    212
#define CHART_POINTS               240
#define CHART_DEFAULT_DUR_S        3600u /* fallback when active profile has no estimate */
#define CHART_Y_MAX_DEFAULT        1400
#define CHART_PLANNED_START_TEMP_C 20.0f /* assumed cold-kiln start */

/* Visual state of the dashboard. Selected from firing_progress_t.status. */
typedef enum {
    VIEW_NONE = 0,
    VIEW_IDLE,
    VIEW_ACTIVE,
    VIEW_PAUSED,
    VIEW_COMPLETE,
    VIEW_ERROR,
    VIEW_AUTOTUNE,
} view_id_t;

/* Widget tree backing a view. Several views share one layout: ACTIVE, PAUSED and AUTOTUNE
 * are all drawn by build_view_active() and differ only in runtime-toggled details (the
 * PAUSED overlay, the status bar). Content is torn down and rebuilt per *layout*, never per
 * view, so a pause/resume keeps the chart's accumulated firing curve alive. */
typedef enum {
    LAYOUT_NONE = 0,
    LAYOUT_IDLE,
    LAYOUT_ACTIVE,
    LAYOUT_COMPLETE,
    LAYOUT_ERROR,
} layout_id_t;

/* Persistent widgets, created once in dashboard_create. */
static lv_obj_t *s_screen = NULL;
static lv_obj_t *s_status_bar = NULL;
static lv_obj_t *s_status_label = NULL;
static lv_obj_t *s_seg_label = NULL;
/* Downdraft vent indicator, parked in the status bar just left of the segment
 * label and hidden unless the relay is actually energized. It lives on the bar
 * rather than inside a view so it survives every layout swap — the vent runs
 * across IDLE (a delayed start is armed), ACTIVE and PAUSED alike. */
static lv_obj_t *s_vent_label = NULL;
static bool s_vent_shown = false;
/* Lid interlock indicator, parked immediately left of the vent marker and shown
 * only while the lid is actually open. Same reasoning as the vent: it lives on
 * the bar rather than in a view, because the lid can be opened in any state. */
static lv_obj_t *s_lid_label = NULL;
static bool s_lid_shown = false;
/* Invisible focusable widget. The encoder always points at it (in g_input_group),
 * so a SELECT press fires LV_EVENT_CLICKED and we open the contextual modal. */
static lv_obj_t *s_select_trap = NULL;

/* Swappable per-view content container. View-specific widgets are children. */
static lv_obj_t *s_content = NULL;
static view_id_t s_current_view = VIEW_NONE;
/* Last status painted onto the status bar; sentinel forces a repaint on first update. */
static firing_status_t s_prev_status = (firing_status_t)-1;
/* Last segment indices painted into the status bar, and whether the label is
 * currently blank. Blankness is tracked separately rather than inferred from
 * total_segments == 0: auto-tune runs with no segments at all, so a zero total
 * is a legitimate painted state ("SEGMENT 1/0"), not a blank one. Conflating
 * the two left auto-tune's stale text on screen after the view changed. */
static uint8_t s_prev_segment = 0;
static uint8_t s_prev_total_segments = 0;
static bool s_seg_label_blank = true;

/* IDLE view widgets. */
static lv_obj_t *s_idle_temp = NULL;

/* ACTIVE / PAUSED / AUTOTUNE view widgets. */
static lv_obj_t *s_active_temp = NULL;
static lv_obj_t *s_active_target = NULL;
static lv_obj_t *s_active_elapsed = NULL;
static lv_obj_t *s_active_remaining = NULL;
static lv_obj_t *s_active_remaining_hdr = NULL;
static lv_obj_t *s_chart = NULL;
static lv_chart_series_t *s_chart_actual = NULL;
static lv_chart_series_t *s_chart_planned = NULL;
static lv_obj_t *s_paused_overlay = NULL;

/* COMPLETE view widgets. */
static lv_obj_t *s_complete_now_temp = NULL;

/* ERROR view widgets. */
static lv_obj_t *s_error_now_temp = NULL;

/* Cached active profile + derived total duration. Refreshed when entering a profile-using
 * view from a non-profile view, or when the engine's profile_id changes.
 * s_cached_profile_id records the id we last *attempted*, so a profile that fails to load
 * is not re-attempted (and does not look like a fresh change) on every update. */
static firing_profile_t s_cached_profile;
static bool s_cached_profile_valid = false;
static char s_cached_profile_id[FIRING_ID_LEN] = "";
static uint32_t s_cached_total_dur_s = CHART_DEFAULT_DUR_S;
/* Peak temperature of the firing currently being displayed. Reset when a firing begins,
 * reported by the COMPLETE view. */
static float s_active_peak_c = 0.0f;

/* ── Mapping helpers ─────────────────────────────────── */
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

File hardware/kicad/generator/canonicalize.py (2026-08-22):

"""Rewrite a .kicad_pcb into canonical form so rebuilds are reproducible.

pcbnew mints a fresh random KIID for every item it constructs, and KiCad's
s-expression writer sorts board items with comparators whose key chain ends
in that KIID — footprints sort by it outright, tracks and vias use it to
break position ties. Nothing else about the board is random, so an
unchanged design still serialises to a file with a different item order and
~2000 different uuid strings on every single run (issue #234): regenerating
the board produced a ~20k-line diff against an identical board.

The Python API exposes no setter for m_Uuid, so the fix is applied to the
saved file instead: every uuid is replaced by one derived from the item's
own content, and items are re-sorted on that same content. Ordering then
follows from the uuids being stable, which is why fixing the uuids is
enough to fix both — and why the zone fill stabilises too, KiCad's filler
being deterministic given identical input.

Only uuid strings and the order of top-level items change; every other byte
KiCad wrote is preserved, so the result is still a file KiCad would have
written. Uuids are not cross-referenced anywhere in a .kicad_pcb (nets are
matched by name in KiCad 10), so renaming them is safe.

The content order this leaves behind is an implementation detail, and not
what a board built by this repo is stored in: it exists so that the ordinal
in a uuid's seed is a function of the design rather than of where pcbnew
happened to put the item. kicad_build.py re-sorts into KiCad's own order
afterwards (resort_to_kicad_order), because that is the order the GUI writes
and storing the file in anything else means every save is a whole-file diff.
So do not read the sort here as "the canonical order of the board" - the
canonical thing this module provides is the uuids.

Usage: python3 canonicalize.py board.kicad_pcb [...]
"""
import re
import sys
import uuid

# Fixed namespace, so the uuid for a given item is the same on every
# machine and every run, forever.
NAMESPACE = uuid.uuid5(uuid.NAMESPACE_URL,
                       "https://github.com/BenSeverson/bisque#kicad-canonical")

_UUID_VALUE = re.compile(r'(\(uuid\s+")[^"]*(")')
_HEAD = re.compile(r'\(\s*([^\s()"]+)')


def top_level_spans(text):
    """(start, end) for every direct child of the root s-expression."""
    spans = []
    depth = start = 0
    in_str = esc = False
    for i, ch in enumerate(text):
        if in_str:
            if esc:
                esc = False
            elif ch == "\\":
                esc = True
            elif ch == '"':
                in_str = False
        elif ch == '"':
            in_str = True
        elif ch == "(":
            depth += 1
            if depth == 2:
                start = i
        elif ch == ")":
            if depth == 2:
                spans.append((start, i + 1))
            depth -= 1
            if depth == 0:
                break
    return spans


def node_kind(node):
    m = _HEAD.match(node)
    return m.group(1) if m else ""


def identity(node):
    """The item stripped of its uuids — everything that describes the
    design, and nothing that a rerun is free to change."""
    return _UUID_VALUE.sub(lambda m: m.group(1) + m.group(2), node)


def _fill_uuids(ident, ordinal):
    """Put content-derived uuids back into a blanked item."""
    counter = [0]

    def sub(m):
        seed = "%s\x00%d\x00%d" % (ident, ordinal, counter[0])
        counter[0] += 1
        return m.group(1) + str(uuid.uuid5(NAMESPACE, seed)) + m.group(2)

    return _UUID_VALUE.sub(sub, ident)


def canonicalize_text(text):
    spans = top_level_spans(text)
    if not spans:
        return text
    nodes = [text[s:e] for s, e in spans]
    gaps = [text[spans[i][1]:spans[i + 1][0]] for i in range(len(spans) - 1)]

    # Sort each kind of item among the slots that kind already occupies, so
    # the file keeps the layout KiCad gave it (header, footprints, graphics,
    # tracks, vias, zones) and only the order *within* a kind is fixed.
    slots = {}
    for i, node in enumerate(nodes):
        slots.setdefault(node_kind(node), []).append(i)
    ordered = [None] * len(nodes)
    for kind, idxs in slots.items():
        for slot, ident in zip(idxs, sorted(identity(nodes[i]) for i in idxs)):
            ordered[slot] = ident

    # Items identical but for their uuids are interchangeable, so number
    # them off in output order rather than by where they used to sit.
    seen = {}
    out = []
    for ident in ordered:
        ordinal = seen[ident] = seen.get(ident, -1) + 1
        out.append(_fill_uuids(ident, ordinal))

    body = out[0]
    for gap, node in zip(gaps, out[1:]):
        body += gap + node
    return text[:spans[0][0]] + body + text[spans[-1][1]:]


def canonicalize_file(path):
    """Canonicalise in place. True if the file changed."""
    with open(path) as fh:
        text = fh.read()
    canon = canonicalize_text(text)
    if canon == text:
        return False
    with open(path, "w") as fh:
        fh.write(canon)
    return True


def main(argv):
    if not argv:
        sys.exit(__doc__.strip().splitlines()[-1])
    for path in argv:
        print("canonicalized %s" % path if canonicalize_file(path)
              else "already canonical %s" % path)
    return 0


if __name__ == "__main__":
    sys.exit(main(sys.argv[1:]))

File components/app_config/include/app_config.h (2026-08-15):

#pragma once

/*
 * Bisque — Hardware Pin Assignments and Default Constants
 *
 * All GPIO assignments are configurable via Kconfig (menuconfig). Defaults
 * live in main/Kconfig.projbuild; edit pins there (or via `idf.py menuconfig`),
 * not here.
 */

/* --- SPI Bus (shared by thermocouple + display) --- */
#define APP_SPI_HOST     SPI2_HOST
#define APP_PIN_SPI_MOSI CONFIG_KILN_PIN_SPI_MOSI
#define APP_PIN_SPI_MISO CONFIG_KILN_PIN_SPI_MISO
#define APP_PIN_SPI_SCLK CONFIG_KILN_PIN_SPI_SCLK

/* --- MAX31856 Thermocouple (2 channels on the shared SPI bus) --- */
#define APP_PIN_TC1_CS CONFIG_KILN_PIN_TC1_CS
#define APP_PIN_TC2_CS CONFIG_KILN_PIN_TC2_CS

/* --- SSR Outputs (opto-isolated, 2 zones) --- */
#define APP_PIN_SSR1 CONFIG_KILN_PIN_SSR1
#define APP_PIN_SSR2 CONFIG_KILN_PIN_SSR2

/* --- ST7796S Display --- */
#define APP_PIN_LCD_CS  CONFIG_KILN_PIN_LCD_CS
#define APP_PIN_LCD_DC  CONFIG_KILN_PIN_LCD_DC
#define APP_PIN_LCD_RST CONFIG_KILN_PIN_LCD_RST
#define APP_PIN_LCD_BL  CONFIG_KILN_PIN_LCD_BL

#define APP_LCD_H_RES 480
#define APP_LCD_V_RES 320
/* ST7796S datasheet rates the write cycle at 66 MHz (Tcycw=15ns); 40 MHz keeps
 * margin for a keyed display loom in a noisy kiln environment. The margin was
 * originally sized for hand-soldered wiring; nothing has re-measured it on the
 * routed board, so treat 40 MHz as inherited rather than as the ceiling. */
#define APP_LCD_SPI_FREQ_HZ (40 * 1000 * 1000)

/* --- PID Defaults --- */
#define APP_PID_KP_DEFAULT 2.0f
#define APP_PID_KI_DEFAULT 0.01f
/* Pre-autotune starting derivative gain. Kept modest because the MAX31855's
 * 0.25°C quantization step, at the 1 Hz tick, turned a large Kd into a
 * noise-driven bang-bang term (see pid_compute's filtered derivative).
 *
 * THAT RATIONALE IS REV A's. Rev B reads 2x MAX31856 at 19-bit resolution
 * (0.0078125°C), roughly 32x finer, so the quantization noise this value was
 * chosen to survive is gone. The value is carried forward unchanged because
 * nothing has measured the replacement — revisit it on the bench at rev B
 * bring-up rather than inheriting it silently. Autotune overrides it either
 * way; it is a safe default, not a tuned one. */
#define APP_PID_KD_DEFAULT 5.0f
#define APP_PID_OUTPUT_MIN 0.0f
#define APP_PID_OUTPUT_MAX 1.0f
#define APP_PID_PERIOD_MS  1000

/* --- SSR Time-Proportional Period --- */
#define APP_SSR_WINDOW_MS 2000

/* --- Safety --- */
#define APP_HARDWARE_MAX_TEMP_C   1400.0f
#define APP_DEFAULT_MAX_SAFE_TEMP 1300.0f
#define APP_TEMP_FAULT_TIMEOUT_MS 5000

/* --- Wi-Fi --- */
#define APP_WIFI_AP_SSID    "Bisque"
#define APP_WIFI_AP_PASS    "bisquesetup"
#define APP_WIFI_AP_CHANNEL 1
#define APP_WIFI_MAX_RETRY  5

/* --- Task Configuration --- */
#define APP_TASK_SAFETY_PRIO    6
#define APP_TASK_TEMP_READ_PRIO 5
#define APP_TASK_FIRING_PRIO    4
#define APP_TASK_HTTPD_PRIO     3
#define APP_TASK_DISPLAY_PRIO   2

#define APP_TASK_SAFETY_STACK    4096
#define APP_TASK_TEMP_READ_STACK 4096
#define APP_TASK_FIRING_STACK    8192
#define APP_TASK_DISPLAY_STACK   16384

/* --- Input Buttons (5-way navigation switch: Up/Down/Left/Right/Center) --- */
#define APP_PIN_BTN_UP     CONFIG_KILN_PIN_BTN_UP
#define APP_PIN_BTN_DOWN   CONFIG_KILN_PIN_BTN_DOWN
#define APP_PIN_BTN_SELECT CONFIG_KILN_PIN_BTN_SELECT
#define APP_PIN_BTN_LEFT   CONFIG_KILN_PIN_BTN_LEFT
#define APP_PIN_BTN_RIGHT  CONFIG_KILN_PIN_BTN_RIGHT

/* --- Status LED (WS2812B) --- */
#define APP_PIN_STATUS_LED CONFIG_KILN_PIN_STATUS_LED

/* --- Optional GPIOs (-1 = disabled) --- */
#define APP_PIN_ALARM      CONFIG_KILN_PIN_ALARM
#define APP_PIN_VENT       CONFIG_KILN_PIN_VENT
#define APP_PIN_LID_SWITCH CONFIG_KILN_PIN_LID_SWITCH
/* Aux output bank (ULN2003 channels 1-3). Routed and populated on the rev B
   PCB but NOT DRIVEN BY ANY CODE except AUX1, which components/safety/ drives
   as the vent. Roles are firmware policy, not wiring — see
   docs/pin-assignments.md §5. */
#define APP_PIN_AUX2 CONFIG_KILN_PIN_AUX2
#define APP_PIN_AUX3 CONFIG_KILN_PIN_AUX3

/* Protected dry-contact inputs. IN1 is the lid switch (APP_PIN_LID_SWITCH). */
#define APP_PIN_IN_GASFLOW CONFIG_KILN_PIN_IN_GASFLOW
#define APP_PIN_IN_SPARE   CONFIG_KILN_PIN_IN_SPARE

/* I2C bus: on-board ADE7953 current metering + Qwiic expansion header. */
#define APP_PIN_I2C_SDA CONFIG_KILN_PIN_I2C_SDA
#define APP_PIN_I2C_SCL CONFIG_KILN_PIN_I2C_SCL

/* XPT2046 touch controller (on the display module, shared SPI bus). */
#define APP_PIN_TOUCH_CS  CONFIG_KILN_PIN_TOUCH_CS
#define APP_PIN_TOUCH_IRQ CONFIG_KILN_PIN_TOUCH_IRQ
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

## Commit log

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2026-02-19 feat: implement commercial-parity feature set (v2.0.0)
    Firmware:
    - Cone fire mode: full Orton table (cone 022–14), three speeds, optional
    preheat and slow-cool segments generated via new cone_table component
    - Safety: kiln-not-rising error (10 °C / 15 min), rate-of-rise runaway
    detection (>2× programmed rate), alarm GPIO with beep patterns, vent
    GPIO active below 700 °C during firing
    - Firing engine: skip-segment command, delay-start countdown, infinite
    hold (holdTime=0), TC offset calibration, element-hours accumulation
    - Firing history: SPIFFS JSON records + 1-min CSV temperature traces,
    20-record ring buffer (new history component)
    - REST API expanded to 25 endpoints: cone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
    [partitions.csv]
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2026-02-19 fix(build): resolve firmware build errors
    - Extract app_config.h into its own component to break circular
    dependency between main and web_server
    - Use PRIu32 format specifier in api_handlers.c for uint32_t on Xtensa
    [app_config.h]
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2026-02-20 feat(display): replace raw LCD rendering with LVGL-based UI
    Replace the primitive fill_rect() status bar display with a full LVGL 9.x
    integration featuring 4 navigable screens (Home, Chart, Profiles, Firing),
    Montserrat fonts at 14/20/28px, double-buffered DMA rendering at ~30 FPS,
    and 3-button encoder input for screen navigation.
    [app_config.h, display_init.c, main.c]
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2026-03-28 fix: resolve clang-tidy findings across all components
    Add braces around single-line if/else bodies (readability-braces-around-statements),
    remove redundant ternary in cone_table, and minor cleanups flagged by static analysis.
    [cone_table.c, display_init.c, safety.c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]
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2026-03-30 docs: improve README with features, BOM, screenshots, and LCD simulator
    Add project description, feature list, bill of materials with safety
    warning, and fix wiring table errors (ST7735→ST7796S, SSR GPIO 4→17).
    Include screenshots of the web dashboard, LVGL LCD screens, and iOS app.
    Add standalone LVGL SDL2 simulator (simulator/) that renders the actual
    LCD UI screens on desktop for development and automated screenshot capture.
    [main.c]
2026-03-30 refactor: deduplicate code and remove dead code across firmware, web UI, and iOS
    - Extract shared firing_status_to_string(), profile_to_json/from_json helpers
    - Extract begin_firing(), complete_firing(), load_profile_index() helpers
    - Use send_json() in 3 handlers that were inlining it
    - Consolidate constants to use app_config.h (max temp, PID defaults, SSR window, fault timeout)
    Web UI:
    - Create shared utils (time, download, error, profile) replacing 15+ inline duplications
    - Fix broken calculateEstimatedDuration calls to use memoized value
    - Remove redundant connected state, dead files, and unused props
    iOS:
    - Remove dead code (unused API methods, view models, shared views, CSV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
    [main.c, safety.c]
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2026-04-01 feat: add web-based Wi-Fi configuration via API
    Add NVS-backed Wi-Fi credential storage so users can configure Wi-Fi
    through the web UI instead of requiring compile-time credentials.
    Credentials are loaded from NVS first, falling back to Kconfig defines.
    New endpoints:
    - GET /api/v1/wifi — connection status and saved SSID
    - POST /api/v1/wifi — save SSID/password (takes effect after reboot)
    - DELETE /api/v1/wifi — clear saved credentials (reverts to AP mode)
    [main.c]
2026-04-01 feat: add OTA rollback support and status/rollback API endpoints
    Enable CONFIG_BOOTLOADER_APP_ROLLBACK_ENABLE so that after an OTA
    update, the new firmware boots in pending-verify state. If it fails
    to initialize, the bootloader automatically reverts to the previous
    firmware. On successful boot, app_main confirms the firmware as valid.
    - GET /api/v1/ota/status — partition info, version, rollback availability
    - POST /api/v1/ota/rollback — manually revert to previous firmware
    - POST /api/v1/ota/confirm — explicitly confirm pending firmware
    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
    [main.c]
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2026-04-19 feat: unified git-tag versioning for firmware, web UI, and iOS
    Replace the hardcoded APP_FIRMWARE_VERSION macro with git-describe-based
    versioning that flows through all build surfaces. A single scripts/version.sh
    produces the version string, consumed by CMake (PROJECT_VER → esp_app_desc),
    Vite (define → __APP_VERSION__), xcodegen (env vars), and CI workflows.
    Adds a release.yml workflow that publishes firmware artifacts on tag push.
    [app_config.h, main.c]
2026-04-21 feat(input): replace 3-button encoder with 5-way nav switch
    Adds dedicated Left (GPIO 1) and Right (GPIO 2) inputs that cycle screens
    directly, superseding the 800 ms long-press-Select gesture. Up/Down/Center
    keep their encoder semantics so list focus and button-matrix activation
    work unchanged. Pin choices avoid all ESP32-S3 JTAG pins (USB-JTAG on
    19/20, external on 39-42). Perfboard and wiring SVGs regenerated to
    match the new 6-pin header.
    [app_config.h, display_init.c]
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2026-04-25 implement 5-way switch; fix display rgb; increase stack size to fix crash
    [app_config.h, display_init.c]
2026-04-27 feat(display): redesign LCD UI as adaptive single-screen dashboard
    Replaces the 4-screen carousel (home/chart/profiles/firing) with a
    single dashboard whose layout adapts to firing status (idle/active/
    paused/complete/error/autotune). All actions are handled via
    SELECT-driven modals on lv_layer_top().
    - dashboard.c: state-driven layout switching, live chart with planned
    profile overlay, numeric column (temp/target/elapsed/remaining)
    - modal.c: shared open/close with LVGL focus-group swap
    - modal_profile_picker.c: profile list + start-confirm
    - modal_action_menu.c: pause/resume/skip/stop + stop-confirm
    - firing_engine: add firing_planned_temp_at() for chart overlay
    - Removes ui_screen_{hom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
    [dashboard.c, display_init.c, main.c]
2026-04-27 feat(display): horizontal-nav mode for modals; refresh CLAUDE.md/AGENTS.md
    Adds dashboard_modal_use_horizontal_nav() so a modal builder can opt into
    LEFT/RIGHT moving focus within the modal group instead of closing the
    frame. Profile-picker confirm step uses it (replacing the textual hint),
    and display_task routes both LEFT and RIGHT through the modal when one
    is active. Resets per-build.
    Also updates CLAUDE.md and AGENTS.md to match current hardware and UI:
    correct LCD pin map, 5-way nav switch input, single adaptive dashboard
    + modal stack architecture, refreshed UI_COLOR_* token table.
    [modal.c]
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2026-04-28 Move WS broadcast off esp_timer; decouple alarm/webhook/vent
    The esp_timer callback called ws_broadcast_status() directly, which on a
    state transition could block the shared esp_timer task for ~7s
    (safety_trigger_alarm vTaskDelay up to 2.1s + 5s webhook POST timeout),
    stalling every other timer in the system.
    - ws_broadcast_task: new worker driven by xTaskNotifyGive from the timer.
    ws_broadcast_status() is now pure WS work.
    - notification_task: drains a new firing-event queue from the firing
    engine and runs alarm + webhook off the firing/safety hot path.
    - Vent control moves into firing_task per safety.h's own header comment.
    - Status-transition detection moves into the firing engine it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
    [main.c]
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2026-04-28 Skip status_led_task when LED init fails
    If led_strip_new_rmt_device fails, s_strip stays NULL and the task
    would hammer the driver with NULL-handle calls every 250ms. Mirror
    the display gating so the task is only created on successful init.
    [main.c]
2026-04-28 Fix cppcheck CI failures
    Guard build_view_complete against NULL prog (cppcheck flow analysis flags
    the dashboard_create path that passes NULL to switch_view), and mark
    delay_item as const since only valuedouble is read.
    [dashboard.c]
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2026-04-30 Introduce LVGL theme + shared widget helpers
    Custom theme registered on the display via lv_display_set_theme()
    applies static lv_style_t defaults by widget class: screen baseline
    (black bg, white text, font), plain panels (transparent, chrome-free),
    buttons (radius + focused outline ring), lists and list buttons (with
    focused state), and chart parts (frame, grid, items, indicator). The
    theme replaces the simple theme that was compiled in but never
    initialized.
    ui_widgets.{h,c} consolidates the three duplicated make_label and two
    duplicated make_button helpers into shared ui_make_label /
    ui_make_button / ui_make_separator. No call sites are migrated in this
    commit; subsequent commits delete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
    [display_init.c]
2026-04-30 Migrate dashboard.c to themed widgets
    Drop the local make_label helper in favor of ui_make_label, replace
    the inlined separator boilerplate with ui_make_separator, and remove
    inline style calls now provided by the theme: bg/border/radius/pad
    zeroing on s_screen, s_status_bar, s_select_trap, the content area,
    and the chart (bg, border, radius, grid color, item line width, point
    markers). Status-bar bg color and the runtime status-driven color
    updates remain inline because they're per-instance dynamic state.
    [dashboard.c]
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2026-04-30 Clear latched emergency stop on new firing start
    A NOT_RISING or RUNAWAY trip set the SAFETY_BIT_EMERGENCY_STOP event
    bit but nothing ever cleared it, so the next FIRING_CMD_START was
    accepted and then immediately re-tripped on the following firing_task
    tick, kicking the user back to the e-stop screen. The dashboard's
    profile cache also wasn't refreshed across error→active→error
    transitions, so the prior profile name kept showing on the new error.
    Now FIRING_CMD_START calls safety_clear_emergency() after validation;
    safety_task re-latches within 500 ms if a real fault (TC fault,
    over-temp) persists. The dashboard re-runs enter_profile_view()
    whenever prog->profile_id changes, not just o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
    [dashboard.c]
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2026-04-30 Switch dashboard palette to light theme
    The splash was already light; the dashboard now matches it. Adds
    UI_COLOR_ON_ACCENT for text on warm-accent surfaces (orange Start/Resume,
    focused list item, status pill default) since UI_COLOR_BG can no longer
    pull double duty. status_text_color() uses absolute colors so it
    survives future palette changes; destructive Stop buttons keep
    white-on-red explicitly.
    [dashboard.c]
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2026-04-30 Extract shared JSON + body-parsing helpers
    Collapses three patterns of duplication: history outcome ↔ string mapping
    (now history_outcome_to_string), the firing-progress JSON serializer
    (json_add_progress_fields, shared by the REST status endpoint and the
    WebSocket broadcast so they can't drift), and the read_body+cJSON_Parse
    boilerplate at seven POST handlers (now parse_body_json).
    The WebSocket payload now also carries profileId; clients ignore unknown
    fields, and unifying the serializer prevents future schema drift between
    HTTP and WS.
    [dashboard.c]
2026-05-02 Make joystick a pure navigator; add explicit Cancel buttons
    LEFT used to mean "close modal" except in confirm dialogs that called
    dashboard_modal_use_horizontal_nav(), where it instead moved focus.
    That per-screen mode toggle was the main awkwardness — users had to
    learn which dialogs treated LEFT as escape vs. focus.
    Now: every dismissible modal has a visible Cancel button, and the
    5-way switch only ever moves focus or activates the focused widget.
    LEFT/RIGHT alias UP/DOWN so the user doesn't need to know which axis
    a layout uses.
    - modal.c/h: drop horizontal_nav mode; nav_left/right always do
    focus_prev/next on g_modal_group.
    - display_task.c: route_lr_focus() (renamed from check_lef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
    [modal.c]
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2026-05-03 Acknowledge ERROR state before opening profile picker
    SELECT on the firing-stopped (ERROR) screen opened the profile picker
    without transitioning the firing engine out of ERROR, so cancelling the
    picker dropped the user back onto the ERROR screen — and SELECT/cancel
    became an inescapable loop. Send FIRING_CMD_STOP first so the engine
    moves to IDLE; cancelling the picker now lands on the idle dashboard.
    [dashboard.c]
2026-05-03 Add Select-profile button on idle; drop SELECT-to-X hints
    Replace the "SELECT to start a firing" text on the idle dashboard with a
    visible primary button that opens the profile picker, and hand encoder
    focus from the invisible select trap to the button while the idle view
    is mounted (destroy_content re-parks focus on the trap on exit). Shift
    the last-firing summary up to clear the new button.
    Drop the analogous "SELECT to ..." hints from the active, complete, and
    error views and from both action-menu modals — the affordance is
    obvious from the focused widget.
    [dashboard.c]
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2026-05-06 Drive piezo alarm with 4 kHz LEDC tone
    The alarm pin was driven with raw GPIO levels, which a piezo buzzer
    can't translate into audible sound. Configure LEDC on the alarm pin to
    emit a 4 kHz square wave (matched to the buzzer's resonance during
    bench testing) and gate the tone on/off through the existing beep
    patterns. Vent stays GPIO since it's a relay.
    Also gitignore sdkconfig.old (build-tool backup that gets regenerated
    whenever sdkconfig is rewritten).
    [safety.c]
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2026-05-14 Add screenshot regression tests (Layer 4)
    The SDL simulator now has a --diff mode that re-renders every state preset
    and modal, compares it pixel-by-pixel against the committed baseline PNG,
    and exits non-zero on mismatch. Allowed deltas are tight (max channel diff
    ≤ 12, mean abs diff ≤ 0.60) so AA jitter passes but a moved widget, color
    change, or font swap fails. Actual renders are dumped to
    docs/screenshots/actual/lcd-*.png (gitignored) so CI can upload them as
    artifacts for inspection.
    Shared scene loop drives both --screenshot and --diff so they stay
    byte-perfectly aligned (same preset order, same modal navigation, same
    pump_frames counts).
    CI: new ui-screenshots job on ubuntu-lat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
    [dashboard.c, main.c]
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2026-05-14 Fix LCD UI overlap and readability issues
    - Modal root: LV_OPA_90 -> LV_OPA_COVER so the dashboard no longer bleeds
    through under every modal (start-confirm, stop-confirm, actions, picker).
    - Stop/start confirm modals: push action buttons from offset_y=30 to 50 so
    the 60px-tall buttons stop kissing the body label's descenders.
    - Profile picker: shrink list to 160px (exactly two rows) and start it
    10px higher; the partial third row that used to peek behind Cancel is
    fully clipped now.
    - Error view: wrap the description label at UI_LCD_W - 40 with center
    alignment, and shift the labels below it down 20px so they have room
    if the description wraps to two lines.
    - Active/autotune vie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
    [dashboard.c, modal.c]
2026-05-15 Update screenshot baselines + fix simulator top-layer capture
    The opacity + layout changes intentionally diverge from the prior
    goldens, so regenerate the 6 affected baselines:
    - lcd-modal-{picker,start-confirm,actions,stop-confirm}.png — no more
    dashboard bleed-through.
    - lcd-error.png — wrapped description, shifted lower labels.
    - lcd-autotune.png — REMAINING line hidden.
    Also fix a simulator capture bug exposed by LV_OPA_COVER: read_current_pixels
    only invalidated lv_screen_active(), so a fully-opaque modal on lv_layer_top
    stayed clean across the forced refresh and the screen redraw painted over
    it (modal-actions came out blank white). Invalidate lv_layer_top alongside
    the screen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
    [main.c]
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2026-05-16 Add splash/action-menu screenshots and fix doubled-v version string
    Simulator screenshot coverage:
    - Render the boot splash via splash.c (added to the sim build with a
    stub esp_app_desc.h) and the PAUSED/AUTOTUNE action-menu variants.
    - Warm up the renderer before the first capture, which otherwise comes
    back blank.
    Version string fix:
    - scripts/version.sh emits `git describe` of v* tags, so the string
    already carries a leading 'v'. splash.c and the boot log both
    re-prepended one, producing "vv2.0.0". Render the version verbatim.
    [main.c]
2026-05-16 Add GitHub-backed OTA firmware updates
    Devices can now discover and install new firmware from GitHub Releases
    instead of relying solely on a manual binary upload. The release workflow
    publishes a manifest.json; firmware fetches it over HTTPS, streams the
    binary into the inactive OTA slot with SHA-256 verification, and reboots.
    A confirm task cancels rollback only after a healthy-uptime window, so a
    bad image reverts automatically. Updates are refused while a firing is
    active. Web UI and iOS app gain a "Check for Updates" flow; manual upload
    is retained on both.
    [main.c]
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2026-05-28 display: DMA-capable buffer alloc, lower queue depth, encoder auto-repeat
    - Replace static BSS draw buffers with heap_caps_aligned_alloc using
    MALLOC_CAP_DMA|MALLOC_CAP_INTERNAL so the placement constraint is
    explicit rather than incidental to where BSS lands.
    - DRAW_BUF_LINES 40 -> 30. Still above LVGL's 1/10-of-screen floor
    (480x30x2 B = 28800 B); frees ~19 KB internal SRAM.
    - trans_queue_depth 10 -> 4. Partial + double-buffer keeps at most two
    transfers in flight; 4 is comfortable headroom.
    - Encoder long-press auto-repeat: holding UP/DOWN now keeps scrolling
    the focus group (400 ms initial delay, 80 ms cadence) instead of
    requiring one click per step. Useful in the profile pi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
    [display_init.c]
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2026-05-28 dashboard: skip status-bar repaint when status hasn't changed
    dashboard_update fires every 500 ms and was unconditionally re-applying
    the status-bar bg color, both label text colors, and the status label
    text. Each lv_obj_set_style_* / lv_label_set_text marks the object dirty
    and forces a partial-area redraw + SPI flush of that region — pointless
    when prog->status is unchanged, which is the common case during a long
    ramp or hold.
    Gate the writes on a sentinel-initialized s_prev_status and reset it in
    dashboard_create so a recreated dashboard repaints from scratch.
    [dashboard.c]
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2026-06-03 feat(units): default to Fahrenheit and honor the unit preference in both UIs
    The temp_unit preference was already plumbed end-to-end (NVS, API, web
    Settings dropdown) but was purely cosmetic — every readout hard-coded °C.
    Wire the preference through both the embedded LVGL display and the React
    web UI, and flip the default from Celsius to Fahrenheit.
    Celsius remains the single internal source of truth (thermocouple, firing
    engine, safety, stored profiles, NVS, and the JSON API are unchanged);
    conversion happens only at the presentation boundary.
    - firing_engine: default temp_unit 'C' -> 'F'; add firing_engine_get_temp_unit()
    - ui_common.h: ui_temp_value()/ui_temp_rate()/ui_temp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
    [dashboard.c]
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2026-06-17 fix(safety): close four safety-critical kiln-control gaps
    Addresses the four safety-relevant findings from the codebase review:
    - #62 Thermocouple fault gate: firing_tick now holds the SSR off when the
    current reading is faulted instead of feeding the MAX31855's 0°C fault value
    into the PID, which previously commanded full power until safety_task's 5 s
    timeout escalated.
    - #63 Control-loop heartbeat: safety_set_ssr() stamps a timestamp each firing
    tick; safety_task forces the SSR low (and trips an emergency stop if heat was
    being commanded) when the heartbeat goes stale, so a wedged firing task can no
    longer leave the element latched on.
    - #64 Pause clock freeze: on resume the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
    [main.c, safety.c]
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2026-06-17 fix(pid,safety): correct autotune gains and SSR duty resolution
    - #77 Autotune: the Ziegler-Nichols ultimate gain uses the relay *half*-
    amplitude d, and this relay swings 0..1 (d = 0.5), so Ku = 4d/(πa) = 2/(πa).
    The previous 4.0 numerator treated the full swing as the half-amplitude and
    doubled every computed gain. Also restart the timeout budget when relay
    cycling begins so a long heat-up to a high setpoint no longer consumes the
    window before the 5 cycles can complete.
    - #76 SSR resolution: a periodic 10 Hz timer now re-applies the time-
    proportional window from the stored duty, instead of only re-evaluating it at
    the 1 Hz control tick — which sampled the 2 s window at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
    [safety.c]
2026-06-18 fix(engine,safety): attribute trip causes, fix event payloads, guard delay start
    - #72 Specific error codes: the safety module now records why an emergency
    stop tripped (safety_trip_cause_t: TC_FAULT / OVER_TEMP / OTHER), and the
    firing engine maps that onto FIRING_ERR_TC_FAULT / FIRING_ERR_OVER_TEMP
    instead of a generic FIRING_ERR_EMERGENCY_STOP — so the dashboard's specific
    "Thermocouple disconnected" / "Over temperature" messages and the API's
    lastErrorCode now reflect the real cause. Engine-initiated trips (not-rising,
    runaway) still set their own code first.
    - #73 Webhook/event payload: firing_event_t now carries the human-readable
    profile name (notification_task passes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
    [safety.c]
2026-06-22 fix(net,web,display): SNTP start, log throttle, export parsing, doc/count drift
    Four small, low-risk cleanups from the review:
    - #79 SNTP: start the SNTP poller unconditionally instead of gating it on
    !AP-mode at boot. A STA that associates after the 30 s boot wait now still
    gets the clock set (firing-history timestamps were stuck at 1970); in pure AP
    mode it just retries harmlessly with no route.
    - #80 Log spam: dashboard_tick_cb fired an INFO line every 500 ms (~170k/day).
    Throttle to once per minute or on a status change.
    - #84 Profile export: handle_get_profile parsed the "/export" suffix and query
    string out of a buffer already truncated to FIRING_ID_LEN, so IDs near the
    le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
    [main.c]
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2026-07-20 Add KiCad PCB design for single-board kiln controller
    Full KiCad 9 project under hardware/kicad/: schematic + routed 2-layer
    100x80mm board built around an ESP32-S3-WROOM-1 module (not a bare chip),
    with every part hand-solderable (0805/SOIC/SOT/THT, no BGA/QFN):
    - MAX31855KASA+ thermocouple amp with K-type screw terminal (T- grounded,
    10nF input filter), sharing the firmware's SPI2 bus
    - Boot-safe low-side SSR drive (AO3400A + gate pulldown) on a 5V loop
    screw terminal, with drive-state LED
    - 5V screw-terminal or USB-C power, SS34 ORing/reverse protection,
    AMS1117-3.3 regulator
    - USB-C native-USB flashing (CC pulldowns, USBLC6 ESD), RESET/BOOT buttons
    - Headers matching the existing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
    [bisque-controller.kicad_pcb, bisque-controller.kicad_sch]
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2026-07-21 Replace pin headers with Molex KK-254 friction-lock headers
    J5 (display), J6 (nav switch) and J7 (aux) switch from plain 2.54mm pin
    headers to Molex KK-254 AE-6410 friction-lock headers, so each mating
    housing is polarized and cannot be plugged in reversed. Pin positions are
    unchanged (same 2.54mm row); the board was re-routed around the larger
    oval pads and re-verified (ALL CHECKS PASS). Silk pin-name labels moved
    out from under the deeper connector bodies, 3D renders updated with the
    friction-lock body shape, BOM lists the headers plus mating housings and
    crimp terminals.
    Claude-Session: https://claude.ai/code/session_017JbapEYPC7fC91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
    [bisque-controller.kicad_pcb, bisque-controller.kicad_sch]
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

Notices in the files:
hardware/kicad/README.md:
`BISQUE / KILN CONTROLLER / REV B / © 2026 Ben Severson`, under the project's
